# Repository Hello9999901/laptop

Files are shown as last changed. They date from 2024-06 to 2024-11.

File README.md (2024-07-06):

# anyon e

*also stylized as anyon_e*

A highly integrated, high end, open source laptop.

Mission: to disprove the idea that technology is either repairable and open or integrated and closed.

#

#### Planned Features:

- RK3588 SoC Motherboard
  - CM3588-based, up to 32GB of DDR5 2400MHz RAM
  - USB-C USB3.1 Gen 1 with DisplayPort
  - Separate USB-C PD controller and port
  - HDMI Input (maybe)
  - RP2040 embedded controller
- World's thinnest wireless mechanical keyboard
  - nRF52840 SoC
  - Cherry ULP switches
- 4K AMOLED 13.3" display
  - 330 pixels per inch
- Field-Oriented-Control BLDC input
- High accuracy trackpad
  - Azoteq Win 11 certified
- High performance battery
  - High discharge/charge ~60Wh Li-Po battery pack
- Anodized aluminum CNC chassis

#### Unplanned Features:

- 3.5mm headphone port
  - hardware support complexity
- webcam/microphone
  - privacy and system complexity
  - minimize screen bezel size

#

*[ **an**-yon ]*

*exotic particles whose quantum statistics are neither bosonic nor fermionic.*[^1]

Integrated like bosons, distinct like fermions.

#

Thank you to the Phillips Exeter Academy Science Department for supporting this project.
*Non Sibi. Knowledge and Goodness. Youth From Every Quarter.* [^2]

[^1]: H. Bartolomei et al. ,Fractional statistics in anyon collisions.Science368,173-177(2020).DOI:10.1126/science.aaz5601

[^2]: Byran Huang's ('25) 2024-25 Fall Term Senior Project. Thank you to my advisors, Mr. Brad Robinson and Mr. Charles Mamolo.

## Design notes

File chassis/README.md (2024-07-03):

# Chassis

Designed in PTC Onshape using an Educational license.

https://cad.onshape.com/documents/a18bb6df7dbba66df24a7ec8/w/967d921e60c207e3b6f5cf7b/e/1f78a9387b17c2d178742295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

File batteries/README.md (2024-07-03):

# Batteries

https://www.batteryspace.com/polymerli-ionmodule37v4250mah157wh85arate-prewiredwithpcbpl5467100.aspx

15.7Wh, 100mm (3.9")  x 67mm (2.6") x 5.7mm (0.2")

4S system, providing a total capacity of 62.8 Wh with a theoretical peak power draw of 118.4W (3.7V * 4 * 8A)

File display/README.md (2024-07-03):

# Display

Using the ATNA33TP11 13.3" 4K AMOLED display from Samsung.

https://www.panelook.com/ATNA33TP11_Samsung_13.3_OLED_overview_59424.html

The datasheet is very difficult to acquire.

eDP 40 pin connector: IPEX 20455-040E

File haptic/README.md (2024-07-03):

# Haptic

BLDC haptic feedback like smartknob.

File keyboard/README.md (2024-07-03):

# Keyboard

nRF52840-based wireless mechanical keyboard with Cherry ULP switches.

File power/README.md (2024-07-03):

# Power

Separate power system because integration is high risk.

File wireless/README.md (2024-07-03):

# Wireless

Looking at Intel's AX210 or RTL8852BE, assuming M.2 E Key connection is functional.

https://us.rs-online.com/product/okdo/ra007-a8/74063355/

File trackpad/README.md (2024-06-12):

# PXM0057-401-S

[Purchase Link (discontinued)](https://www.mouser.com/ProductDetail/Azoteq/PXM0057-401-S)

EOL'ed series of trackpads/touchpads from Azoteq. All documents are archived from Azoteq.

[Framework 16 trackpads](https://frame.work/products/16-touchpad-module) currently seem to be the only other option.

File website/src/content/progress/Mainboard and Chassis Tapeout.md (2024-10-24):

---
title: "Mainboard and Chassis Tapeout"
hash: "Hello9999901/laptop/commit/2902150bbe53c2a607e23ed8757f1257ed1819de"
dateStart: "10/24/2024"
---

Mainboard V1.0 and chassis has been taped out to JLCPCB and JLCCNC respectively. Will receive parts in ~1.5 weeks.

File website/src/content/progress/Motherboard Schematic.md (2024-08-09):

---
title: "Motherboard Schematic"
hash: "Hello9999901/laptop/commit/7537e6f6f953aed19e3b554f8151d0d517349e46"
dateStart: "7/8/2024"
---

Using a combination of the CM3588 NAS SDK, Radxa 5B, and Cool-Pi laptop schematic and the RK3588 Design Guide (all sources in repo) for reference to create the motherboard schematic.

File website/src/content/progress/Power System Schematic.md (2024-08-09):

---
title: "Power System Schematic"
hash: "Hello9999901/laptop/commit/9d0cacac59adbbebdd309e441b76d96aae04a213"
dateStart: "7/1/2024"
---

Still a work in progress. It will use the most advanced chips I can develop with and hopefully have a RP2040 EC (embedded controller) for system monitoring or as a general purpose embedded MCU.

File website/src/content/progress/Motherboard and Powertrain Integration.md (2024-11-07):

---
title: "Motherboard and Powertrain Integration"
hash: "Hello9999901/laptop/"
dateStart: "11/2/2024"
---

After load testing the batteries at 3A for ~2h, I plugged the powertrain into the motherboard and evaluated all previous functionality.

The hall switch, speakers, and fan have also been evaluated to be functional.

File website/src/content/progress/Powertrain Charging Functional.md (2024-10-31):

---
title: "Powertrain Charging Functional"
hash: "Hello9999901/laptop/commit/7e120f42460bdfba6e477f5982cce70f7909ddb4"
dateStart: "10/31/2024"
---

After fixing some (many) mistakes with the board, the powertrain charged a battery pack to ~4.18V per cell as expected.

The problems include:

- Used N-MOS for BATFET instead of P-MOS
- Battery pack voltage joined with system power
- Charge/Discharge FETs on battery balancing IC non-functional

I will send a fixed board to production, but I'm not sure if it'll arrive in time for the term deadline.

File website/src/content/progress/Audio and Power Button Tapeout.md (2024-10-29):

---
title: "Audio and Power Button Board Tapeout"
hash: "Hello9999901/laptop/commit/680bf61ffe4f14e42e2d671e997a2c2274b41c56"
dateStart: "10/29/2024"
---

After a one-night crunch, I put the audio board (CM108 USB to 2x TPA2028 with the legendary CH32V003 MCU) and a simple power button board into production. Since they're two layer, JLC can do 24h PCB + 2-3 day assembly so they should arrive quite quickly!

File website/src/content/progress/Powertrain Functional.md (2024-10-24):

---
title: "Powertrain Functional"
hash: "Hello9999901/laptop/commit/7c3f3c577cd7447728fc4ebcd25b6b98cf7af491"
dateStart: "10/23/2024"
---

Powertrain V0.2 powered on and functioned as expected first-try! Software evaluation with PlatformIO proved effective with all I2C ICs and the ESP32-S3-MINI-1-N8 itself.

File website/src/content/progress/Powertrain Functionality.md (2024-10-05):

---
title: "Powertrain Hardware and Software Verification"
hash: "Hello9999901/laptop/commit/7dd1f4d1e0136dbfb9b8b690ecb96abea7383cab"
dateStart: "10/5/2024"
---

Fixes need to be made on the second revision of the powertrain. Namely, a higher performance DC-DC converter and redesigning the ESP32-S3 setup.
Using a Teensy 4.1 to accelerate development times, all three chips have been verified to function as expected. Further testing needs to be conducted with charger IC.

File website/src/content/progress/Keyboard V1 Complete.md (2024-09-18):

---
title: "Keyboard V1 Complete"
hash: "Hello9999901/zmk/commit/ae88a136d7643904b9689bf2e2431af29ef1ffbc"
dateStart: "9/17/2024"
---

After ~0.5mm acetal delrin were installed underneath the keycaps and plates glued with cyanoacrylate adhesive (superglue), all the keycaps press and travel as expected. The delrin provides a softer and smoother bottom-out and just a tiny bit less travel. I can type on the keyboard normally, but the sizing and actuations require more typing to break-in.

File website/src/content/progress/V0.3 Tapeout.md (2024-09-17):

---
title: "V0.3 Tapeout"
hash: "Hello9999901/laptop/commit/1f0a15ddb97392ed5f131d0902316a7e9edddad4"
dateStart: "9/16/2024"
---

V0.3 with improved fixes has been taped out. A major issue is that the low-profile Hirose connectors are out of stock, so the board will be 1.5mm thicker if this board is final (unlikely).

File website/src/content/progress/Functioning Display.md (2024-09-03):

---
title: "Functioning Display"
hash: "Hello9999901/zmk/commit/fdd6672159e983177fd62d12f2ffced35667086c"
dateStart: "9/2/2024"
---

In the end, it seems like the culprit of the non-functional display was the hardware. Using the exact same devicetree compile and surrounding hardware setup, I was able to get the display running. In particular, the difficulties were most likely in the high-speed signaling losses across the SoM, the Hirose connectors, the HDMI connector, and the transition to the "anyon_e display evaluation" breakout board. The difference between V1 and V2 Short was the use of a male HDMI connector and the shortest signaling traces possible. This eliminated the need for a male-male HDMI conversion between the boards and shortened the FR4 trace lengths by around 2cm. That is -20% change from the pervious length. However, it looks like brightness control must be done over PWM, as (unfortunately predicted) adjusting the voltage does not result in a change in brightness. In my measurements (assuming default output is the stated 400 nits), the max current draw is around 0.5A at 12V, so a PWM brightness system should be implementable.

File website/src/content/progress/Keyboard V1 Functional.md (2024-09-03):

---
title: "Keyboard V1 Functional"
hash: "Hello9999901/zmk/commit/ae88a136d7643904b9689bf2e2431af29ef1ffbc"
dateStart: "8/8/2024"
---

After battling Linux DeviceTree development for the past weekend, I'm happy to say I am fluent in DTS code (jokes).

Currently forked from Joshua Reik's modified ubuntu-linux kernel. After modifying the CM3588 DTS to support eDP1, link training is failing. Currently debugging.

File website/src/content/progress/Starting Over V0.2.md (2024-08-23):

---
title: "Starting Over V0.2"
hash: "Hello9999901/laptop/commit/8de2bc9e0074f80b906bef1af565acf0b877c5ee"
dateStart: "8/21/2024"
---

After the display evaluation, I think I have a much better handle on high-speed signaling especially in relation to the CM3588. This new motherboard revision will be a near-final layout and close to the tape-out design.

I am paying special attention the integrity, coupling, and EMC of the board, so I've made the bold move for a 6 layer stackup - (Signal, GND, Power, Power, GND, Signal). I might use the first power plane for low speed signaling since the power requirements aren't that high.

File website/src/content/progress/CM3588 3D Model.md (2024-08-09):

---
title: "CM3588 3D Model"
hash: "Hello9999901/laptop/commit/bdd2ba21b4a4451552f4995764e1e13cb89fd671"
dateStart: "7/7/2024"
---

Created two 3D models of the CM3588 (non plus) SoM (system on module):
    1. Nearly fully accurate STL in Blender using the DXFs provided by FriendlyElec
    2. A roughly accurate STEP file in Shapr3D using the DXFs provided by FriendlyElec

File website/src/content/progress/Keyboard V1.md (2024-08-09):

---
title: "Keyboard V1"
hash: "Hello9999901/laptop/commit/2ca9aab1f80719315530f4c532aef9cafec064c8"
dateStart: "7/15/2024"
---

Trying to keep the entire keyboard assembly to be under 6mm at its highest point. This required designing a custom "BPS" (battery protection system) board and slots in the main PCB to save on the height of the BPS itself.

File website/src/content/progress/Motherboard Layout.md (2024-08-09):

---
title: "Motherboard Layout"
hash: "Hello9999901/laptop/commit/065d56bcbf0afe930ac8a8ca5442cbb30772766b"
dateStart: "7/16/2024"
---

Starting the motherboard's PCB layout! It will be a long journey and I will definitely end up revising the schematic many times over.

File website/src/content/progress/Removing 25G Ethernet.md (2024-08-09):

---
title: "Removed 2.5G Ethernet + Subtracting 38mm from the SSD"
hash: "Hello9999901/laptop/commit/3718073a7b3cd8b09f7a54d581c9525380008b53"
dateStart: "7/28/2024"
---

I have put a lot of thought into the sizing and overall integration of the system. As I was designing today, I realized that unless I increase the overall lower chassis thickness to around 17mm, it is impossible to fit an Ethernet connector (height of the connector would be 11.8mm + 1.6mm from PCB = 13.4mm). My aim for the system is still a sleek, integrated, and low-profile design. Unfortunately, I understand why Apple only includes USB-C for connectivity now.

Another tradeoff: With the feature set in mind, a 2280 SSD simply would not fit the vertical requirements. The exact reason is complicated: the keyboard limits the maximum height of the heatsink, meaning the heatpipes have to extend horizontally. The orientation of the CM3588 means that it is most optimal to route with tall components (SSD, wireless card, ribbon cables, etc.) all around it (rather than on one side). It is not that big of a loss, since it will still support 2242 and 2230 SSDs. The PCIe 3.0x4 is limited to 4GB/s, and the newest small-form-factor SSDs are much higher speed and will not be the performance bottleneck.

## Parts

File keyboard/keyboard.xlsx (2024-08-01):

Reference | Qty | Value | DNP | Exclude from BOM | Exclude from Board | Footprint | LCSC
C1,C4,C13,C19 | 4 | 4.7uF |  |  |  | Capacitor_SMD:C_0402_1005Metric | C23733
C2,C14,C15,C20 | 4 | 1uF |  |  |  | Capacitor_SMD:C_0402_1005Metric | C52923
C3 | 1 | 47nF |  |  |  | Capacitor_SMD:C_0402_1005Metric | C272875
C5 | 1 | 1nF |  |  |  | Capacitor_SMD:C_0402_1005Metric | C1523
C6 | 1 | 100pF |  |  |  | Capacitor_SMD:C_0402_1005Metric | C1546
C7,C16,C17,C18 | 4 | 100nF |  |  |  | Capacitor_SMD:C_0402_1005Metric | C307331
C8,C9,C21,C22 | 4 | 15pF |  |  |  | Capacitor_SMD:C_0402_1005Metric | C1548
C10 | 1 | 1.5pF |  |  |  | Capacitor_SMD:C_0402_1005Metric | C1552
C11,C12 | 2 | 1pF |  |  |  | Capacitor_SMD:C_0402_1005Metric | C1550
C23 | 1 | 10nF |  |  |  | Capacitor_SMD:C_0402_1005Metric | C15195
C24 | 1 | 1000pF/NC |  |  |  | Capacitor_SMD:C_0402_1005Metric
D1 | 1 | CHG |  |  |  | LED_SMD:LED_0603_1608Metric | C72038
D2 | 1 | B5819W SL |  |  |  | Diode_SMD:D_SOD-323 | C8598
D3 | 1 | BLUE |  |  |  | LED_SMD:LED_0603_1608Metric | C2290
D4,D5,D6,D7,D8,D9,D10,D11,D12,D13,D14,D15,D16,D18,D19,D20,D21,D22,D23,D24,D25,D26,D27,D28,D29,D30,D31,D32,D33,D34,D35,D36,D37,D38,D39,D40,D41,D42,D43,D44,D45,D46,D47,D48,D49,D50,D51,D52,D53,D54,D55,D56,D57,D58,D59,D60,D61,D62,D63,D64,D65,D66,D67,D68,D69,D70,D71,D72,D73,D74,D75,D76,D77,D78,D79,D80,D81,D82 | 78 | D |  |  |  | Diode_SMD:D_SOD-523 | C7420320
K1 | 1 | Esc |  |  |  | Cherry_ULP:Cherry_ULP_SMD
K2 | 1 | F1 |  |  |  | Cherry_ULP:Cherry_ULP_SMD
K3 | 1 | F2 |  |  |  | Cherry_ULP:Cherry_ULP_SMD
K4 | 1 | F3 |  |  |  | Cherry_ULP:Cherry_ULP_SMD
K5 | 1 | F4 |  |  |  | Cherry_ULP:Cherry_ULP_SMD
K6 | 1 | F5 |  |  |  | Cherry_ULP:Cherry_ULP_SMD
K7 | 1 | F6 |  |  |  | Cherry_ULP:Cherry_ULP_SMD
K8 | 1 | F7 |  |  |  | Cherry_ULP:Cherry_ULP_SMD
K9 | 1 | F8 |  |  |  | Cherry_ULP:Cherry_ULP_SMD
K10 | 1 | F9 |  |  |  | Cherry_ULP:Cherry_ULP_SMD
K11 | 1 | F10 |  |  |  | Cherry_ULP:Cherry_ULP_SMD
K12 | 1 | F11 |  |  |  | Cherry_ULP:Cherry_ULP_SMD
K13 | 1 | F12 |  |  |  | Cherry_ULP:Cherry_ULP_SMD
K15 | 1 | ~~,` |  |  |  | Cherry_ULP:Cherry_ULP_SMD
K16 | 1 | !,1 |  |  |  | Cherry_ULP:Cherry_ULP_SMD
K17 | 1 | @,2 |  |  |  | Cherry_ULP:Cherry_ULP_SMD
K18 | 1 | #,3 |  |  |  | Cherry_ULP:Cherry_ULP_SMD
K19 | 1 | $,4 |  |  |  | Cherry_ULP:Cherry_ULP_SMD
K20 | 1 | %,5 |  |  |  | Cherry_ULP:Cherry_ULP_SMD
K21 | 1 | ^,6 |  |  |  | Cherry_ULP:Cherry_ULP_SMD
K22 | 1 | &,7 |  |  |  | Cherry_ULP:Cherry_ULP_SMD
K23 | 1 | *,8 |  |  |  | Cherry_ULP:Cherry_ULP_SMD
K24 | 1 | (,9 |  |  |  | Cherry_ULP:Cherry_ULP_SMD
K25 | 1 | ),0 |  |  |  | Cherry_ULP:Cherry_ULP_SMD
K26 | 1 | _,- |  |  |  | Cherry_ULP:Cherry_ULP_SMD
K27 | 1 | +,= |  |  |  | Cherry_ULP:Cherry_ULP_SMD
K28 | 1 | Backspace |  |  |  | Cherry_ULP:Cherry_ULP_SMD
K29 | 1 | Tab |  |  |  | Cherry_ULP:Cherry_ULP_SMD
K30 | 1 | Q |  |  |  | Cherry_ULP:Cherry_ULP_SMD
K31 | 1 | W |  |  |  | Cherry_ULP:Cherry_ULP_SMD
K32 | 1 | E |  |  |  | Cherry_ULP:Cherry_ULP_SMD
K33 | 1 | R |  |  |  | Cherry_ULP:Cherry_ULP_SMD
K34 | 1 | T |  |  |  | Cherry_ULP:Cherry_ULP_SMD
K35 | 1 | Y |  |  |  | Cherry_ULP:Cherry_ULP_SMD
K36 | 1 | U |  |  |  | Cherry_ULP:Cherry_ULP_SMD
K37 | 1 | I |  |  |  | Cherry_ULP:Cherry_ULP_SMD
K38 | 1 | O |  |  |  | Cherry_ULP:Cherry_ULP_SMD
K39 | 1 | P |  |  |  | Cherry_ULP:Cherry_ULP_SMD
K40 | 1 | {,[ |  |  |  | Cherry_ULP:Cherry_ULP_SMD
K41 | 1 | },] |  |  |  | Cherry_ULP:Cherry_ULP_SMD
K42 | 1 | |,\ |  |  |  | Cherry_ULP:Cherry_ULP_SMD
K43 | 1 | Caps Lock |  |  |  | Cherry_ULP:Cherry_ULP_SMD
K44 | 1 | A |  |  |  | Cherry_ULP:Cherry_ULP_SMD
K45 | 1 | S |  |  |  | Cherry_ULP:Cherry_ULP_SMD
K46 | 1 | D |  |  |  | Cherry_ULP:Cherry_ULP_SMD
K47 | 1 | F |  |  |  | Cherry_ULP:Cherry_ULP_SMD
K48 | 1 | G |  |  |  | Cherry_ULP:Cherry_ULP_SMD
K49 | 1 | H |  |  |  | Cherry_ULP:Cherry_ULP_SMD
K50 | 1 | J |  |  |  | Cherry_ULP:Cherry_ULP_SMD
K51 | 1 | K |  |  |  | Cherry_ULP:Cherry_ULP_SMD
K52 | 1 | L |  |  |  | Cherry_ULP:Cherry_ULP_SMD
K53 | 1 | :,; |  |  |  | Cherry_ULP:Cherry_ULP_SMD
K54 | 1 | ",' |  |  |  | Cherry_ULP:Cherry_ULP_SMD
K55 | 1 | Enter |  |  |  | Cherry_ULP:Cherry_ULP_SMD
K56,K68 | 2 | Shift |  |  |  | Cherry_ULP:Cherry_ULP_SMD
K57 | 1 | Z |  |  |  | Cherry_ULP:Cherry_ULP_SMD
K58 | 1 | X |  |  |  | Cherry_ULP:Cherry_ULP_SMD
K59 | 1 | C |  |  |  | Cherry_ULP:Cherry_ULP_SMD
K60 | 1 | V |  |  |  | Cherry_ULP:Cherry_ULP_SMD
K61 | 1 | B |  |  |  | Cherry_ULP:Cherry_ULP_SMD
K62 | 1 | N |  |  |  | Cherry_ULP:Cherry_ULP_SMD
K63 | 1 | M |  |  |  | Cherry_ULP:Cherry_ULP_SMD
K64 | 1 | <,, |  |  |  | Cherry_ULP:Cherry_ULP_SMD
K65 | 1 | >,. |  |  |  | Cherry_ULP:Cherry_ULP_SMD
K66 | 1 | ?,/ |  |  |  | Cherry_ULP:Cherry_ULP_SMD
K67 | 1 | ‚Üë |  |  |  | Cherry_ULP:Cherry_ULP_SMD
K69 | 1 | Fn |  |  |  | Cherry_ULP:Cherry_ULP_SMD
K70 | 1 | Ctrl |  |  |  | Cherry_ULP:Cherry_ULP_SMD
K71,K76 | 2 | Alt |  |  |  | Cherry_ULP:Cherry_ULP_SMD
K72,K75 | 2 | Meta |  |  |  | Cherry_ULP:Cherry_ULP_SMD
K73,K74 | 2 | Space |  |  |  | Cherry_ULP:Cherry_ULP_SMD
K77 | 1 | ‚Üê |  |  |  | Cherry_ULP:Cherry_ULP_SMD
K78 | 1 | ‚Üì |  |  |  | Cherry_ULP:Cherry_ULP_SMD
K79 | 1 | ‚Üí |  |  |  | Cherry_ULP:Cherry_ULP_SMD
L1 | 1 | 15nH |  |  |  | Inductor_SMD:L_0402_1005Metric | C27143
L2,L3 | 2 | 10uH |  |  |  | Inductor_SMD:L_0603_1608Metric | C285968
L4 | 1 | 3.9nH |  |  |  | Inductor_SMD:L_0402_1005Metric | C14033
NT1 | 1 | NetTie_2 |  |  |  | Mikoto-Footprints:net-tie-2-tiny
P1 | 1 | USB-C |  |  |  | Connector_USB:USB_C_Receptacle_HRO_TYPE-C-31-M-12 | C165948
R1 | 1 | 0R |  |  |  | Resistor_SMD:R_0402_1005Metric | C17168
R2,R4 | 2 | 10k |  |  |  | Resistor_SMD:R_0402_1005Metric | C25744
R3 | 1 | 2.7k |  |  |  | Resistor_SMD:R_0603_1608Metric | C13167
R5 | 1 | 1.5k |  |  |  | Resistor_SMD:R_0402_1005Metric | C25867
R6,R7 | 2 | 5.1k |  |  |  | Resistor_SMD:R_0402_1005Metric | C25905
R8,R9 | 2 | 2M |  |  |  | Resistor_SMD:R_0603_1608Metric | C22976
R10 | 1 | 10M |  |  |  | Resistor_SMD:R_0402_1005Metric | C26082
R11 | 1 | 1M |  |  |  | Resistor_SMD:R_0402_1005Metric | C26083
SW1 | 1 | Reset |  |  |  | Button_Switch_SMD:SW_Push_1P1T_XKB_TS-1187A | C318884
U1 | 1 | BQ21040DBVR |  |  |  | BQ21040:SOT95P280X145-6N | C202311
U2 | 1 | nRF52840 |  |  |  | Package_DFN_QFN:Nordic_AQFN-73-1EP_7x7mm_P0.5mm | C190794
U3 | 1 | ESDR0502NMUTAG |  |  |  | Mikoto-Footprints:UDFN-6_1.2x1.0mm_P0.4mm | C327480
Y1 | 1 | 32.768 kHz |  |  |  | Crystal:Crystal_SMD_2012-2Pin_2.0x1.2mm | C99009
Y2 | 1 | 32MHz |  |  |  | Crystal:Crystal_SMD_2016-4Pin_2.0x1.6mm | C2965584

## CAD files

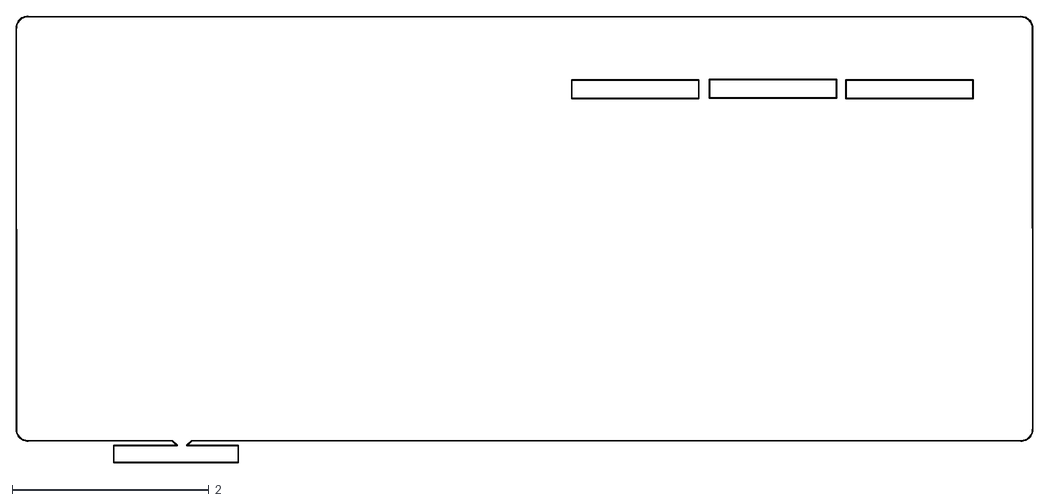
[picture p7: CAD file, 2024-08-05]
keyboard/dxf/keyboard-Edge_Cuts.dxf
10.3 x 4.54

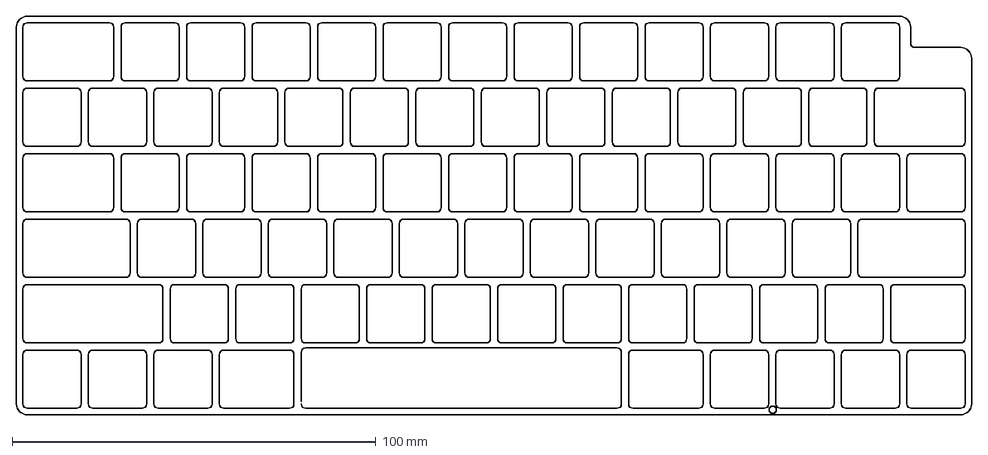
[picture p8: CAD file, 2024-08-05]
keyboard/plate files/anyon_e kb top AI TAPEOUT.dxf
262.5 x 109.5 mm

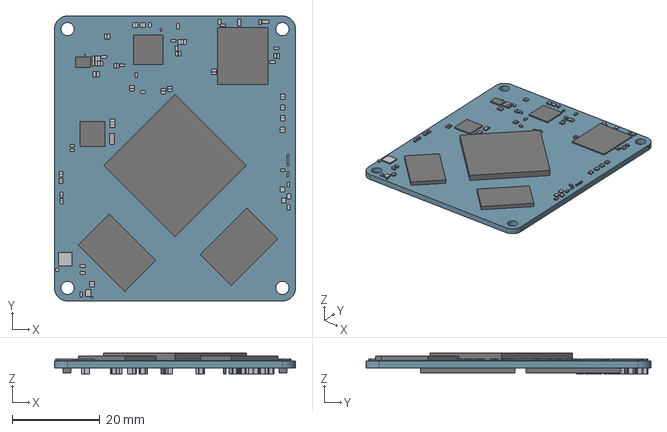
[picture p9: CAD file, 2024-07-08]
motherboard/CM3588 3D/CM3588_3D.step
55.0 x 65.0 x 4.70 mm

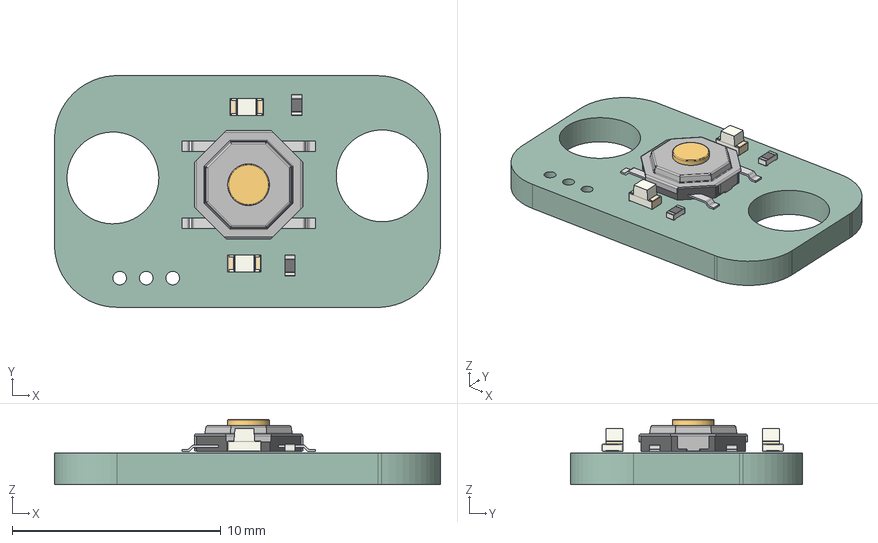
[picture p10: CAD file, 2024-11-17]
switch/switch.step
18.5 x 11.1 x 3.13 mm
SW_SPST_TL3342
R_0402_1005Metric x 2
LED_0603_1608Metric x 2
switch_PCB

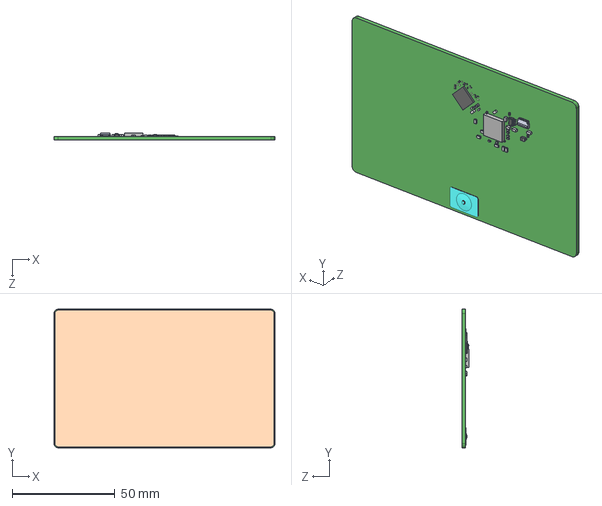
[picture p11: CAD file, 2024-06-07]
trackpad/pxm0057_101_201.STEP
107.3 x 67.3 x 3.47 mm

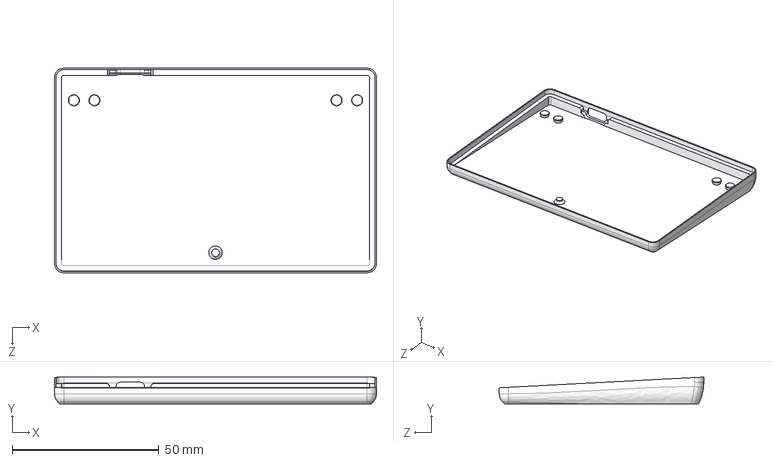
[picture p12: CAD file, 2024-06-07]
trackpad/PXM0057_Sales_Demo_3DPrinting/PXM0057_PTP_Type-C_Housing.STEP
109.7 x 9.16 x 69.7 mm

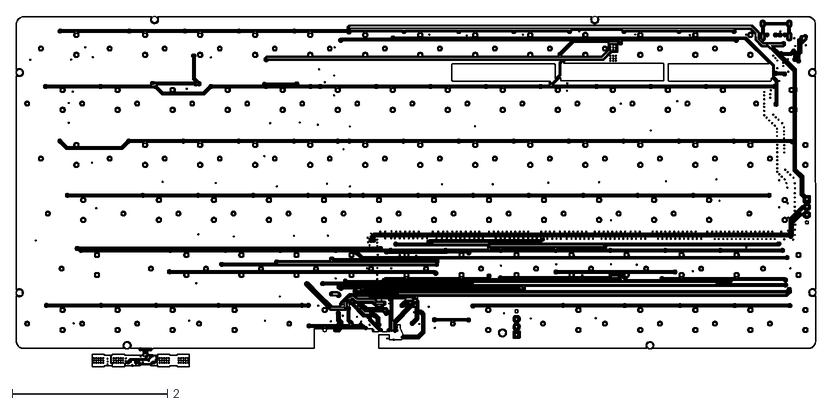
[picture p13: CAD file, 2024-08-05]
keyboard/dxf/keyboard-B_Cu.dxf
10.3 x 4.51

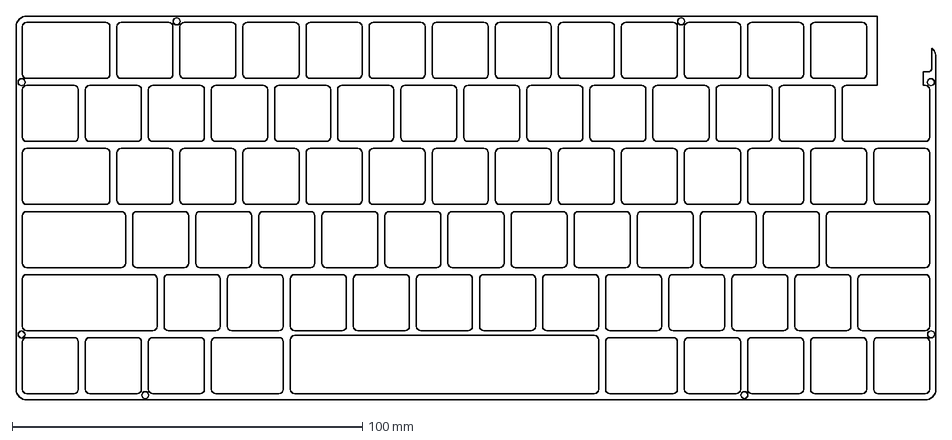
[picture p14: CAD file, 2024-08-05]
keyboard/plate files/anyon_e kb top center AI TAPEOUT.dxf
262.5 x 109.5 mm

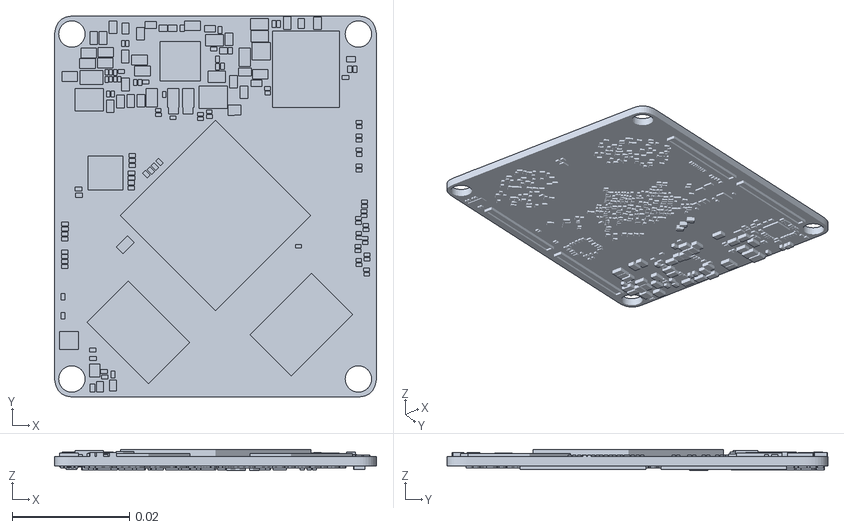
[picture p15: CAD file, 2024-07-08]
motherboard/CM3588 3D/CM3588.stl
0.055 x 0.065 x 0.00366

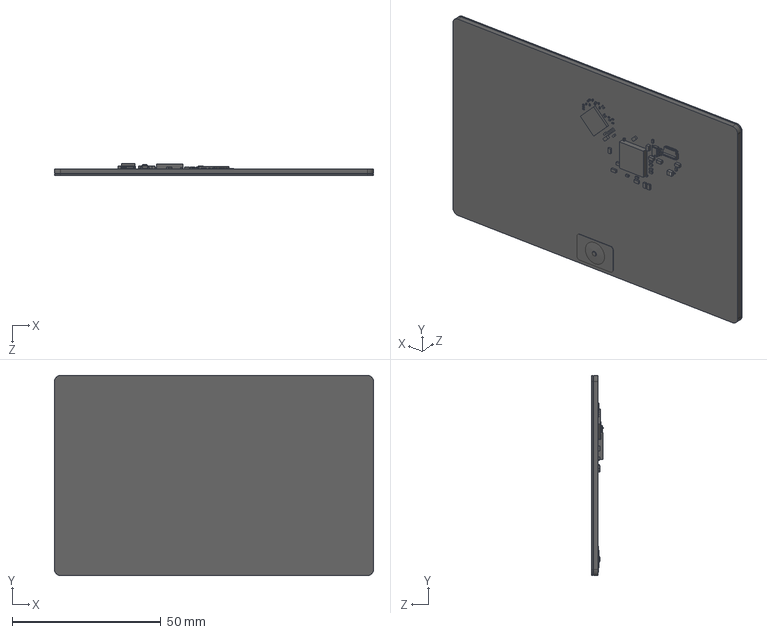
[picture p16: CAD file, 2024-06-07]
trackpad/pxm0057_301.STEP
107.3 x 67.3 x 3.87 mm

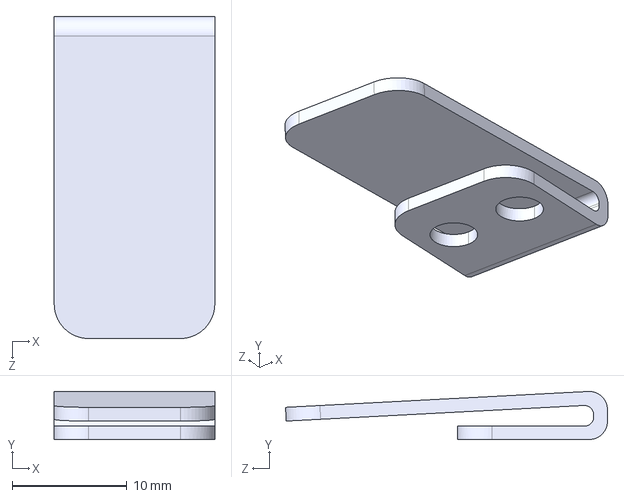
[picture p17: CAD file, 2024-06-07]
trackpad/PXM0057_Sales_Demo_3DPrinting/PXM0057_PTP_Pivot_Clip.STEP
14.0 x 4.19 x 28.1 mm

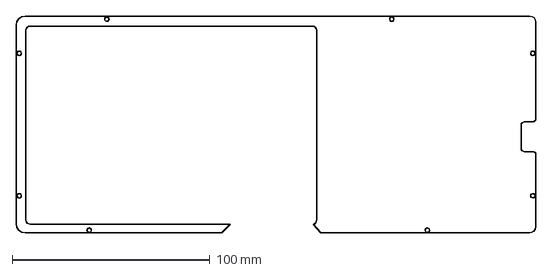
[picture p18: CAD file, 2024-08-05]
keyboard/plate files/anyon_e kb bottom AI TAPEOUT.dxf
262.6 x 109.6 mm

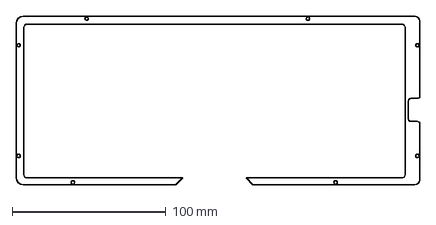
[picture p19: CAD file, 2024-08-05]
keyboard/plate files/anyon_e kb bottom center AI TAPEOUT.dxf
262.6 x 109.6 mm

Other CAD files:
keyboard/dxf/keyboard-B_Mask.dxf
keyboard/dxf/keyboard-B_Paste.dxf
keyboard/dxf/keyboard-B_Silkscreen.dxf
keyboard/dxf/keyboard-F_Mask.dxf
keyboard/dxf/keyboard-F_Paste.dxf
keyboard/dxf/keyboard-F_Silkscreen.dxf
motherboard/CM3588 3D/CM3588.obj
trackpad/PXM0057_Sales_Demo_3DPrinting/PXM0057_PTP_Pivot_Clip.3MF
trackpad/PXM0057_Sales_Demo_3DPrinting/PXM0057_PTP_Pivot_Clip.STL
trackpad/PXM0057_Sales_Demo_3DPrinting/PXM0057_PTP_Type-C_Housing.3MF
trackpad/PXM0057_Sales_Demo_3DPrinting/PXM0057_PTP_Type-C_Housing.STL

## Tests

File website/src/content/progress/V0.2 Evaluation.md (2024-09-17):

---
title: "V0.2 Evaluation"
hash: "Hello9999901/laptop/commit/e668e15a55f0dec9549ea40f140bceb5342f6468"
dateStart: "9/17/2024"
---

After much debugging (FB pin mishap, flipped TVS diode, etc.), the anyon_e supports the 4K OLED display and a USB-C display simultaneously, playing YouTube videos on both displays. Hardware bringup is required for additional peripherals.

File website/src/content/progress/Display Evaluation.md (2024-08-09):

---
title: "Display Evaluation Board"
hash: "Hello9999901/laptop/commit/1e2020f9cffc19e67713a248c328466f7556cfd8"
dateStart: "7/31/2024"
---

This is the first board being set out to production. I was thinking very hard last night and decided it was safer to evaluate eDP and DP before setting forward. This board includes all the high frequency RF knowledge I've learned this summer to provide as comprehensive of an evaluation as possible.

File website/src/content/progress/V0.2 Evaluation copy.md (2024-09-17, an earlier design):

---
title: "Power Board Design"
hash: "Hello9999901/laptop/commit/0589034f6b55c34b07c0b95747eeb858fee3d180"
dateStart: "9/17/2024"
---

The power board is nearing completion. The batteries are arriving soon through Fedex (class 9 hazardous material) and the power board will be taped out later this week.

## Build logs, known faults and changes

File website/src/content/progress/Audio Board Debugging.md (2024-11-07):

---
title: "Audio Board Debugging"
hash: "Hello9999901/laptop/"
dateStart: "11/7/2024"
---

The audio board's TPA2028 amplifier does not seem to be strong enough to drive the board. I don't have enough experience with audio systems to offer a full explanation though. The CM108B is enough to drive the board at a reasonable volume (around 25% of M3 MacBook Pro, although quality is lower).

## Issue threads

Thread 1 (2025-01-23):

Chassis link broken

webprofusion-chrisc, 2025-01-23:
Hi,

Thanks for such an inspiring project!

Browsing the files the Chassis CAD files link return http 403 forbidden and it would be ideal if they could be included directly in the github repo instead (file size permitting): https://github.com/Hello9999901/laptop/blob/main/chassis/README.md

Hello9999901, 2025-01-23:
Thanks! Apologies that the link broke. I just fixed it. Unfortunately the file's far too large to have everything in the repo. Thanks for the understanding!

jakeogh, 2025-03-07:
I am likely missing it, but when I click on the OnShape link in https://github.com/Hello9999901/laptop/blob/main/chassis/README.md I dont see a way do download the file. Is it possible?

TY! Amazing project. I would love to see it continue.

Closed 2025-01-23.

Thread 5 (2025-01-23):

type mismatch in `readRegister`

manitofigh, 2025-01-23:
`readRegister` [located here](https://github.com/Hello9999901/laptop/blob/4d6f3ee30fb1974e04df6e1ac50be64d17ce116a/ec/src/main.cpp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) promises a return of 16 bits, but based on [Arduino's docs](https://docs.arduino.cc/language-reference/en/functions/communication/wire/read/), something like `Wire.read()` returns 8 bits.

I don't have the hardware to test the code changes required, but if you think the type mismatch could be problematic, it's worth looking into.

Mani

Hello9999901, 2025-01-23:
A miscomment on my end. the code works fine. thanks.

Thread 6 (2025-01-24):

Touchscreen

fire17, 2025-01-24:
Sup! Saw you on YouTube... Awesome build 🔥

Would love for a 17inch touchscreen
Is that a thing ??

Have a good one & All the best!

Hello9999901, 2025-01-24:
Sure, you can build it yourself! The 40 pin eDP is OLED for now, but you can do a standard LCD. A touchscreen would definitely bring about a lot more complexity in terms of devicetree hw bringup though. I wouldn't see why not! Thanks.

Closed 2025-01-24.

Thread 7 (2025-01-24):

Question about ESP32

Danct12, 2025-01-24:
I saw your video on the laptop and liked it (currently daily driving an Orange Pi 5).

I noticed that the battery controller (powertrain) is on an ESP32 module which is overkill. Is there another plan for it?

Hello9999901, 2025-01-24:
Hey thanks for the question! I use an ESP32-S3 module because it's 1. easily assembled by JLCPCB and super super cheap (like 2 dollars each) 2. super powerful and flexible pin arrangements (if i messed up the pin assignments, i get leeway) 3. wireless (if there was more time, i would've done wireless monitoring and power on/off) 4. easily available and well-known. To be fair, any other option for MCU would've been possible (RP2040, nRF52x/53x/54x, ATMegas, etc.).

I'm leaving this project as-is for the foreseeable future. Maybe when I get off school I'll improve it :).

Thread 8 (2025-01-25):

Questions about HID over I2C, Audio, etc.

DefenestratingWizard, 2025-01-25:
Nice video, few questions:
- Are you aware of HID over I2C? It seems like it might be useful as its one of the main protocols modern touchscreens/touchpads on laptops use (could potentially make finding replacement touchpad easier and make keyboard docking smoother).
- Have you done anything special with the audio DSP? Asahi linux has some examples that might be good to hack on for smartamp (speakersafetyd), dsp, perceptual bass enhancement (bankstown)
- Glad to see someone adding a gas gauge chip (coulomb counter) on their diy battery pack, are you aware of the smbus battery standard? Implementation might allow off the shelf batteries to work with your laptop (this may understandably provide space constraint issues)
- I can't seem to find your device tree source files/firmware files, are they in another repo?
- How much did this all cost to build?

About trackpads:
If you are ever interested in custom multitouch surfaces I'd highly reccomend looking into projected capacitive touch sensing, its a bit trippy but its basically row column matrix scanning with capacitive sensing techniques.

Sorry for the ramble, I really like your project and love seeing people make these kind of polished devices, and want to see this maybe become more popular.

Hello9999901, 2025-02-06:
Hey, thanks for the question:
- I am aware of HID over I2C. However it's a complicated protocol that I did not have the bandwidth to work with. Also in keeping with the open source spirit, I didn't want to use an obscure end of I2C when USB sufficed.
- No. The speakers sound horrible anyways, and I'm not an audio engineer (I hope to get better). I keep up with Asahi Linux news, but again it's not within the scope of this project. Maybe in the future.
- I am aware of the smbus protocol. Again, this comes down to personal taste. I wanted to stick with protocol that a non laptop-focused engineering would know. Off the shelf batteries face bigger issues: undocumented SMBUS, and even worse, finding a connector that works. I also wanted the challenge of managing the packs. Same with every other part of the system — you learn the most from doing stuff yourself.
- DTS is in my linux fork. Powertrain FW is in this repo under "ec". ZMK FW is in my fork of ZMK. The keyboard bootloader is imported as a module in this repo (Adafruit nRF52). Sorry it's all over the place. I separate based on what was easiest for me to work on as separate pieces. Adding a whole linux kernel to this monorepo would've made it much heavier to work with. Same with ZMK.
- Around 5000 USD of research and development. Price to build would be around 1500 or less.

I'm aware of the trackpad market. Thanks for the tip! I do work with human interface devices + ZMK.

I appreciate your comments. I wish you the best! Thanks again.

Closed 2025-02-06.

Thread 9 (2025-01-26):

Questions about Booting and Power Management

0x0000ff, 2025-01-26:
Hello there,

This is a great project. I very much look forward to future developments of this.

Regarding this project, what is the plan for booting other OS's and power management? Will you be writing a new embedded controller firmware or use an existing one like the Chromium EC, and will it be used to control things like brightness and power management like it's done on typical laptops? Do you still want to use u-boot with device tree, or will you want acpi and uefi?

Thanks,

Hello9999901, 2025-02-06:
Hey! Thanks for the interest. This is considered a finalized project in my books. I don't plan on working on anyon_e any further beyond polishing the documentation. I am considering future laptops where Chromium EC and UEFI might be implemented.

Closed 2025-02-06.

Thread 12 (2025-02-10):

how to build by others?

nauen, 2025-02-10:
Hey Byran,

I really like this project from you.
I'm asking myself what is necessary to build this device for random people.
Also I'm not sure if you finished the design. The speaker(?) looks like loose at the side?

For a random person, it would be necessary to order all these PCBs from JCL and shopping the other parts like Display.

Do you have a packing list for the parts? BOM List etc. for ordering the PCBs?

We could also chat about it.

Thanks Paul

Hello9999901, 2025-02-20:
Hello Paul,

It's a finished design! However, I do not have a build guide and do not plan on doing so. It's quite difficult to build and documenting it would be nearly impossible with all the subtle steps needed since I didn't design it to be reproducible. In future revisions (if they end up happening), I certainly plan on doing so.

https://docs.google.com/spreadsheets/d/17arbJvPqW6koqEJwAzne7z5z2sndyQx2O3cI5NKfjhY/edit?usp=sharing

I have an R&D list though, if that helps!

All the PCBs should be readily order-able. Some still have flaws I haven't fixed yet, but nothing horrifically wrong!

Thank you for the interest!

Sincerely,
Byran

Closed 2025-02-20.

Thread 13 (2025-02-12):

How to download the CAD of the chassis

Magniflex99, 2025-02-12:
How can I download the 3D model of the Chassis from OnShape?

Hello9999901, 2025-02-20:
It should be ready to go now! Just changed the permissions and sorry for the late response.

Closed 2025-02-20.

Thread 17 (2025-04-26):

Hi

arfeenmushtaq, 2025-04-26:
Hi,
  Saw your project, looks good. I was wondering, why design a whole new arm based board, while we can use a mobile device board or a raspberry pi as a main board & start from there, making the laptop more plug and play then dependent upon customized parts

Regards,

Khan

Hello9999901, 2025-04-27:
Haha just lots of luck and figuring things out. You got it man!

Closed 2025-04-27.

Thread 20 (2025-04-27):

BUG: possible typo?

4kh00, 2025-04-27:
On https://www.byran.ee/posts/creation, it is stated that for the mainboard, you were aiming for a width ">90mm". I think it would be "<90mm" (i.e. _less than_ 90 mm).

byrantech, 2025-05-03:
Thanks! Lemme fix that!

Closed 2025-05-03.

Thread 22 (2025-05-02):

Serious issues regarding performance, stabililty and safety

souldbminersmwc, 2025-05-02:
Hello! I am an experienced enthusiast who does microsoldering and I have some stuff to tell you
1. The laptop will fail as there is not adequate cooling, which will make the solder balls under the RK3588 brittle and make them crack (Connecting the CPU directly with the mainboard with BGA would help here)
2. The batteries have no room to expand in case of manufacturing defect
3. The battery in the keyboard is not well protected against physical damage
4. The keyboard being placed so close to the heat generating components will cause stress on keyboard battery and might cause the PLA keycaps to warp
5. The batteries are not protected against the thermal environment of the laptop
6. The CPU is not shielded well from RF interference from the PSU
There might be more which I missed but these are really critical flaws with the design

byrantech, 2025-05-03:
Hey! I'll explain:
1. There is adequate cooling. The max power output of the entire system is around 16.8V @ 1A, so nothing more than 20W. With the solid aluminum heatsink, heatpipe and active cooling all conducted with PTM7950 phase change compound, the system remains under 50˚C at all times (if anything, I over-engineered the cooling system). Furthermore, the thermal throttling of the system would limit any damage. If anything, placing the SoC on the SoM reduces deflection in the PCB compared to a full sized mainboard.
2. If you cross-section the CAD, you'll see there's lots of room. I left a few mm in each direction.
3. That's an intentional decision on my part. This is not a product, so I decided to simplify the internal design and demonstrate the beauty (or lackthereof) of the internals.
4. The glass transition of PLA is 60˚C. If you look at the cross-section of the CAD, no heat generating component makes direct contact with the keyboard. Air's a good thermal insulator! The keyboard remains cool to the touch at all times even from playing bedwars for a few hours haha
5. Please refer to 1.
6. I'm not claiming any expertise in RF engineering, but I've done my fair share of it from GHz BLE transmission to THz chip research. There's no notable RF output from the power board other than switching conversions on the charging chip which are very near-field and the 2.4GHz from the ESP32-S3 which is <21 dBm EIRP at most. The ESP32's radio isn't enabled anyways in firmware. This would be a consideration if mains voltage were being processed by the laptop, but the only power inputs are either DC from USB-C PD or DC from the batteries.

In designing anyon_e, I've considered the issues you've outlined. I'm not claiming to have solved them (far from it), but they were important concerns that heavily influenced my system design.

souldbminersmwc, 2025-05-03:
50C is still high for LiPo batteries. They should stay at max 40c.
Another thing - The SoC isn't corner bonded to the SoM. It can fail quite easily with a sudden jolt or some pressure (This is the same thing which happens to the Nintendo Switch, causing a blue screen, Trust me, it's a pain to repair)

byrantech, 2025-05-03:
Hello,
50˚C is SoC temp. Air is a good thermal insulator so the batteries stay slightly above ambient.
The latter is not a major consideration. If the BGA is cracking, then there's a much larger issue at play with the overall structural design of the laptop.

I agree with all the considerations you suggest, but please remember this is an open source project, rather than a product that needs to meet certifications and be mass-produced. Going forwards, I hope your issues (and any other issues) are with re-producible errors or flaws in their own anyon_e/modified design rather than speculations. Thank you.

souldbminersmwc, 2025-05-22:
Even if it is an open source project, I would still place kapton tape over the heatsink and also the battery in the keyboard is highly unsafe. Even a tiny dent in a shell that thin could cause a fire

Closed 2025-05-03.

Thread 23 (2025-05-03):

Consider including the chassis CAD files on the project.

Kreijstal, 2025-05-03:
I do realize, I can myself download the step files from the link in the readme, this is true, but it is still "just" a link, and it can go anytime, this is for future-proofing, archival purposes.
We never know when onshape will go down, and make this data unrecoverable.

Thank you.

vasyahacker, 2025-05-06:
Current link to the chassis CAD files is broken.

Kreijstal, 2025-05-06:
> Current link to the chassis CAD files is broken.

It was only a matter of time hehe

Kreijstal, 2025-05-06:
@vasyahacker try this, since it seems there was no response from mantainers
[chassis.step.zip](https://github.com/user-attachments/files/20053217/chassis.step.zip)

byrantech, 2025-05-22:
Hey, yes I'll add one when I get time. Thanks!

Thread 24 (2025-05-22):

POWER Module Programing

jayatej, 2025-05-22:
Using Github link I was able to get a circuit printed and assembled with PSBWAY.

I am unable to get the board connected using the USB Data line of the usb (J2) to be able to program the ESP32. looking for help how to connect it to my  #PC/Mac to program.

I am connecting the FFC to a USB C to program.

Below are the Files used for printing

[pos.zip](https://github.com/user-attachments/files/20396932/pos.zip)
[power.csv](https://github.com/user-attachments/files/20396933/power.csv)
[Power.zip](https://github.com/user-attachments/files/20396934/Power.zip)
[reneedcentroidfilesforordert1n6w892767a.zip](https://github.com/user-attachments/files/20396931/reneedcentroidfilesforordert1n6w892767a.zip)

Reference Photos of the finished circuit

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

Unsure if this is a Driver issue or a Bad circuit.

jayatej, 2025-05-22:
thank you i will check, I Connected the Board to the a Power brick (20V) and verifies the  the voltage going to the ESP32 is 3.3V, but the ESP doesn't get detected.

I had the board made in March, should have the updated schematics

wondering if the batteries will need to be connected as well?

byrantech, 2025-05-22:
In what way does it not get detected? For example does `lsusb` on a UNIX system show anything? I can't verify the wiring for the FPC through the pictures. Is that correct? I used USB-A instead of USB-C since every computer seems to implement it differently and I wanted to eliminate failure points but it shouldn't theoretically matter.

jayatej, 2025-05-22:
The FPC is connect to a Usb Break out as so. i verified the continuity.

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

But when i connect the Usb C to the UNIX system i don't see an connection in the system (I also verified this on a windows machine machine don't see it detected in the device manage)

I will also try with a USB A break out and try it. and keep you posted.

I immensely thank your for your support.

byrantech, 2025-05-23:
Good to hear! The EC code handles the PD negotiations, https://github.com/byrantech/laptop/blob/daf2680bc3b2df92b7dabc01dc26063354dca1b1/ec/src/main.cpp#L178
It's 20V by default, so there might be some hardware differences in the system if your physical measurements don't line up. If I recall correct the VOLT is the battery voltage, so ~4.2*4=16.8V which is correct.

Closed 2025-05-23.

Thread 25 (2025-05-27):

Out put Power

jayatej, 2025-05-27:
I have two issues. any help is greatly appreciated

1. while connected to a 20V PD, the Rev 2 Power Board. the output is16.3V How do i change the out of the Power Board to 20V.

 2. Once the charge is disconnect the power drops to 3.7V. How to i make the Power Board stay on?

P.S. i am using the power Board as a standalone Mini PC charger/UPS supply.

byrantech, 2025-05-27:
1. You can't have 20V output. The maximum is the charge voltage of the batteries, 16.8V. You see 16.3, and I think that's probably due to the balance monitor IC's mosfets doing weird stuff.
2. I think that's likely the balance monitor's low side mosfets doing stuff. I took them out, and it worked; I couldn't figure out what the problem was under the time limitations.

I have to warn you that working with charging high power li-ion cells is very dangerous, and I do not provide any binding warranty or support to anything of this project. Thank you for understanding, and good luck!

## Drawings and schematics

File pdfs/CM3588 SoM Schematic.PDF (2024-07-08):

5

4

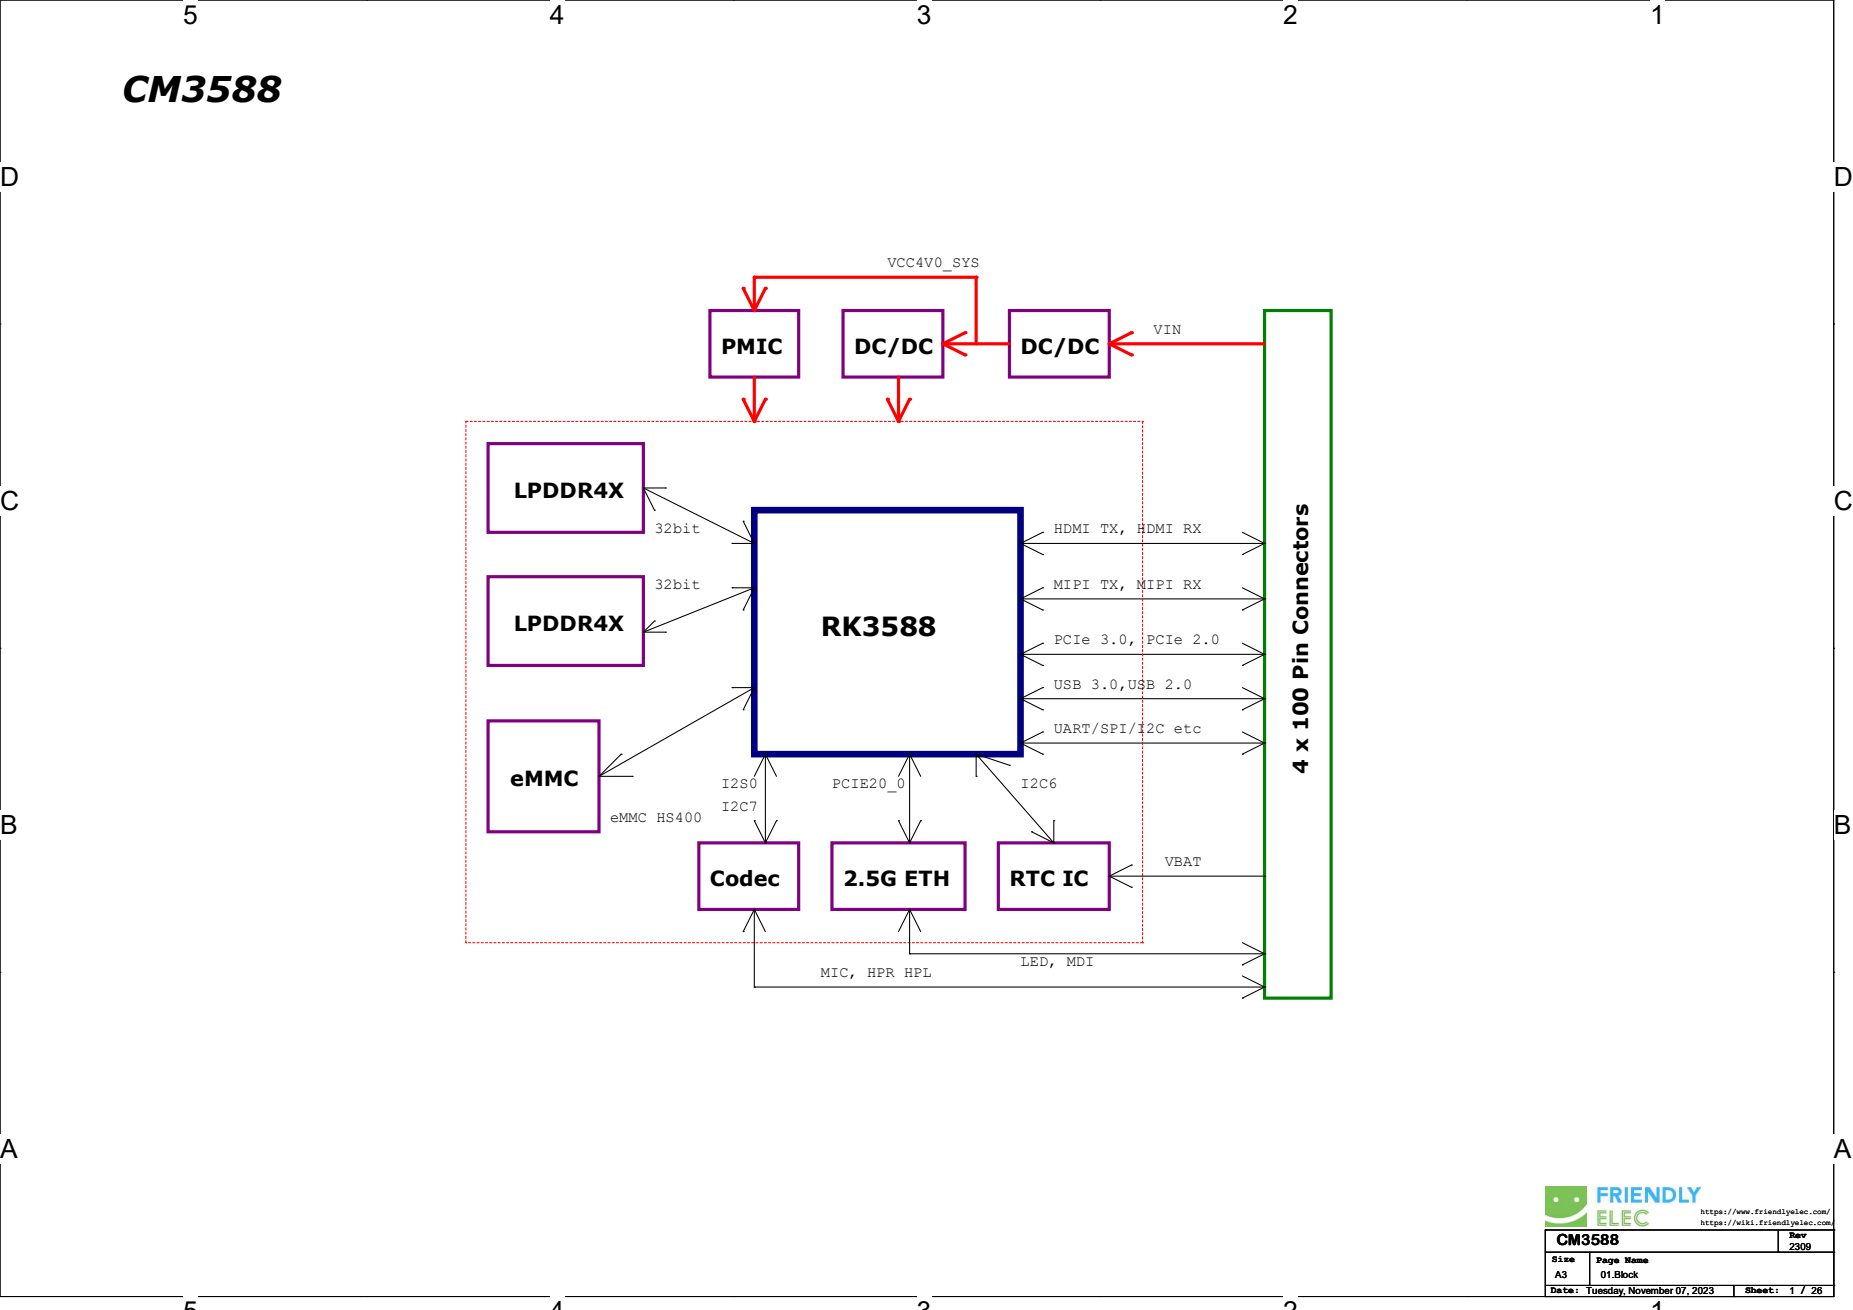
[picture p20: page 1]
LPDDR4X; eMMC; RTC IC; PMIC; 4 x 100 Pin Connectors; Codec; 2.5G ETH; VIN; 32bit; eMMC HS400; VCC4V0_SYS; PCIE20_0; VBAT; LED, MDI; USB 3.0,USB 2.0; PCIe 3.0,; PCIe 2.0; https://www.friendlyelec.com/ 1; Tuesday, November 07, 2023; 01.Block CM3588; Rev

HDMI TX, HDMI RX

MIPI TX, MIPI RX

UART/SPI/I2C etc

MIC, HPR HPL

https://wiki.friendlyelec.com/

Rev 2309

Size | Page Name

Date: | Sheet: /

# Power Tree

## 5~20V_DCIN

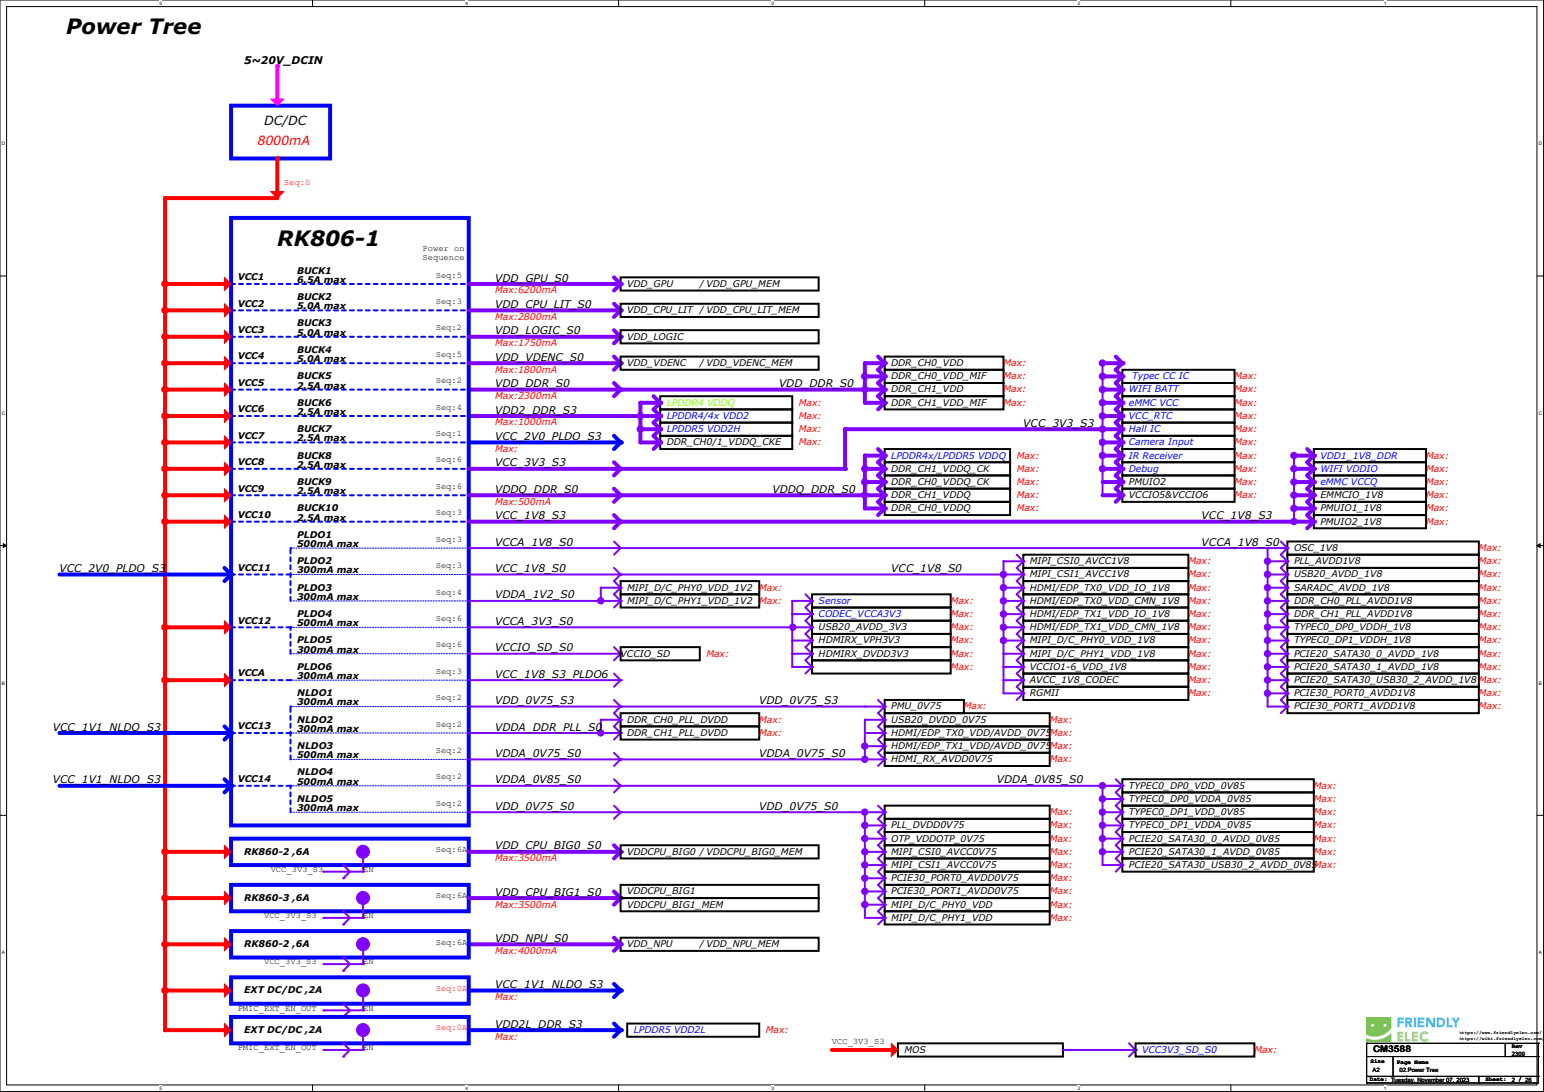
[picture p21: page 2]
DDR_CH0_VDD_MIF; DDR_CH0_VDD; DDR_CH1_VDD_MIF; DDR_CH1_VDD; VCC_3V3_S3; Max: Max: Max: Max:; DDR_CH0/1_VDDQ_CKE; Power on Sequence; Seq:3; Seq:5; LPDDR4/4x VDD2; LPDDR4 VDDQ Seq:2; VCC1; BUCK3 5.0A max; BUCK4 5.0A max; BUCK1 6.5A max; VCC2; BUCK2; 5.0A max; VCC3; VCC4; Seq:4; Seq:2; Seq:1; VCC5; BUCK7 2.5A max; BUCK8; Max:; 2.5A max; BUCK5 2.5A max; VCC6; BUCK6; VCC7; VCC8; Seq:6; BUCK9 2.5A max; VCC9; Seq:3 BUCK10 VCC10; PLDO1 500mA max; VCC11; PLDO2; 300mA max; PLDO3; VCC12; PLDO4; 500mA max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

DC/DC Seq:0

Typec CC IC
WIFI BATT
eMMC VCC
VCC_RTC
Hall IC
Camera Input
IR Receiver
Debug
PMUIO2

# Power Sequence

Power Supply | PMIC Channel | Supply Limit | Power Name | Time Slot | Default Voltage | Default ON/OFF | Sleep ON/OFF | Peak Current | Sleep Current

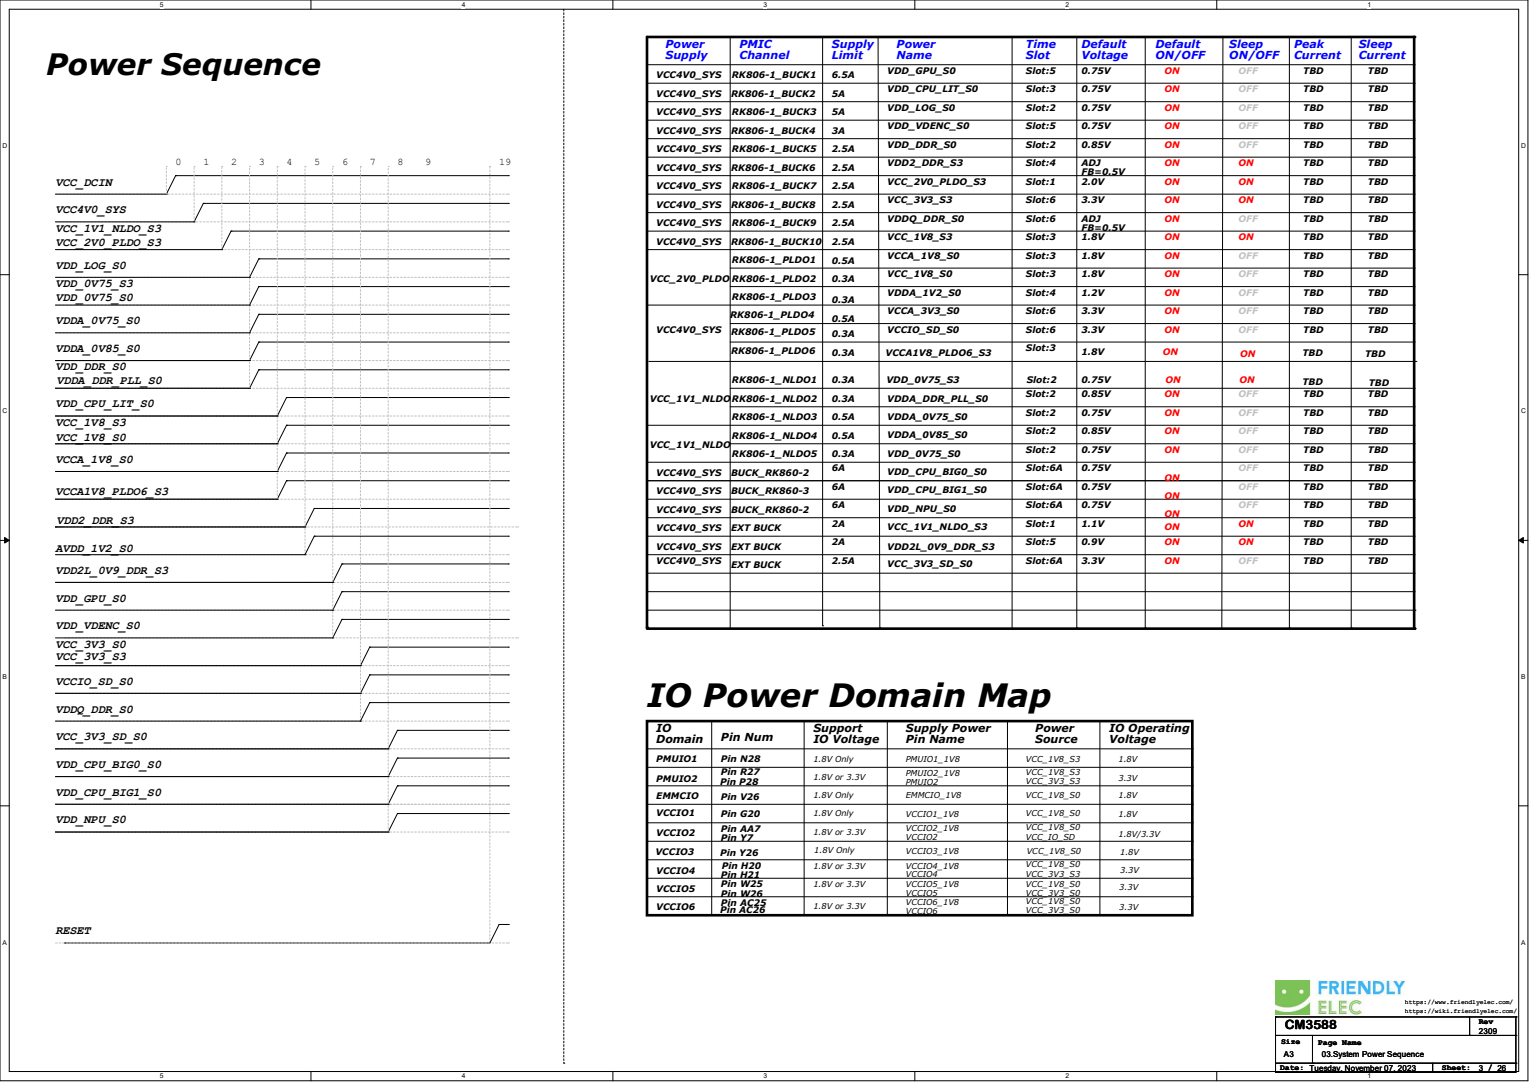
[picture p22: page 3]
VDDA_0V75_S0; VDD_DDR_S0; TBD TBD; TBD; RK806-1_BUCK5; RK806-1_NLDO3; VCC4V0_SYS; OFF; IO Domain; Supply Power; Pin Num; Pin Name; PMUIO1; IO Operating Voltage; Power Source; Support IO Voltage; Pin N28; PMUIO1_1V8; VCC_1V8_S3; PMUIO2; EMMCIO; VCCIO1; VCCIO2; VCCIO4; VCCIO5; VCCIO6; PMUIO2_1V8 PMUIO2 EMMCIO_1V8; VCCIO1_1V8 VCCIO2_1V8 VCCIO2; VCCIO4_1V8 VCCIO4 VCCIO5_1V8 VCCIO5; VCCIO6_1V8; VCC_1V8_S3 VCC_3V3_S3 VCC_1V8_S0; VCC_1V8_S0 VCC_1V8_S0; Pin P28; Pin R27; Pin V26; Pin Y7; Pin AA7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

VCC4V0_SYS | RK806-1_BUCK1 | 6.5A | VDD_GPU_S0 | Slot:5 | 0.75V | ON | OFF | TBD | TBD
VCC4V0_SYS | RK806-1_BUCK2 | 5A | VDD_CPU_LIT_S0 | Slot:3 | 0.75V | ON | OFF | TBD | TBD
VCC4V0_SYS | RK806-1_BUCK3 | 5A | VDD_LOG_S0 | Slot:2 | 0.75V | ON | OFF | TBD | TBD
VCC4V0_SYS | RK806-1_BUCK4 | 3A | VDD_VDENC_S0 | Slot:5 | 0.75V | ON | OFF | | TBD

VCC4V0_SYS | RK806-1_BUCK6 | 2.5A | VDD2_DDR_S3 | Slot:4 | ADJ FB=0.5V | ON | ON | TBD | TBD
VCC4V0_SYS | RK806-1_BUCK7 | 2.5A | VCC_2V0_PLDO_S3 | Slot:1 | 2.0V | ON | ON | TBD | TBD
VCC4V0_SYS | RK806-1_BUCK8 | 2.5A | VCC_3V3_S3 | Slot:6 | 3.3V | ON | ON | | TBD
VCC4V0_SYS | RK806-1_BUCK9 | 2.5A | VDDQ_DDR_S0 | Slot:6 | ADJ FB=0.5V | ON | OFF | | TBD
VCC4V0_SYS | RK806-1_BUCK10 | 2.5A | VCC_1V8_S3 | Slot:3 | 1.8V | ON | ON | TBD | TBD
VCC_2V0_PLDO | RK806-1_PLDO1 | 0.5A | VCCA_1V8_S0 | Slot:3 | 1.8V | ON | OFF | | TBD

RK806-1_PLDO2 | 0.3A | VCC_1V8_S0 | Slot:3 | 1.8V | ON | OFF | | TBD
RK806-1_PLDO3 | 0.3A | VDDA_1V2_S0 | Slot:4 | 1.2V | ON | OFF | TBD | TBD

VCC4V0_SYS | RK806-1_PLDO4 | 0.5A | VCCA_3V3_S0 | Slot:6 | 3.3V | ON | OFF | TBD | TBD

RK806-1_PLDO5 | 0.3A | VCCIO_SD_S0 | Slot:6 | 3.3V | ON | OFF | TBD | TBD
RK806-1_PLDO6 | 0.3A | VCCA1V8_PLDO6_S3 | Slot:3 | 1.8V | ON | ON | TBD | TBD

VCC_1V1_NLDO | RK806-1_NLDO1 | 0.3A | VDD_0V75_S3 | Slot:2 | 0.75V | ON | ON | TBD | TBD

RK806-1_NLDO2 | 0.3A | VDDA_DDR_PLL_S0 | Slot:2 | 0.85V | ON | OFF | TBD | TBD

VCC_1V1_NLDO | RK806-1_NLDO4 | 0.5A | VDDA_0V85_S0 | Slot:2 | 0.85V | ON | OFF | TBD | TBD

RK806-1_NLDO5 | 0.3A | VDD_0V75_S0 | Slot:2 | 0.75V | ON | OFF | TBD | TBD

VCC4V0_SYS | BUCK_RK860-2 | 6A | VDD_CPU_BIG0_S0 | Slot:6A | 0.75V | ON | OFF | TBD | TBD
VCC4V0_SYS | BUCK_RK860-3 | 6A | VDD_CPU_BIG1_S0 | Slot:6A | 0.75V | ON | OFF | TBD | TBD
VCC4V0_SYS | BUCK_RK860-2 | 6A | VDD_NPU_S0 | Slot:6A | 0.75V | ON | OFF | TBD | TBD
VCC4V0_SYS | EXT BUCK | 2A | VCC_1V1_NLDO_S3 | Slot:1 | 1.1V | ON | ON | TBD | TBD
EXT BUCK | 2A VCC4V0_SYS | VDD2L_0V9_DDR_S3 | Slot:5 | 0.9V | ON | ON | TBD | TBD
2.5A | VCC_3V3_SD_S0 | Slot:6A | 3.3V EXT BUCK VCC4V0_SYS | ON | OFF | TBD | TBD

IO Power Domain Map

03.System Power Sequence CM3588

USB Controller Configure Table | Controller

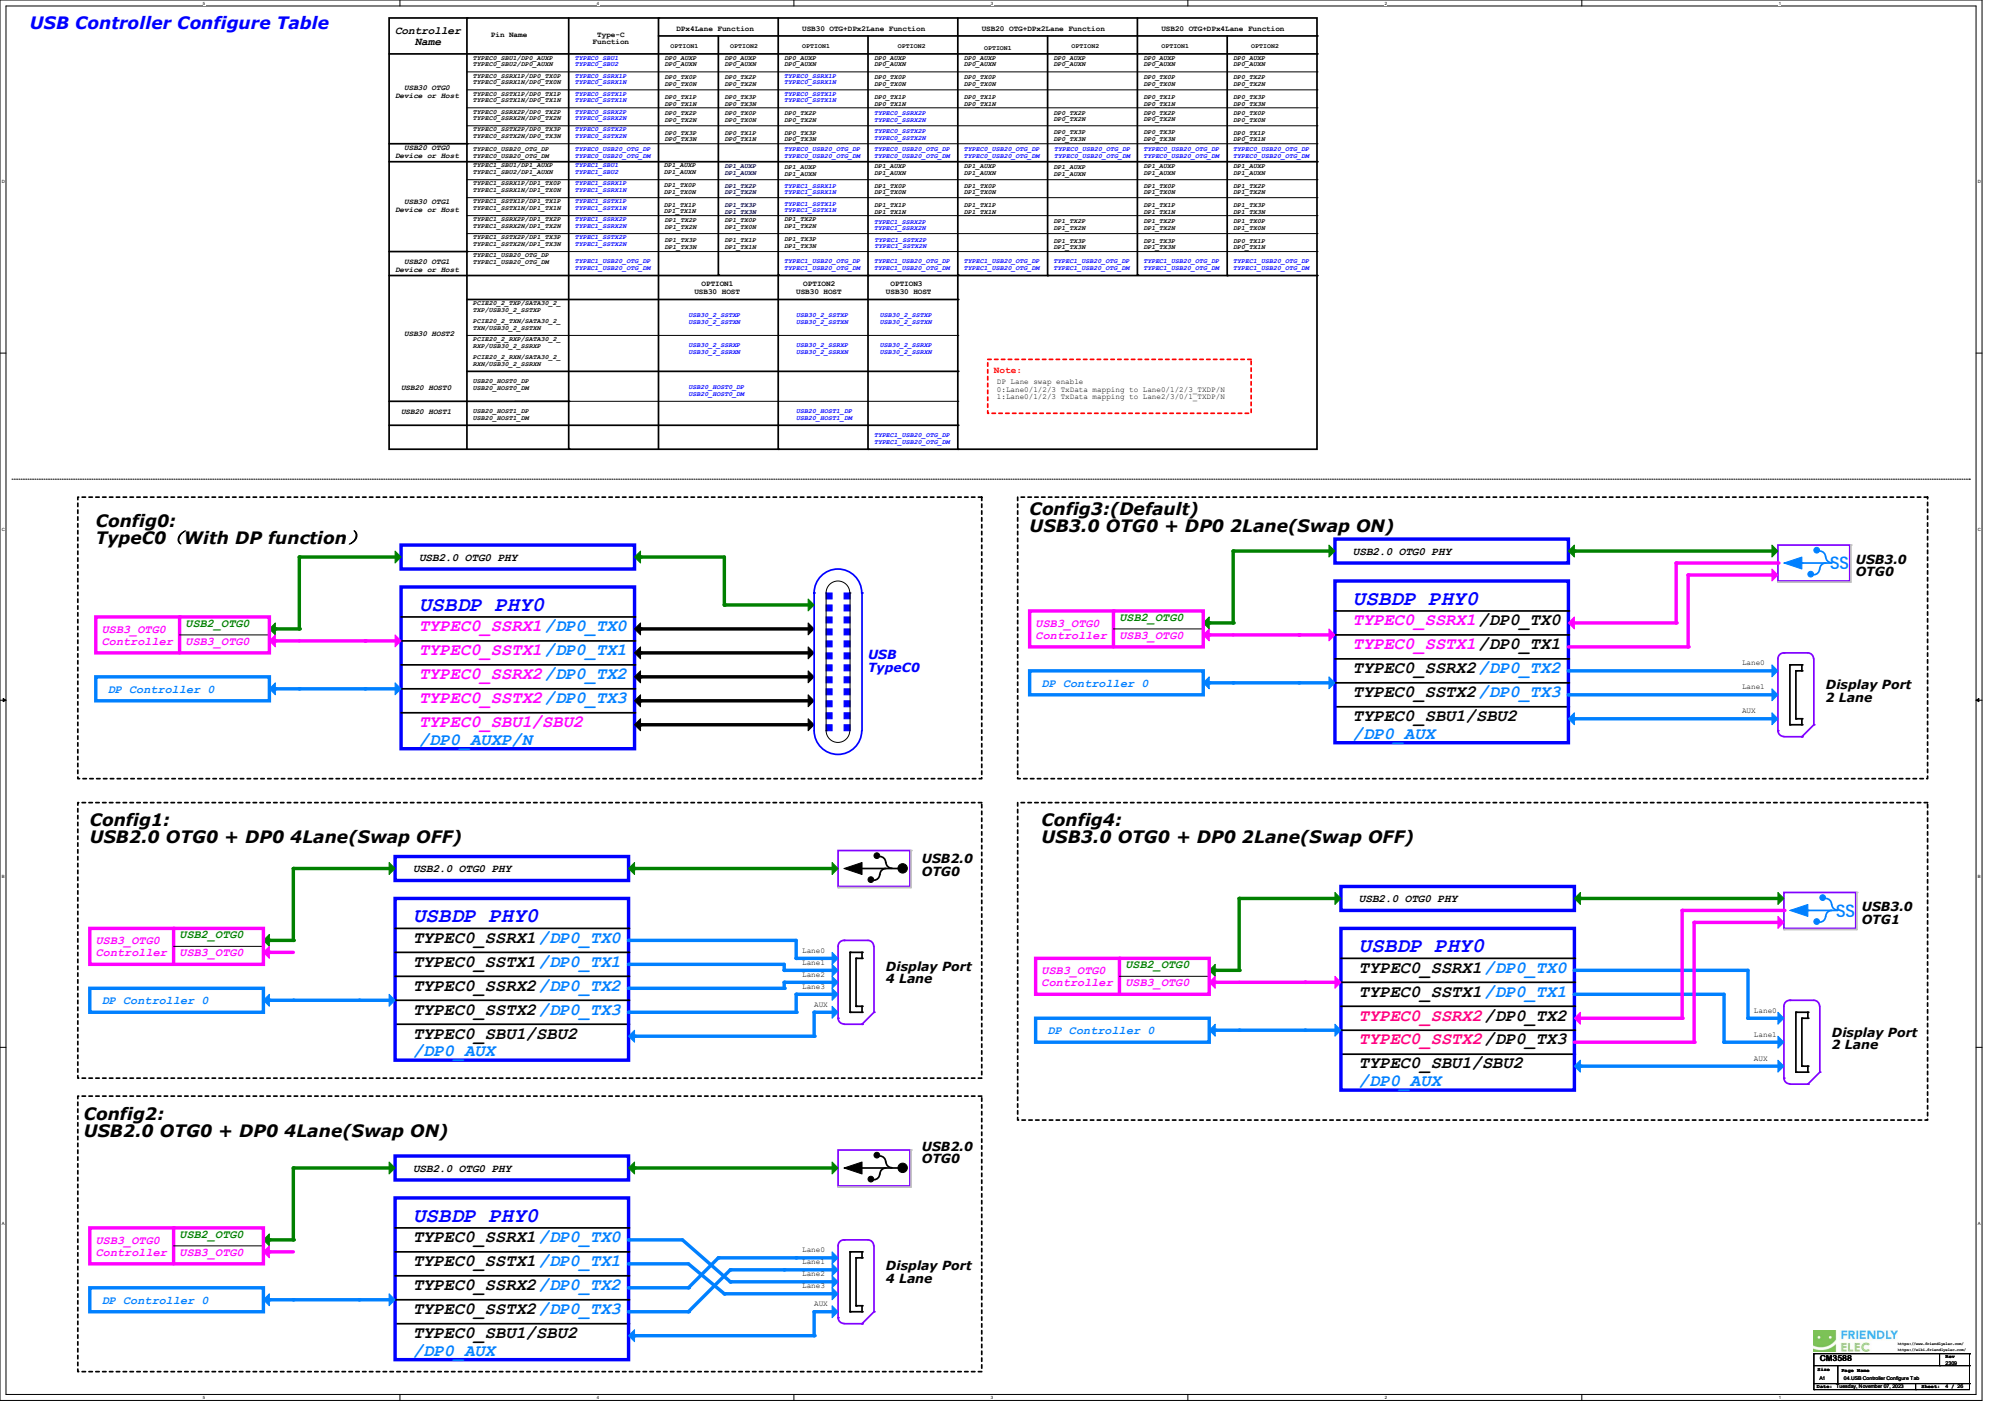
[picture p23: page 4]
Name; Type-C Function; USB30 OTG+DPx2Lane Function; DPx4Lane Function; Pin Name; USB30 HOST2; USB20 HOST0; USB20 HOST1; USB20_HOST0_DP USB20_HOST0_DM; USB20_HOST1_DP USB20_HOST1_DM; DP0_AUXP DP0_AUXN; OPTION1; OPTION2; USB20 OTG+DPx2Lane Function; TYPEC0_USB20_OTG_DP TYPEC0_USB20_OTG_DM; TYPEC0_SBU1/DP0_AUXP TYPEC0_SBU2/DP0_AUXN; TYPEC0_SSRX1P/DP0_TX0P TYPEC0_SSRX1N/DP0_TX0N; TYPEC0_SSTX1P/DP0_TX1P TYPEC0_SSTX1N/DP0_TX1N; TYPEC0_SSRX2P/DP0_TX2P TYPEC0_SSRX2N/DP0_TX2N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

USB30 OTG0
Device or Host

USB20 OTG0
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

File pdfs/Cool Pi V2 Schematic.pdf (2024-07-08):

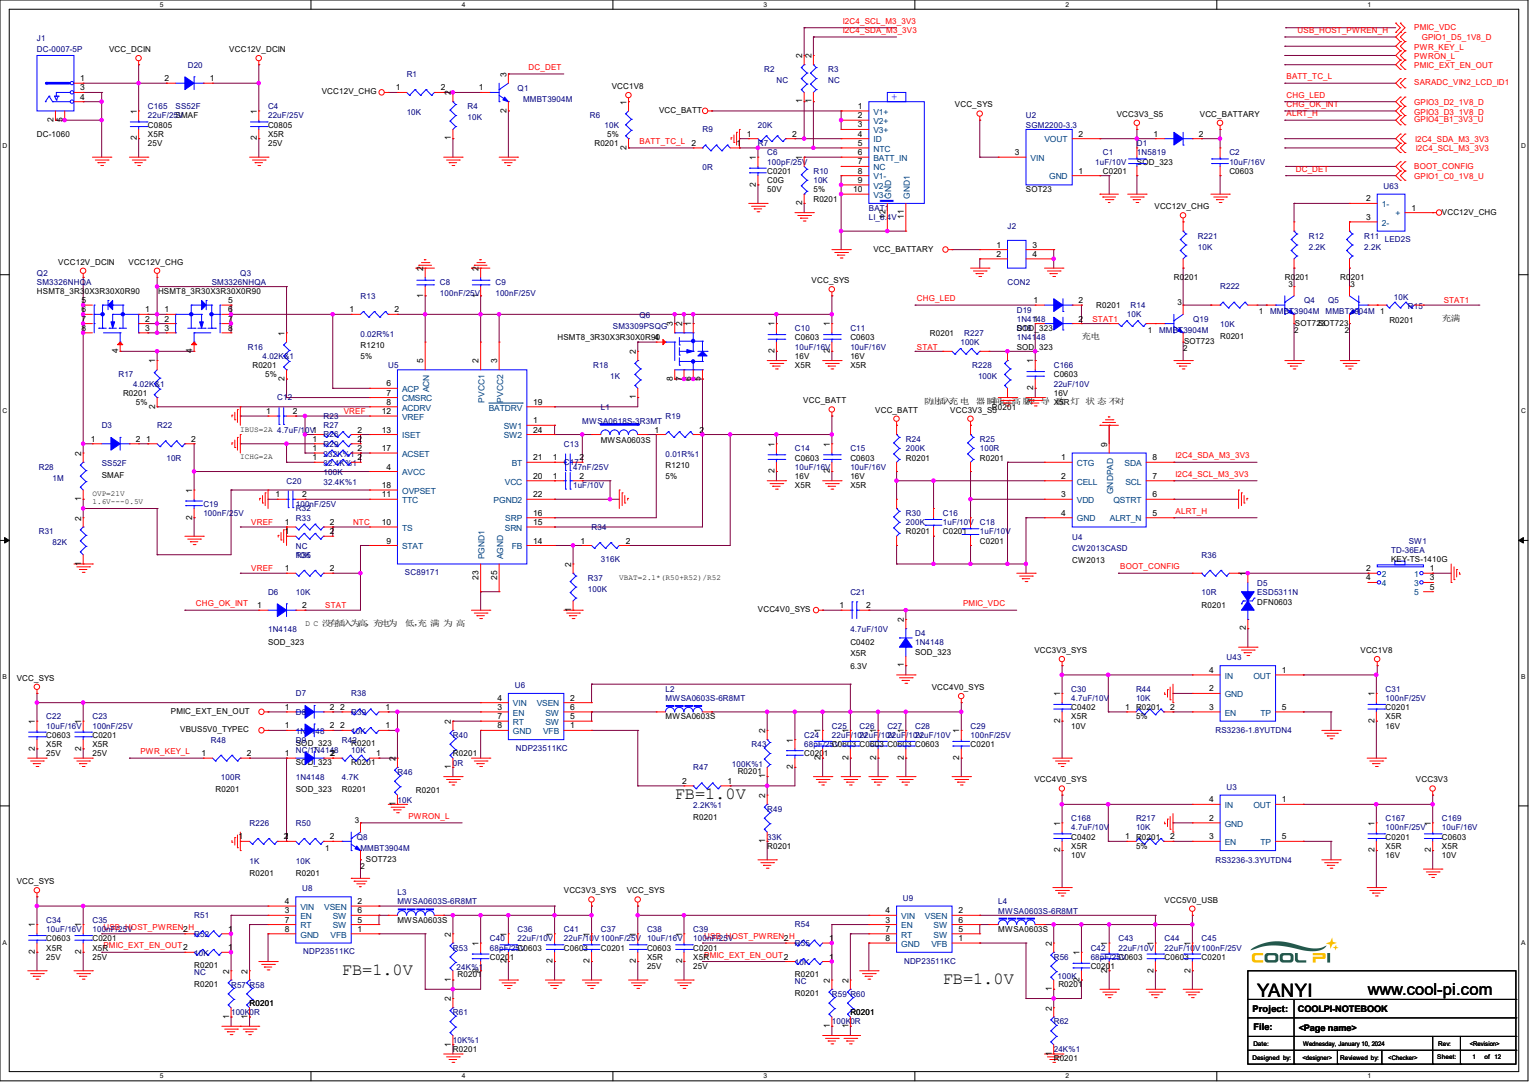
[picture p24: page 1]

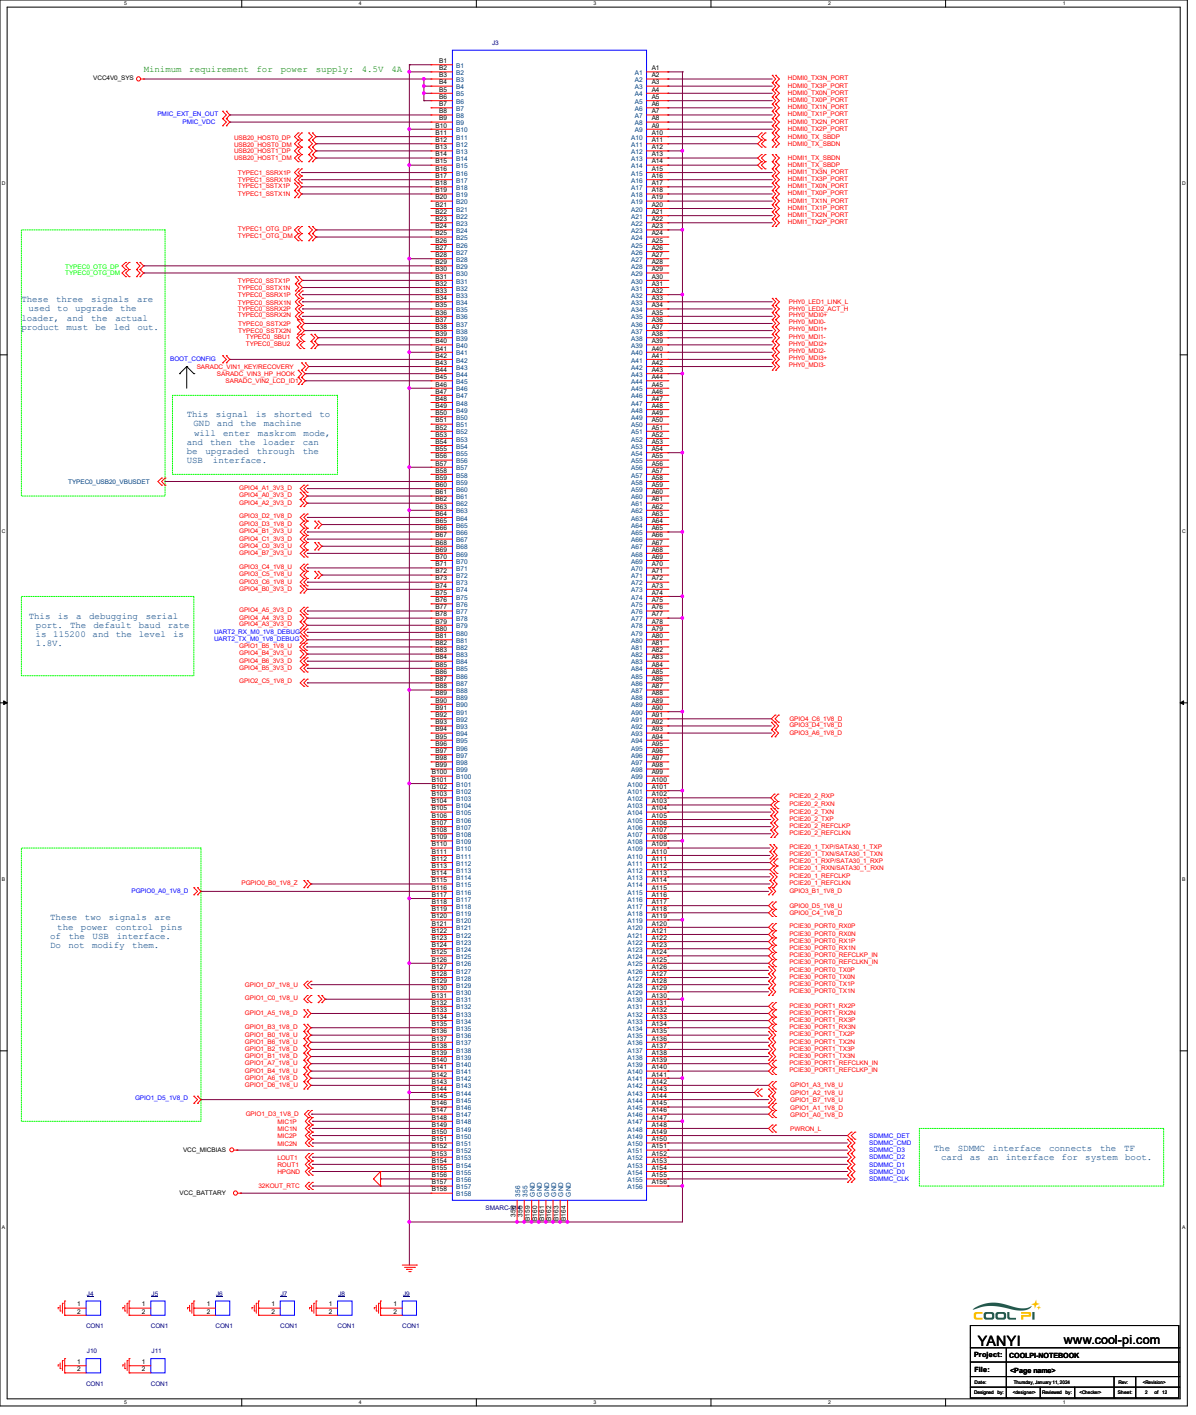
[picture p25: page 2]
MIC; BIA; PIO; FIG; _VIN; CIE; LIN; sig; vie; visio; GND

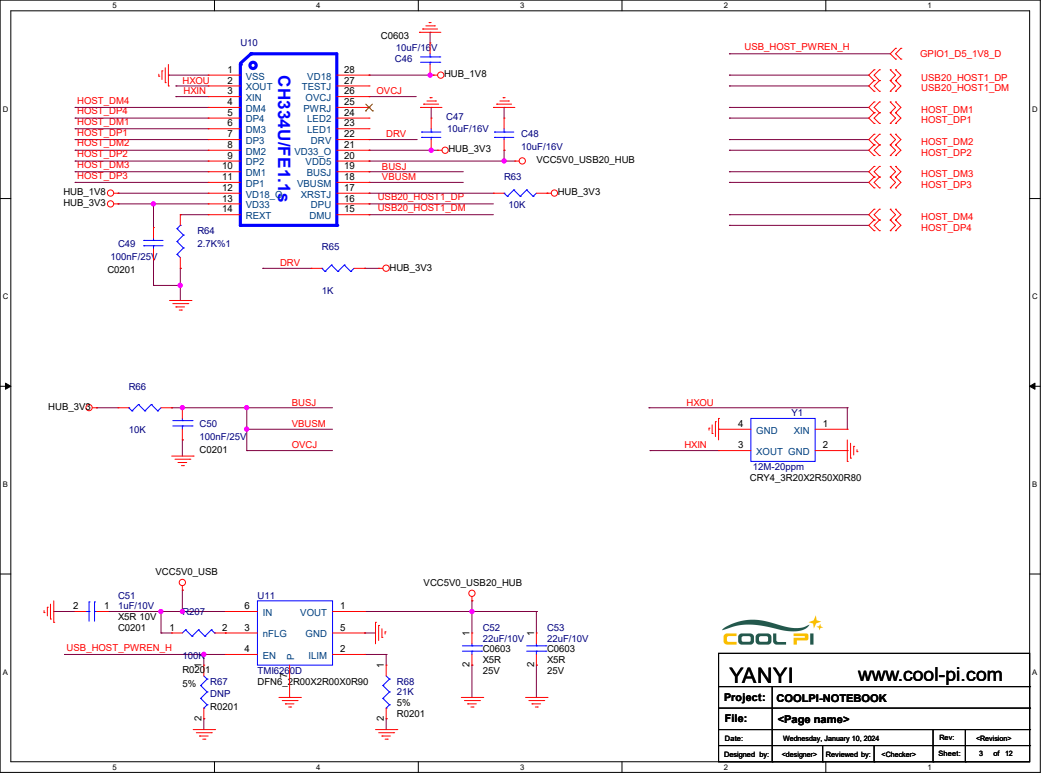
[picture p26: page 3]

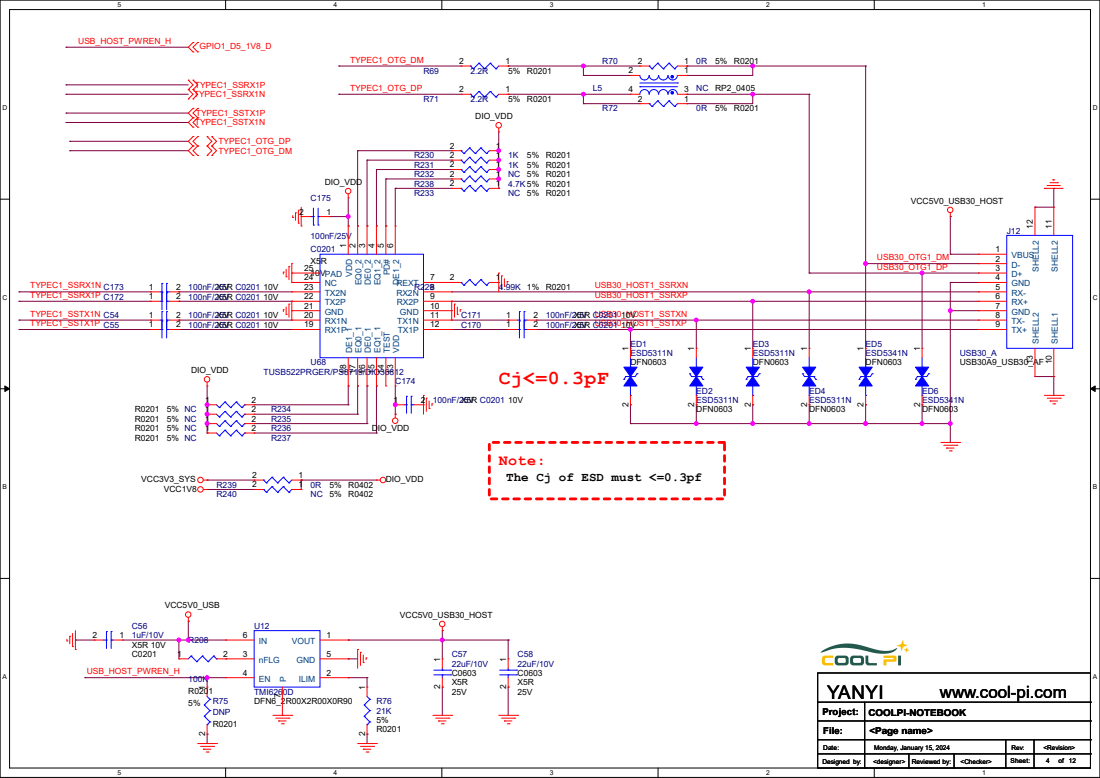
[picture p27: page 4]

Note:
The Cj of ESD must <=0.3pf

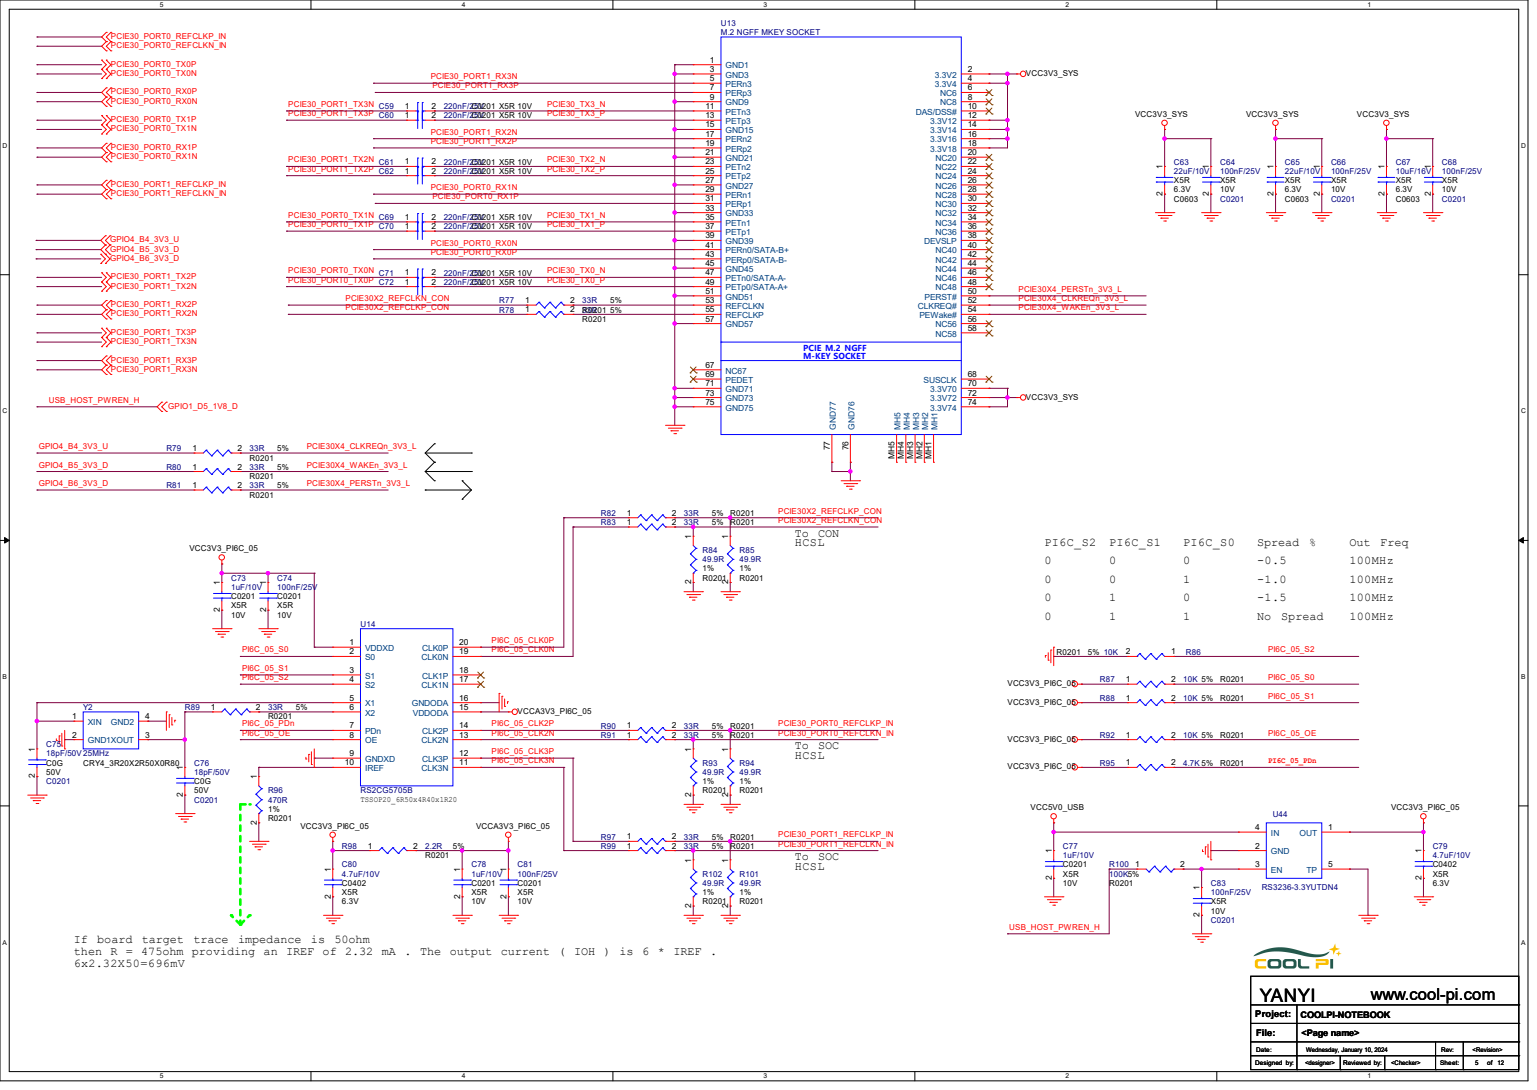
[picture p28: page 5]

then R = 475ohm providing an IREF of 2.32 mA . The output current ( IOH ) is 6 * IREF .

## eDP0

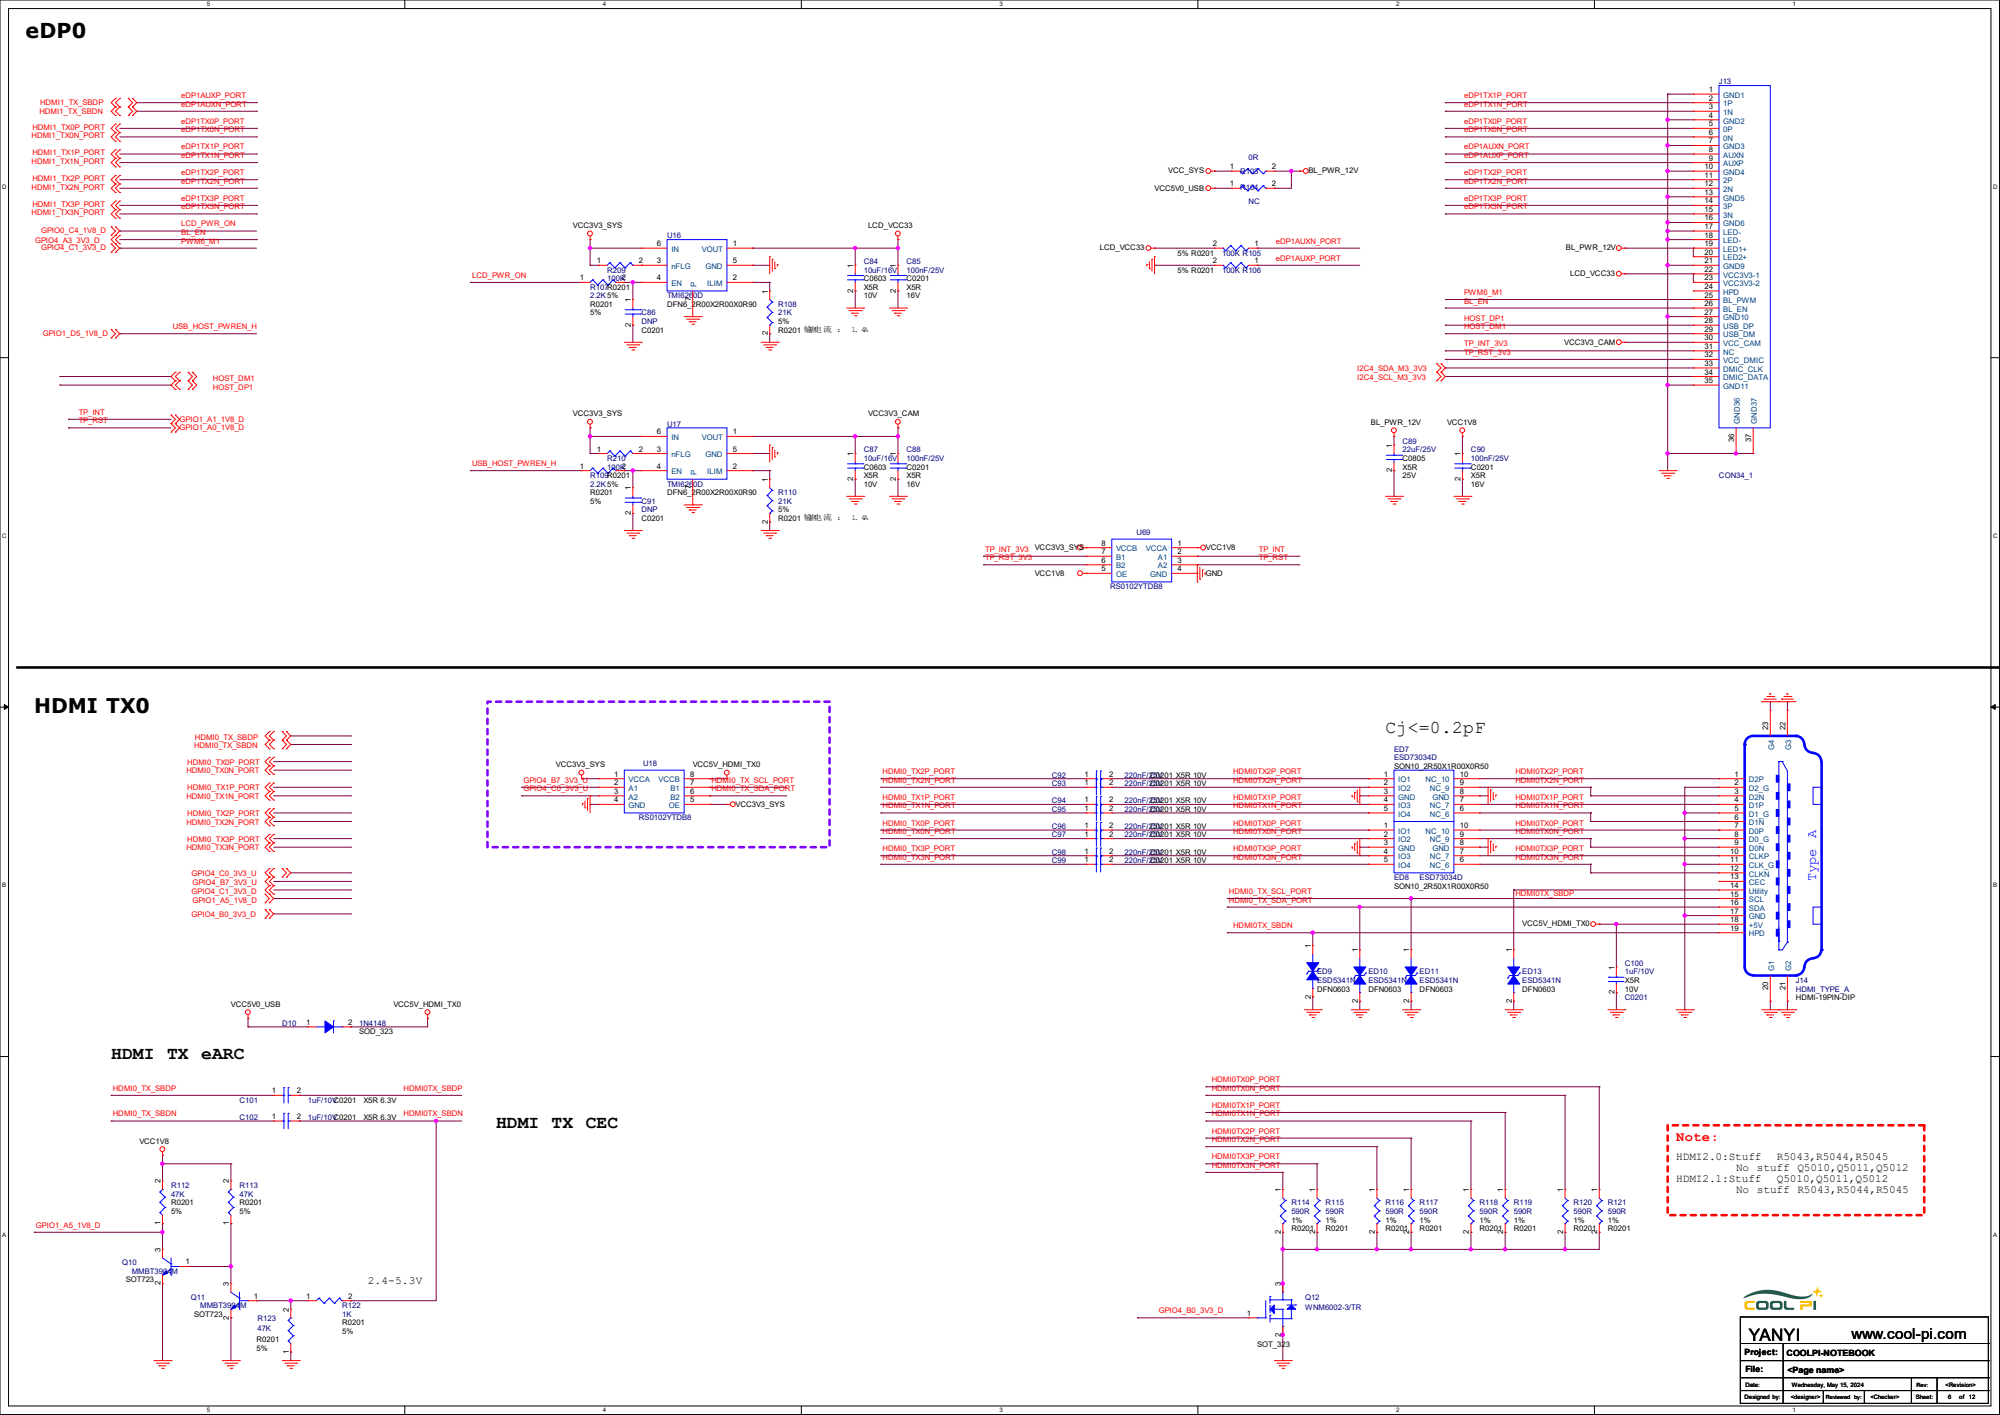
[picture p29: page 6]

Wednesday, May 15, 2024 Wednesday, May 15, 2024 Wednesday, May 15, 2024
<designer> <designer> <designer> | 6 6 6 12 12 12

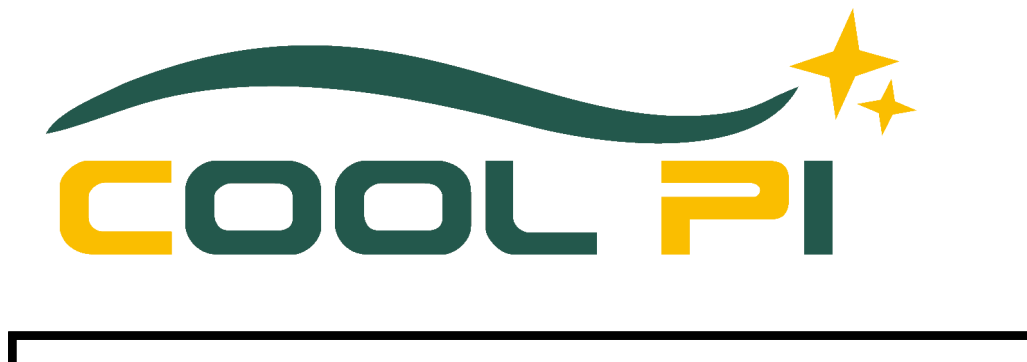
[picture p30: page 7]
Project: File:; Reviewed by:; Sheet:; YANYI; www.cool-pi.com; <Page name>; COOLPI-NOTEBOOK; <designer>

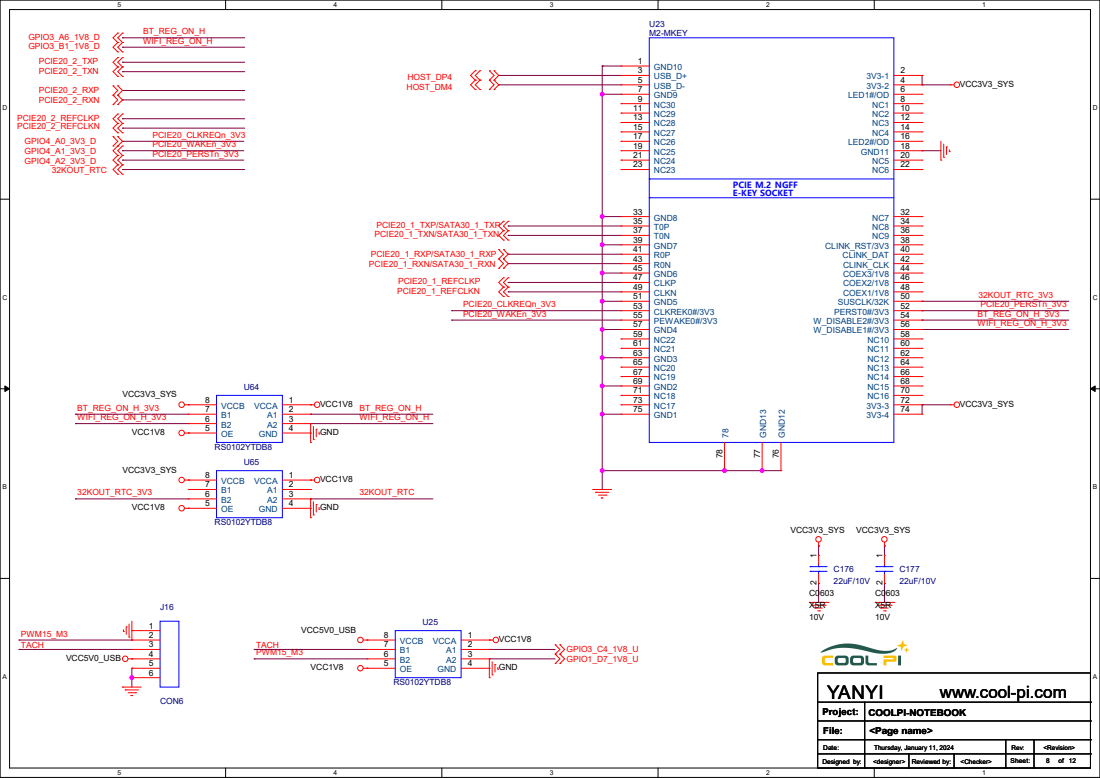
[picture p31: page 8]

Thursday, January 11, 2024 Thursday, January 11, 2024 Thursday, January 11, 2024
<designer> <designer> <designer> | 8 8 8 12 12 12


# CTIA(L,R.G,M)



# Type-C PORT


Rockchip Electronics Co., Ltd

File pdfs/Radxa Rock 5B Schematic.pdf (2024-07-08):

# Table of Content

# 01.Cover

Size; REV; Date:; Sheet; Title:; Page Name:; Table of Content; ROCK 5B; Wednesday, March 01, 2023

02.Content
03.Block Digram
04.DRAM-LPDDR4X_200P_1X32bit
05.CONNECT
06.PCIE-PCIE2.0_Slot-Ekey
07.PCIE-PCIE3.0_Slot-Mkey
08.VI-HDMI2.0 RX
09.USB2HUB
10.RK3588_Power/GND
11.RK3588_OSC/PLL/PMUIO
12.RK3588 DDR Controler
13.RK3588_Flash/SD Controller
14.RK3588_USB30/USB20_Ctrl
15.RK3588_SARADC/1.8V Only GPIO
16.RK3588_MIPI Interface
17.RK3588_HDMI/eDP Interface
18.RK3588_PCIE30/PCIE20/SATA30
19.RK3588_1.8V/ 3.3V GPIO
20.Power_DC IN
21.Audio Codec-ES8316
22.Power-PMIC_RK806-1
23.Power_Ext Discrete
24.PCIE TO RJ45_RTL8125B
25.Flash-eMMC Flash
26.Flash-TF Card
27.USB20x2 Double Port
28.USB30x2 Double Port
29.Type-C Port
30.VI-Camera_MIPI-CSI
31.VO-HDMI2.1 TX
32.VO-LCM_MIPI

# MIPI DSI

# DCDC

MKEY; EKEY; 20x2 GPIO; HDMI IN; ES8316 HEADPHONE; TF CARD; connector; USB HDMI; 20X2 connector; EKEY/MKEY; 24MHz; PMUIO1; LPDDR4 32bit LPDDR4X 32bit; HDMI0; HDMI1; MIPI DPHY1 TX; PCIE20; SATA3.0_Port1; USB30_2_SS; TYPEC0/DP0; USB30X2; RTL8125B; RK806-1 +Discrete Power; Power for RK3588; eMMC; SARADC_IN0; Maskroom; PCIE30 x2 Port1; PCIe3.0 x2Lanes; TYPEC0_USB20_OTG; With DP; PCIe3.0 x4Lanes; eMMC X8bit; on/off; TYPEC1_USB20_HOST; USB2_HOST0; USB2_HOST1; power on; PCIE20 /SATA30_1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

Download/adb Port
TYPEC0

MIPI CSI Connector

DPHY0 RX
Quad A76 + Quad A55USB2 OTG¹/0

# LPDDR4X

# CH A CH B U3800A


# CONNECT

VCC_3V3_S3 | VCC_1V8_S0


# PCIE-PCIE2.0_Slot-Ekey

## FB=0.6V

# PCIe3.0 x 4 Slot


OUTPUT BANK-A OUTPUT BANK-B

# HDMI2.0 RX

## HDMI_RX_HPD_PORT


D | D

# USB2HUB


REXT 13 DMU 14 DPU 15 XRSTJ 16 VBUSM 17 BUSJ 18

# CPU_BIG1

# LOGIC

# RK3588_E(OSC/PLL/PMUIO1/2)

+/-20%


## DDR_CH1_DM0_C DDR_CH1_DM1_C


D | D

# RK3588_C(EMMCIO Domain)


RK3588_M(TYPEC/DP) | RK3588_L(USB2.0 HOST/OTG)

## OTG0_REXT

RK3588_G(VCCIO1 Domain) | RK3588_U(SARADC/OTP)

## SARADC_VIN1_KEY/RECOVERY


FSPI_M2-FSPI_M1-FSPI_M0
-EMMC-SD Card-USB

# RK3588_Q/R(MIPI_D/C_PHY0/1)

## D-PHY:V2.0 4.5Gbps/Lane


# RK3588_S(HDMI2.1 TX) RK3588_T(HDMI20 RX)


HDMI TX/eDP MUX Port0

HDMI TX/eDP MUX Port1

RK3588_N(PCIE20) | RK3588_O(PCIE30)

# PCIE20X1_2-CTL

# RK3588_J(VCCIO5 Domain)

# RK3588_K(VCCIO6 Domain)


# TYPEC-IN

DCDC | VCC5V0


# CODEC ES8316

## MICBIAS1


CPBOT 16 CPGND 17 CPGNDREF 18 ROUT 19 LOUT 20 DACVREF 21 AVDD 22 AGND 23 ADCVREF 24 VMID 25 MICBIAS 26 RIN2 27 LIN2 28 RIN1 29 LIN1 30 CE 31 CDATA 32 E-PAD 33

# PMIC RK806-1 BUCK

# Low frequency:0.85V-->0.75V ¹⁰⁰R


IF TVS UNMOUNTED,
ESD OR SURGE SHOULD BE
DAMAGE THE PMIC!!!

This device must be mounted.Replacing TVS mode is not
recommended, if must, please choose the same specifications
Operating Supply Vltage ：5.5V(5.25-6V)
PeakPulse Current：>10A（tp=8/20uS)
Surge Clamping Voltage：<6.5V
DO NOT DELETE IT!

# Feedback from RK3588

# VDD_CPU_BIG1

### LAN_EXT_CORE


D | D

# eMMC FLASH


D | D

# TF CARD


# USB2.0

# USB3.0 HOST PORT

## VCC5V0_SYS


D | D

# Type-C PORT


12bit ADC | ADC-IN6 TYPEC IN
5V | 35e | 0.37V
9V | 610 | 0.68V

15V | a1a | 1.136V
20V | d79 | 1.51V

55

44


# Cj<=0.2pF

# HDMI TX eARC

# MIPI DPHY1 TX

1.8V


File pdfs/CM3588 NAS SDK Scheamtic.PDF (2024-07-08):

5

4

CM3588 NAS SDK; CM3588 PCIe 3.0 x1 PCIe 3.0 x1 PCIe 3.0 x1 PCIe 3.0 x1; M.2 key-M; PCIe 3.0 Clock; Buzzer; PWM; SDMMC; microSD; Headphone; 2.5G MDI, LED; TYPEC1 USB 3.0 TYPEC1 USB 2.0; USB 3.0 Host USB2.0 HOST1; 2 x USB 3.0 A Ports; USB 2.0 A Port; HDMI TX0; HDMI TX1; HDMI RX; 40 Pins GPIO; GPIO/UART/SPI/I2C/PWM/I2S...; Nor Flash FSPI; 30 Pins FPC; 30 Pins FPC MIPI_DPHY0_TX; MIPI_CSI1_RX; to USB,Type-C,HDMI,FAN,GPIO,MIPI; to Nor Flash, etc 3.3V DC/DC; 1.8V LDO; https://www.friendlyelec.com/ 1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

to M.2 Key-M,IR,GPIO,etc

MIC HPR/HPL/MIC

Buttons: Reset,Power,Mask,Recovery,User

2.5G RJ45 with Integrated Magnetics

USB2.0 HOST0
USB 3.0/DP Type-C Port TYPEC0

RTC³V RTC Battery
FANGPIO/PWM

01.Block CM3588 NAS SDK

https://wiki.friendlyelec.com/

Rev 2309

Size | Page Name

Date: | Sheet: /

D

D

GND_AUDUO; VCC3V3_SD_S0; VDD_12V; PCIE30_PORT0_TX0P [13] PCIE30_PORT0_TX0N [13] PCIE30_PORT0_TX1N [13]; [12] I2C7_SDA_M0; PCIE30_PORT0_TX1P [13]; [12] I2C7_SCL_M0; PCIE30_PORT1_RX2N [14] PCIE30_PORT1_RX2P [14] PCIE30_PORT1_RX3N [14] PCIE30_PORT1_RX3P [14] PCIE30_PORT1_TX2N [14] PCIE30_PORT1_TX2P [14] PCIE30_PORT1_TX3P [14] PCIE30_PORT1_TX3N [14]; [12] GPIO1_B7/MIPI_CAM2_CLKOUT; PCIE30_PORT1_REFCLKN_IN; [15] PCIE30_PORT1_REFCLKP_IN; [5] TYPEC0_SSTX1P [5] TYPEC0_SSTX1N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

D D

# 12V Input


03.Sys Power CM3588 NAS SDK

D D

3.3V for Key-M M.2 Socket | VDD_M2_A_3.3V


D D

USB3.0 Type-C | GND


05.USB Type-C CM3588 NAS SDK

D D

# HDMI TX0


D D

# HDMI TX1


D D

# HDMI RX


08.HDMI RX CM3588 NAS SDK

D D

# PWR


IRM-V538/TR1 Vout 1 VCC 2 GND 3 SHELL 4

09.Audio/IR/Buttons CM3588 NAS SDK

D D

# 2.5G Ethernet


D D

Buzzer | SPI Nor Flash


Power-On Mode Select Jumper

Opent: power up immediately after 12V IN is powered
Short: power up afer PowerKey is pressed

11.Buzzer/Nor Flash/Fan CM3588 NAS SDK

55

44


D D

# M.2 Key-M Socket 1&2


Swapped P/N to optimize routing

D D

# 1 H6 3.2MM ETCH HOLE G4SMTSO-M3-5ET G¹


D D

## Internal pull-up


U18 PI6C557-05B/NB3N51034 VDDXD 1 S0 2 S1 3 S2 4 X1 5 X2 6 PD 7 OE 8 GNDXD 9

15pF/50V C0402 U19 PI6C557-05B/NB3N51034 VDDXD 1 S0 2 S1 3 S2 4 X1 5 X2 6 PD 7 OE 8 GNDXD 9

15.PCIe 3.0 REFCLK CM3588 NAS SDK

D D


1 2 R171 33R 2 1 R0402 MICROSD1 MicroSD-A102-206017-001 DAT2 1 CD/DAT3 2 CMD 3 VDD 4 CLK 5 VSS 6 DAT0 7 DAT1 8 CD 9 S1 12 S2 10 S3 13 S4 11 M1 M1 M2 M2 R157 33R 2 1 R0402 R146 33R 2 1 R0402 R144 33R 2 1 R0402 R163 33R 2 1 R0402 CON6 Header_2.54MM

16.GPIO/microSD CM3588 NAS SDK

D D

# 2 x USB 3.0 A


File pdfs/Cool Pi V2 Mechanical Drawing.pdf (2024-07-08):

+ | + | + | +
MIC | Touch Screen


U42 U⁴²xA¹ U⁴²xA² U⁴²xA³ U⁴²xB¹ U⁴²xB² U⁴²xB³ U⁴²xC¹ U⁴²xC² U⁴²xC³ R206R²⁰⁶x1
R205R²⁰⁵x1 R²⁰⁵x2

SSD NVME Extend IO

U33 U33


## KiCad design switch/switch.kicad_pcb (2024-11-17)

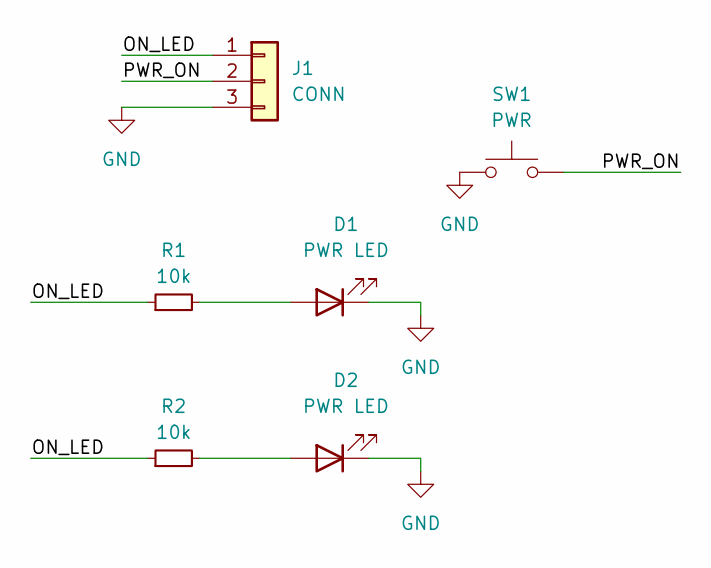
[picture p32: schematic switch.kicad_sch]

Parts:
D1, D2: PWR LED; LED_0603_1608Metric
J1: CONN; PinHeader_1x03_P1.27mm_Vertical
R1, R2: 10k; R_0402_1005Metric
SW1: PWR; SW_Push_1P1T_XKB_TS-1187A

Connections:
/ON_LED: J1.1, R1.1, R2.1
/PWR_ON: J1.2, SW1.2
GND: D1.1 (K), D2.1 (K), J1.3, SW1.1
unnamed: D1.2 (A), R1.2
unnamed: D2.2 (A), R2.2

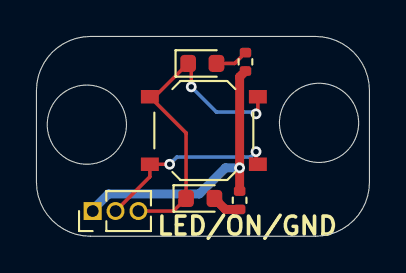
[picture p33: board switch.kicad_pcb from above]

Board: 2 copper layers, 18.5 x 11.1 mm, 6 parts (0 on the bottom side), 5 nets.

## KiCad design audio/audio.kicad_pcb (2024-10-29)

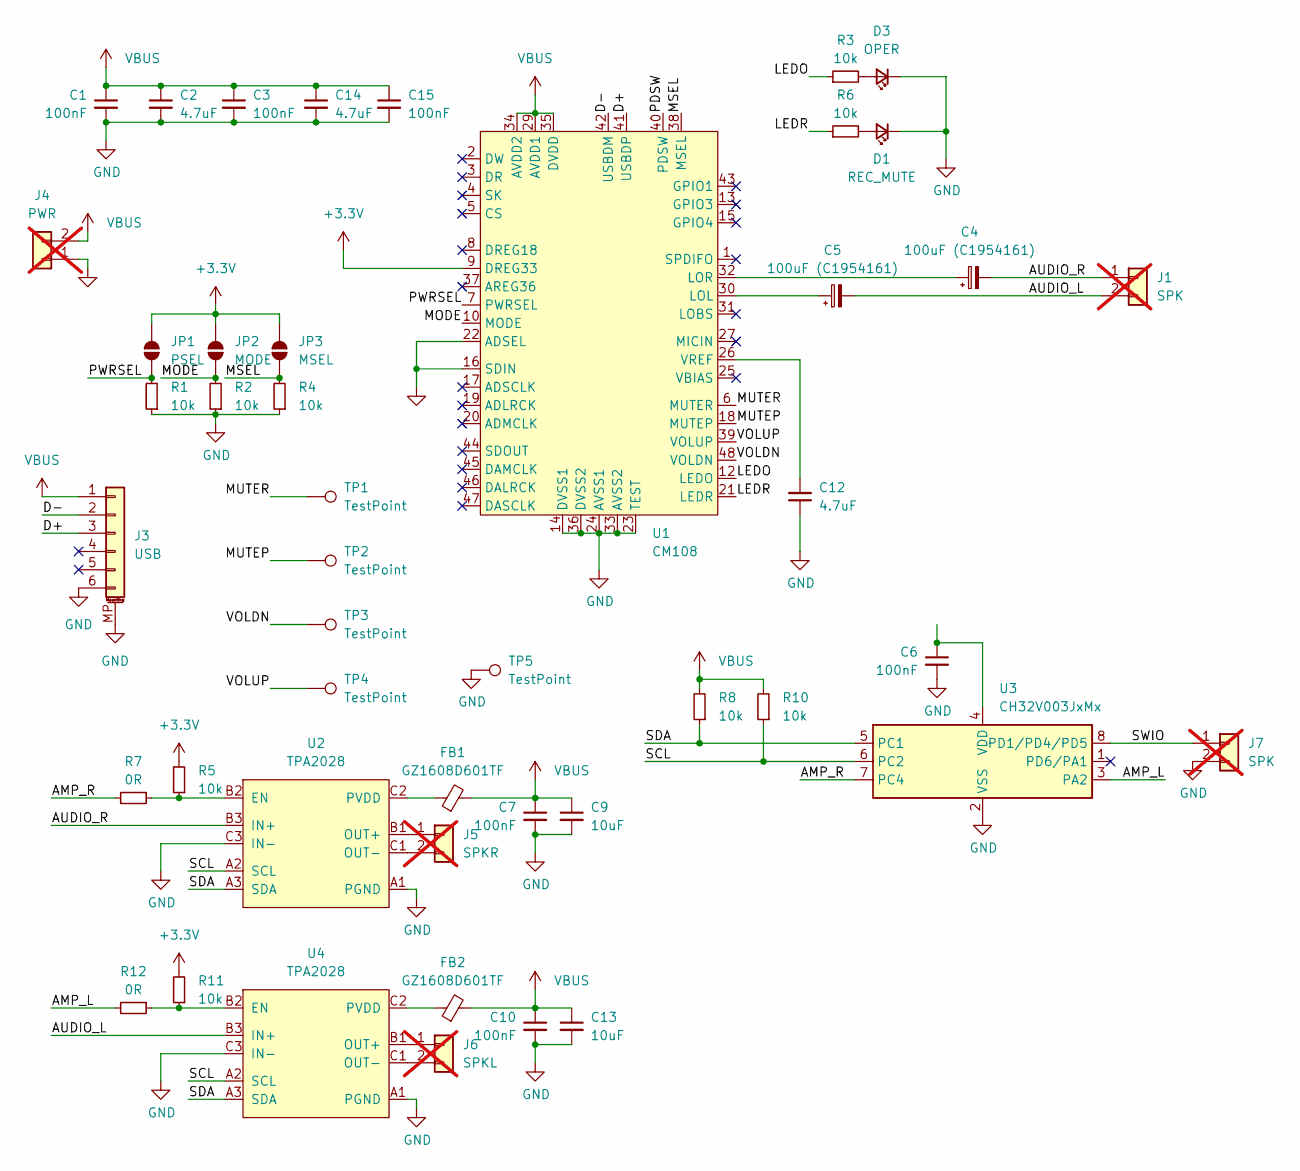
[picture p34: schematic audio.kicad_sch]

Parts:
C1, C3, C6, C7, C10, C15: 100nF; C_0603_1608Metric
C2, C12, C14: 4.7uF; C_0603_1608Metric
C4, C5: 100uF (C1954161); C_1206_3216Metric
C9, C13: 10uF; C_0603_1608Metric
D1: REC_MUTE; LED_0603_1608Metric
D3: OPER; LED_0603_1608Metric
FB1, FB2: GZ1608D601TF; L_0603_1608Metric
J1, J7: SPK; PinHeader_1x02_P2.54mm_Vertical; not fitted
J3: USB; FPC-SMD_6P-P0.50_XUNPU_FPC-05F-6PH20; LCSC C2856796
J4: PWR; PinHeader_1x02_P2.54mm_Vertical; not fitted
J5: SPKR; PinHeader_1x02_P2.54mm_Vertical; not fitted
J6: SPKL; PinHeader_1x02_P2.54mm_Vertical; not fitted
JP1: PSEL; SolderJumper-2_P1.3mm_Open_TrianglePad1.0x1.5mm
JP2: MODE; SolderJumper-2_P1.3mm_Open_TrianglePad1.0x1.5mm
JP3: MSEL; SolderJumper-2_P1.3mm_Open_TrianglePad1.0x1.5mm
R1, R2, R3, R4, R5, R6, R8, R10, R11: 10k; R_0603_1608Metric
R7, R12: 0R; R_0603_1608Metric
TP1, TP2, TP3, TP4, TP5: TestPoint; TestPoint_THTPad_1.0x1.0mm_Drill0.5mm
U1: CM108; LQFP-48_7x7mm_P0.5mm
U2, U4: TPA2028
U3: CH32V003JxMx; SOP-8_3.9x4.9mm_P1.27mm

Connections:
+3.3V: JP1.2 (B), JP2.2 (B), JP3.2 (B), R5.2, R11.2, U1.9 (DREG33)
/AMP_L: R12.2, U3.3 (PA2)
/AMP_R: R7.2, U3.7 (PC4)
/AUDIO_L: C5.2, J1.2, U4.B3 (IN+)
/AUDIO_R: C4.2, J1.1, U2.B3 (IN+)
/D+: J3.3, U1.41 (USBDP)
/D-: J3.2, U1.42 (USBDM)
/LEDO: R3.1, U1.12 (LEDO)
/LEDR: R6.1, U1.21 (LEDR)
/MODE: JP2.1 (A), R2.2, U1.10 (MODE)
/MSEL: JP3.1 (A), R4.2, U1.38 (MSEL)
/MUTEP: TP2.1, U1.18 (MUTEP)
/MUTER: TP1.1, U1.6 (MUTER)
/PDSW: U1.40 (PDSW)
/PWRSEL: JP1.1 (A), R1.2, U1.7 (PWRSEL)
/SCL: R10.1, U2.A2 (SCL), U3.6 (PC2), U4.A2 (SCL)
/SDA: R8.1, U2.A3 (SDA), U3.5 (PC1), U4.A3 (SDA)
/SWIO: J7.1, U3.8 (PD1/PD4/PD5)
/VOLDN: TP3.1, U1.48 (VOLDN)
/VOLUP: TP4.1, U1.39 (VOLUP)
GND: C1.2, C2.2, C3.2, C6.2, C7.2, C9.2, C10.2, C12.1, C13.2, C14.2, C15.2, D1.1 (K), D3.1 (K), J3.6, J3.MP (MountPin), J4.1, J7.2, R1.1, R2.1, R4.1, TP5.1, U1.14 (DVSS1), U1.16 (SDIN), U1.22 (ADSEL), U1.23 (TEST), U1.24 (AVSS1), U1.33 (AVSS2), U1.36 (DVSS2), U2.A1 (PGND), U2.C3 (IN-), U3.2 (VSS), U4.A1 (PGND), U4.C3 (IN-)
unnamed: D1.2 (A), R6.2
unnamed: D3.2 (A), R3.2
unnamed: J5.1, U2.B1 (OUT+)
unnamed: J5.2, U2.C1 (OUT-)
unnamed: J6.1, U4.B1 (OUT+)
unnamed: J6.2, U4.C1 (OUT-)
unnamed: C5.1, U1.30 (LOL)
unnamed: C4.1, U1.32 (LOR)
unnamed: C12.2, U1.26 (VREF)
unnamed: R5.1, R7.1, U2.B2 (EN)
unnamed: FB1.1, U2.C2 (PVDD)
unnamed: C6.1, U3.4 (VDD)
unnamed: R11.1, R12.1, U4.B2 (EN)
unnamed: FB2.1, U4.C2 (PVDD)
VBUS: C1.1, C2.1, C3.1, C7.1, C9.1, C10.1, C13.1, C14.1, C15.1, FB1.2, FB2.2, J3.1, J4.2, R8.2, R10.2, U1.29 (AVDD1), U1.34 (AVDD2), U1.35 (DVDD)

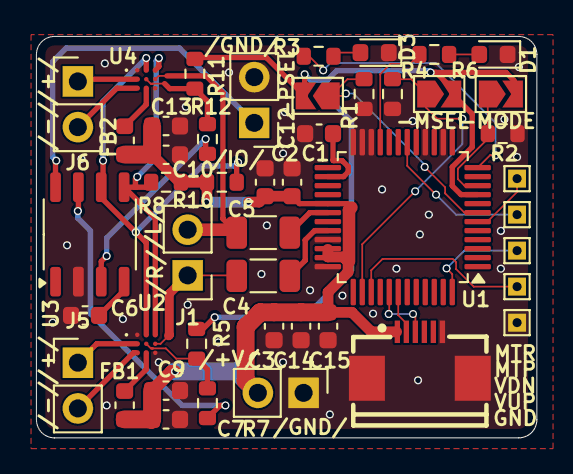
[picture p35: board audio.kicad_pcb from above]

Board: 2 copper layers, 27.8 x 22.3 mm, 46 parts (0 on the bottom side), 35 nets.

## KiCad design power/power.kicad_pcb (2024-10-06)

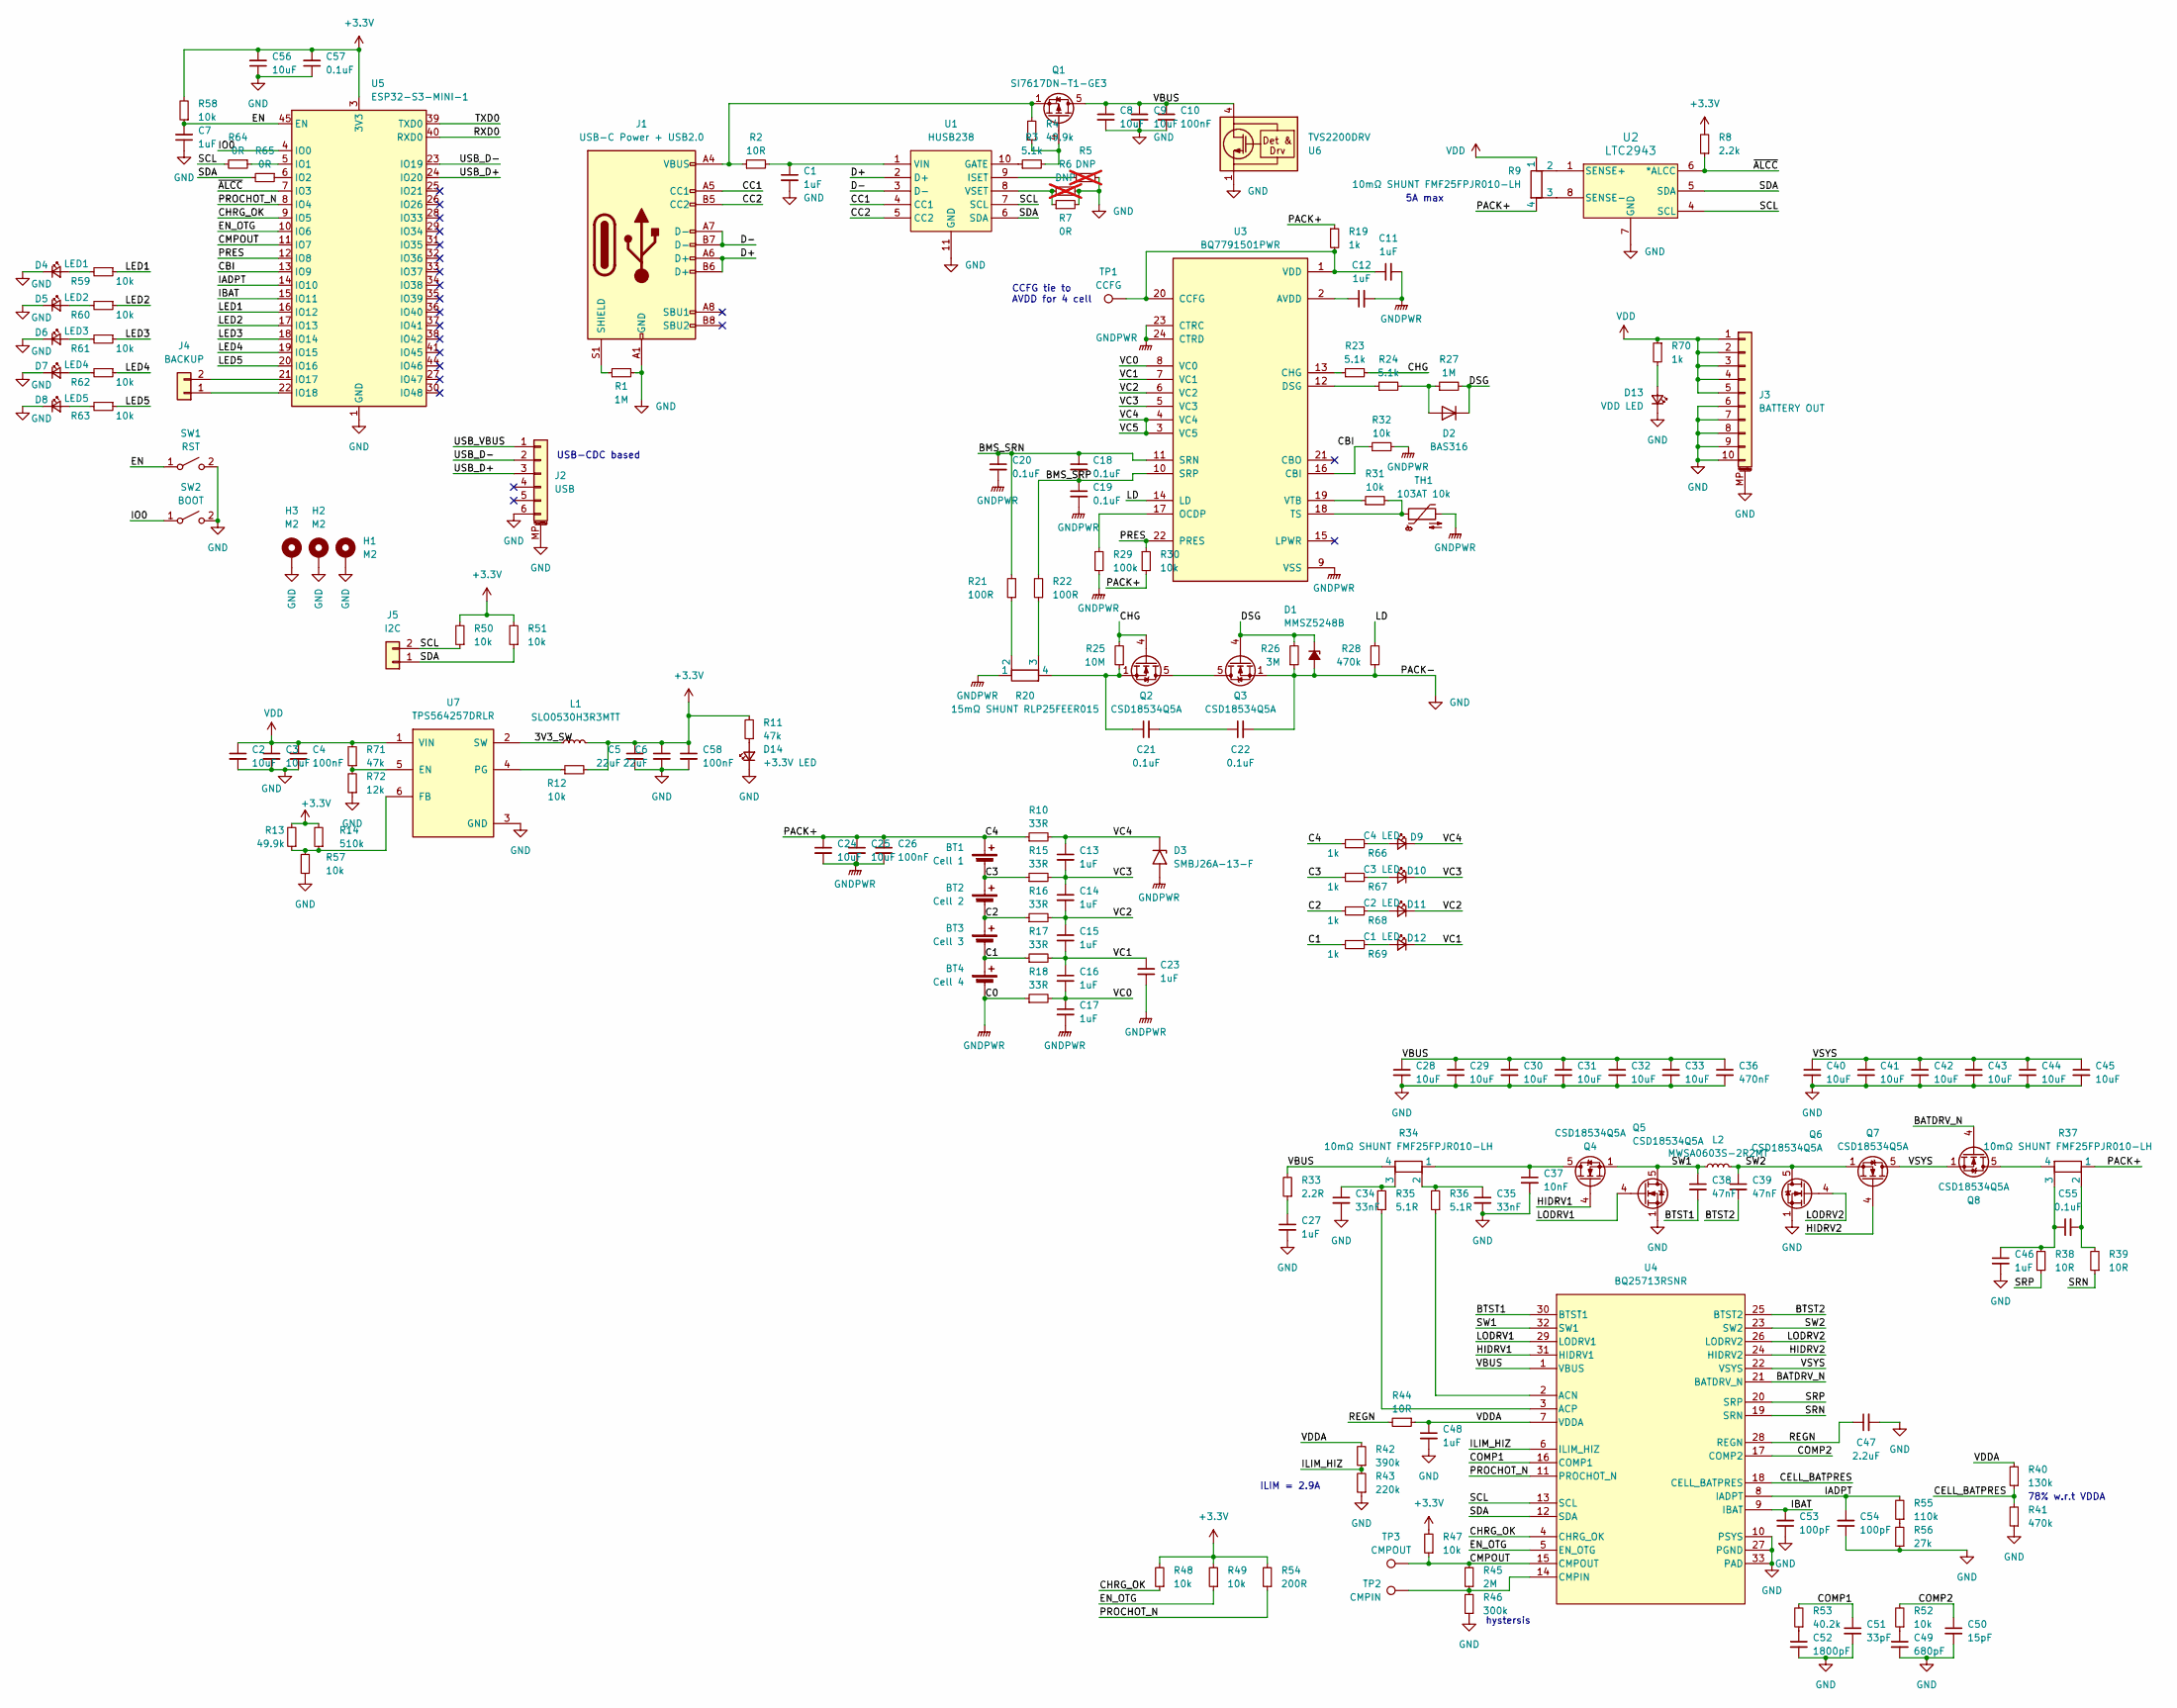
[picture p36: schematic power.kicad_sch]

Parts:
BT1: Cell 1; PinHeader_1x02_P2.54mm_Vertical
BT2: Cell 2; PinHeader_1x02_P2.54mm_Vertical
BT3: Cell 3; PinHeader_1x02_P2.54mm_Vertical
BT4: Cell 4; PinHeader_1x02_P2.54mm_Vertical
C1, C7: 1uF; C_0603_1608Metric; LCSC C15849
C2, C3, C8, C9, C24, C25, C28, C29, C30, C31, C32, C33, C40, C41, C42, C43, C44, C45, C56: 10uF; C_0603_1608Metric; LCSC C913517
C4, C58: 100nF; C_0402_1005Metric; LCSC C307331
C5, C6: 22uF; C_0603_1608Metric; LCSC C162690
C10, C26: 100nF; C_0603_1608Metric; LCSC C307331
C11, C12, C13, C14, C15, C16, C17, C23, C27, C46, C48: 1uF; C_0603_1608Metric; LCSC C913517
C18, C19, C20, C21, C22, C55: 0.1uF; C_0603_1608Metric; LCSC C913517
C34, C35: 33nF; C_0603_1608Metric; LCSC C913517
C36: 470nF; C_0603_1608Metric; LCSC C913517
C37: 10nF; C_0603_1608Metric; LCSC C913517
C38, C39: 47nF; C_0603_1608Metric; LCSC C913517
C47: 2.2uF; C_0603_1608Metric; LCSC C913517
C49: 680pF; C_0603_1608Metric; LCSC C913517
C50: 15pF; C_0603_1608Metric; LCSC C913517
C51: 33pF; C_0603_1608Metric; LCSC C913517
C52: 1800pF; C_0603_1608Metric; LCSC C913517
C53, C54: 100pF; C_0603_1608Metric; LCSC C913517
C57: 0.1uF; C_0603_1608Metric; LCSC C14663
D1: MMSZ5248B; D_SOD-123; LCSC C82088
D2: BAS316; D_SOD-323; LCSC C109218
D3: SMBJ26A-13-F; D_SMB; LCSC C135062
D4: LED1; LED_0603_1608Metric; LCSC C2290
D5: LED2; LED_0603_1608Metric; LCSC C2290
D6: LED3; LED_0603_1608Metric; LCSC C2290
D7: LED4; LED_0603_1608Metric; LCSC C2290
D8: LED5; LED_0603_1608Metric; LCSC C2290
D9: C4 LED; LED_0603_1608Metric; LCSC C2286
D10: C3 LED; LED_0603_1608Metric; LCSC C2286
D11: C2 LED; LED_0603_1608Metric; LCSC C2286
D12: C1 LED; LED_0603_1608Metric; LCSC C2286
D13: VDD LED; LED_0603_1608Metric; LCSC C72038
D14: +3.3V LED; LED_0603_1608Metric
H1, H2, H3: M2; MountingHole_2.2mm_M2_Pad_Via
J1: USB-C Power + USB2.0; USB_C_Receptacle_HRO_TYPE-C-31-M-12; LCSC C165948
J2: USB; FPC-SMD_6P-P0.50_XUNPU_FPC-05F-6PH20; LCSC C2856796
J3: BATTERY OUT; Molex_PicoBlade_53048-1010_1x10_P1.25mm_Horizontal; LCSC C564042
J4: BACKUP; PinHeader_1x02_P2.54mm_Vertical
J5: I2C; PinHeader_1x02_P2.54mm_Vertical
L1: SLO0530H3R3MTT; L_Chilisin_BMRA00050530; LCSC C408446
L2: MWSA0603S-2R2MT; L_Sunlord_MWSA0603S; LCSC C408445
Q1: SI7617DN-T1-GE3; Vishay_PowerPAK_1212-8_Single; LCSC C727607
Q2, Q3, Q4, Q5, Q6, Q7, Q8: CSD18534Q5A; TDSON-8-1; LCSC C115943
R1, R27: 1M; R_0603_1608Metric; LCSC C22935
R2: 10R; R_0603_1608Metric; LCSC C22859
R3, R23, R24: 5.1k; R_0603_1608Metric; LCSC C23186
R4: 49.9k; R_0603_1608Metric; LCSC C23184
R5, R6: DNP; R_0603_1608Metric; not fitted
R7: 0R; R_0603_1608Metric; LCSC C21189
R8: 2.2k; R_0603_1608Metric; LCSC C4190
R9, R34, R37: 10mΩ SHUNT FMF25FPJR010-LH; R_Shunt_Vishay_WSK2512_6332Metric_T1.19mm; LCSC C105366
R10, R15, R16, R17, R18: 33R; R_0603_1608Metric; LCSC C23140
R11: 47k; R_0402_1005Metric; LCSC C25744
R12, R57: 10k; R_0402_1005Metric; LCSC C25744
R13: 49.9k; R_0402_1005Metric; LCSC C25897
R14: 510k; R_0402_1005Metric; LCSC C11616
R19: 1k; R_0603_1608Metric; LCSC C21190
R20: 15mΩ SHUNT RLP25FEER015; R_Shunt_Vishay_WSK2512_6332Metric_T1.19mm; LCSC C393085
R21, R22: 100R; R_0603_1608Metric; LCSC C22775
R25: 10M; R_0603_1608Metric; LCSC C7250
R26: 3M; R_0603_1608Metric; LCSC C23156
R28: 470k; R_0603_1608Metric; LCSC C23178
R29: 100k; R_0603_1608Metric; LCSC C25803
R30, R31, R32: 10k; R_0603_1608Metric; LCSC C25804
R33: 2.2R; R_0603_1608Metric; LCSC C25744
R35, R36: 5.1R; R_0603_1608Metric; LCSC C25744
R38, R39, R44: 10R; R_0603_1608Metric; LCSC C25744
R40: 130k; R_0603_1608Metric; LCSC C25744
R41: 470k; R_0603_1608Metric; LCSC C25744
R42: 390k; R_0603_1608Metric; LCSC C25744
R43: 220k; R_0603_1608Metric; LCSC C25744
R45: 2M; R_0603_1608Metric; LCSC C25744
R46: 300k; R_0603_1608Metric; LCSC C25744
R47, R48, R49, R50, R51, R52, R58, R59, R60, R61, R62, R63: 10k; R_0603_1608Metric; LCSC C25744
R53: 40.2k; R_0603_1608Metric; LCSC C25744
R54: 200R; R_0603_1608Metric; LCSC C25744
R55: 110k; R_0603_1608Metric; LCSC C25744
R56: 27k; R_0603_1608Metric; LCSC C25744
R64, R65: 0R; R_0603_1608Metric; LCSC C25744
R66, R67, R68, R69, R70: 1k; R_0603_1608Metric; LCSC C25744
R71: 47k; R_0402_1005Metric; LCSC C25897
R72: 12k; R_0402_1005Metric; LCSC C25897
SW1: RST; SW_Push_1P1T_XKB_TS-1187A; LCSC C318884
SW2: BOOT; SW_Push_1P1T_XKB_TS-1187A; LCSC C318884
TH1: 103AT 10k; PinHeader_1x02_P2.54mm_Vertical
TP1: CCFG; TestPoint_Pad_2.0x2.0mm
TP2: CMPIN; TestPoint_Pad_2.0x2.0mm
TP3: CMPOUT; TestPoint_Pad_2.0x2.0mm
U1: HUSB238; DFN-10_L3.0-W3.0-P0.50-BL-EP2.5; LCSC Part C7471904
U2: LTC2943; DFN-8_DD_LIT; LCSC C107797
U3: BQ7791501PWR; SOP65P640X120-24N; PARTREV H; LCSC C2876946
U4: BQ25713RSNR; RSN0032B; LCSC C2878935
U5: ESP32-S3-MINI-1; ESP32-S2-MINI-1; LCSC C3013941
U6: TVS2200DRV; WSON-6-1EP_2x2mm_P0.65mm_EP1x1.6mm; LCSC C523793
U7: TPS564257DRLR; SOT50P160X60-6N; PARTREV A; LCSC C19272233

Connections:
+3.3V: C5.1, C6.1, C56.2, C57.2, C58.1, L1.2, R8.2, R11.2, R12.2, R13.2, R14.2, R47.2, R48.2, R49.2, R50.2, R51.2, R54.2, R58.2, U5.3 (3V3)
/3V3_SW: L1.1, U7.2 (SW)
/BATDRV_N: Q8.4 (G), U4.21 (BATDRV_N)
/BMS_SRN: C18.1, C20.1, R21.2, U3.11 (SRN)
/BMS_SRP: C18.2, C19.1, R22.2, U3.10 (SRP)
/BTST1: C38.2, U4.30 (BTST1)
/BTST2: C39.2, U4.25 (BTST2)
/C1: BT3.2 (-), BT4.1 (+), R17.1, R69.1
/C2: BT2.2 (-), BT3.1 (+), R16.1, R68.1
/C3: BT1.2 (-), BT2.1 (+), R15.1, R67.1
/C4: BT1.1 (+), C24.1, C25.1, C26.1, R9.4, R10.1, R19.1, R30.2, R37.1, R66.1
/CBI: R32.1, U3.16 (CBI), U5.13 (IO9)
/CC1: J1.A5 (CC1), U1.4 (CC1)
/CC2: J1.B5 (CC2), U1.5 (CC2)
/CELL_BATPRES: R40.1, R41.2, U4.18 (CELL_BATPRES)
/CHG: Q2.4 (G), R23.2, R25.2
/CHRG_OK: R48.1, U4.4 (CHRG_OK), U5.9 (IO5)
/CMPOUT: R45.2, R47.1, TP3.1, U4.15 (CMPOUT), U5.11 (IO7)
/COMP1: C51.1, R53.2, U4.16 (COMP1)
/COMP2: C50.1, R52.2, U4.17 (COMP2)
/D+: J1.A6 (D+), J1.B6 (D+), U1.2 (D+)
/D-: J1.A7 (D-), J1.B7 (D-), U1.3 (D-)
/DSG: D1.1 (K), D2.1 (K), Q3.4 (G), R26.2, R27.2
/EN: C7.2, R58.1, SW1.1 (A), U5.45 (EN)
/EN_OTG: R49.1, U4.5 (EN_OTG), U5.10 (IO6)
/HIDRV1: Q4.4 (G), U4.31 (HIDRV1)
/HIDRV2: Q7.4 (G), U4.24 (HIDRV2)
/IADPT: C54.2, R55.2, U4.8 (IADPT), U5.14 (IO10)
/IBAT: C53.2, U4.9 (IBAT), U5.15 (IO11)
/ILIM_HIZ: R42.1, R43.2, U4.6 (ILIM_HIZ)
/IO0: SW2.1 (A), U5.4 (IO0)
/LD: R28.2, U3.14 (LD)
/LED1: R59.1, U5.16 (IO12)
/LED2: R60.1, U5.17 (IO13)
/LED3: R61.1, U5.18 (IO14)
/LED4: R62.1, U5.19 (IO15)
/LED5: R63.1, U5.20 (IO16)
/LODRV1: Q5.4 (G), U4.29 (LODRV1)
/LODRV2: Q6.4 (G), U4.26 (LODRV2)
/PRES: R30.1, U3.22 (PRES), U5.12 (IO8)
/PROCHOT_N: R54.1, U4.11 (PROCHOT_N), U5.8 (IO4)
/REGN: C47.1, R44.2, U4.28 (REGN)
/RXD0: U5.40 (RXD0)
/SCL: J5.2, R50.1, R64.2, U1.7 (SCL), U2.4 (SCL), U4.13 (SCL)
/SDA: J5.1, R51.1, R65.2, U1.6 (SDA), U2.5 (SDA), U4.12 (SDA)
/SRN: R39.1, U4.19 (SRN)
/SRP: R38.1, U4.20 (SRP)
/SW1: C38.1, L2.1, Q4.1 (S), Q4.2 (S), Q4.3 (S), Q5.5 (D), U4.32 (SW1)
/SW2: C39.1, L2.2, Q6.5 (D), Q7.1 (S), Q7.2 (S), Q7.3 (S), U4.23 (SW2)
/TXD0: U5.39 (TXD0)
/USB_D+: J2.3, U5.24 (IO20)
/USB_D-: J2.2, U5.23 (IO19)
/USB_VBUS: J2.1
/VBUS: C8.1, C9.1, C10.1, C28.1, C29.1, C30.1, C31.1, C32.1, C33.1, C36.1, Q1.5 (D), R33.2, R34.4, U4.1 (VBUS), U6.4 (IN), U6.5 (IN), U6.6 (IN)
/VC0: C16.2, C17.1, R18.2, U3.8 (VC0)
/VC1: C15.2, C16.1, C23.1, D12.1 (K), R17.2, U3.7 (VC1)
/VC2: C14.2, C15.1, D11.1 (K), R16.2, U3.6 (VC2)
/VC3: C13.2, C14.1, D10.1 (K), R15.2, U3.5 (VC3)
/VC4: C13.1, D3.1 (A1), D9.1 (K), R10.2, U3.3 (VC5), U3.4 (VC4)
/VDDA: C48.1, R40.2, R42.2, R44.1, U4.7 (VDDA)
/VSYS: C40.1, C41.1, C42.1, C43.1, C44.1, C45.1, Q7.5 (D), Q8.1 (S), Q8.2 (S), Q8.3 (S), U4.22 (VSYS)
/~ALCC: R8.1, U2.6 (*ALCC), U5.7 (IO3)
GND: C1.2, C2.2, C3.2, C4.2, C5.2, C6.2, C7.1, C8.2, C9.2, C10.2, C22.2, C27.2, C28.2, C29.2, C30.2, C31.2, C32.2, C33.2, C34.2, C35.2, C36.2, C37.2, C40.2, C41.2, C42.2, C43.2, C44.2, C45.2, C46.2, C47.2, C48.2, C49.2, C50.2, C51.2, C52.2, C53.1, C54.1, C56.1, C57.1, C58.2, D1.2 (A), D4.1 (K), D5.1 (K), D6.1 (K), D7.1 (K), D8.1 (K), D13.1 (K), D14.1 (K), H1.1, H2.1, H3.1, J1.A1 (GND), J1.A12 (GND), J1.B1 (GND), J1.B12 (GND), J2.6, J2.MP (MountPin), J3.6, J3.7, J3.8, J3.9, J3.10, J3.MP (MountPin), Q3.1 (S), Q3.2 (S), Q3.3 (S), Q5.1 (S), Q5.2 (S), Q5.3 (S), Q6.1 (S), Q6.2 (S), Q6.3 (S), R1.2, R5.2, R6.2, R7.2, R26.1, R28.1, R41.1, R43.1, R46.1, R56.1, R57.1, R72.1, SW1.2 (B), SW2.2 (B), U1.11 (GND), U2.2 (GND), U2.3 (GND), U2.7 (GND), U2.9 (EPAD), U4.10 (PSYS), U4.27 (PGND), U4.33 (PAD), U5.1 (GND), U5.2 (GND), U5.42 (GND), U5.43 (GND), U5.46 (GND), U5.47 (GND), U5.48 (GND), U5.49 (GND), U5.50 (GND), U5.51 (GND), U5.52 (GND), U5.53 (GND), U5.54 (GND), U5.55 (GND), U5.56 (GND), U5.57 (GND), U5.58 (GND), U5.59 (GND), U5.60 (GND), U5.61 (GND), U5.62 (GND), U5.63 (GND), U5.64 (GND), U5.65 (GND), U6.1 (GND), U6.2 (GND), U6.3 (GND), U6.7 (GND), U7.3 (GND)
GNDPWR: BT4.2 (-), C11.2, C12.2, C17.2, C19.2, C20.2, C23.2, C24.2, C25.2, C26.2, D3.2 (A2), R18.1, R20.1, R29.2, R32.2, TH1.2, U3.9 (VSS), U3.23 (CTRC), U3.24 (CTRD)
unnamed: C21.1, Q2.1 (S), Q2.2 (S), Q2.3 (S), R20.4, R25.1
unnamed: C21.2, C22.1
unnamed: C27.1, R33.1
unnamed: C34.1, R34.3, R35.2
unnamed: C35.1, R34.2, R36.2
unnamed: C46.1, C55.1, R37.3, R38.2
unnamed: C49.1, R52.1
unnamed: C52.1, R53.1
unnamed: C55.2, R37.2, R39.2
unnamed: D2.2 (A), R24.2, R27.1
unnamed: D4.2 (A), R59.2
unnamed: D5.2 (A), R60.2
unnamed: D6.2 (A), R61.2
unnamed: D7.2 (A), R62.2
unnamed: D8.2 (A), R63.2
unnamed: D9.2 (A), R66.2
unnamed: D10.2 (A), R67.2
unnamed: D11.2 (A), R68.2
unnamed: D12.2 (A), R69.2
unnamed: D13.2 (A), R70.2
unnamed: D14.2 (A), R11.1
unnamed: J1.S1 (SHIELD), R1.1
unnamed: J1.A4 (VBUS), J1.A9 (VBUS), J1.B4 (VBUS), J1.B9 (VBUS), Q1.1 (S), Q1.2 (S), Q1.3 (S), R2.1, R4.2
unnamed: J4.1, U5.22 (IO18)
unnamed: J4.2, U5.21 (IO17)
unnamed: Q1.4 (G), R3.2, R4.1
unnamed: Q2.5 (D), Q3.5 (D)
unnamed: C37.1, Q4.5 (D), R34.1
unnamed: Q8.5 (D), R37.4
unnamed: R20.2, R21.1
unnamed: R20.3, R22.1
unnamed: R55.1, R56.2
unnamed: R3.1, U1.10 (GATE)
unnamed: R5.1, U1.9 (ISET)
unnamed: C1.1, R2.2, U1.1 (VIN)
unnamed: R6.1, R7.1, U1.8 (VSET)
unnamed: R9.2, U2.1 (SENSE+)
unnamed: R9.3, U2.8 (SENSE-)
unnamed: C12.1, U3.2 (AVDD)
unnamed: C11.1, R19.2, TP1.1, U3.1 (VDD), U3.20 (CCFG)
unnamed: R23.1, U3.13 (CHG)
unnamed: R24.1, U3.12 (DSG)
unnamed: R29.1, U3.17 (OCDP)
unnamed: R31.2, TH1.1, U3.18 (TS)
unnamed: R31.1, U3.19 (VTB)
unnamed: R36.1, U4.2 (ACN)
unnamed: R35.1, U4.3 (ACP)
unnamed: R45.1, R46.2, TP2.1, U4.14 (CMPIN)
unnamed: R64.1, U5.5 (IO1)
unnamed: R65.1, U5.6 (IO2)
unnamed: R71.1, R72.2, U7.5 (EN)
unnamed: R13.1, R14.1, R57.2, U7.6 (FB)
unnamed: R12.1, U7.4 (PG)
VDD: C2.1, C3.1, C4.1, J3.1, J3.2, J3.3, J3.4, J3.5, R9.1, R70.1, R71.2, U7.1 (VIN)

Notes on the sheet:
hystersis
5A max
ILIM = 2.9A
USB-CDC based
CCFG tie to AVDD for 4 cell
78% w.r.t VDDA

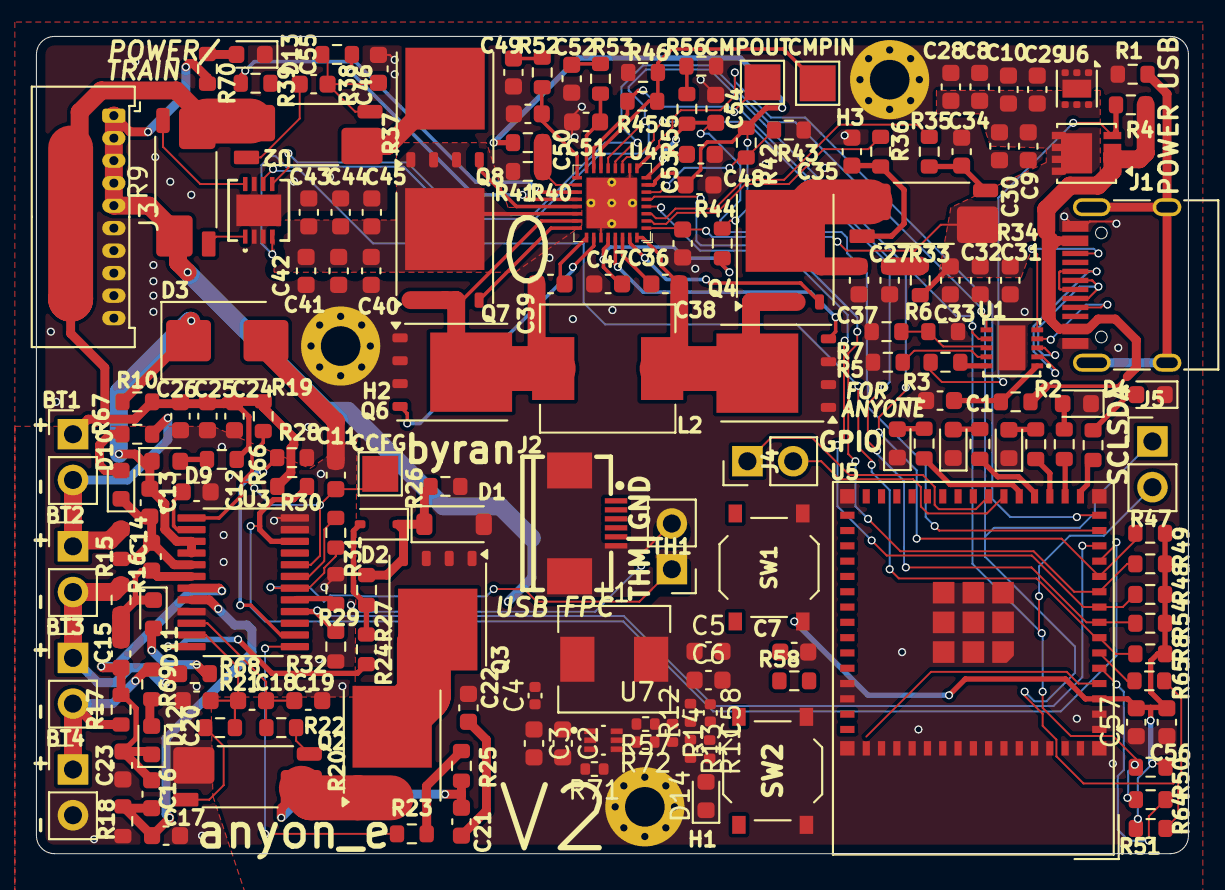
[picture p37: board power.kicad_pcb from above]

Board: 4 copper layers, 64.0 x 45.4 mm, 179 parts (0 on the bottom side), 115 nets.

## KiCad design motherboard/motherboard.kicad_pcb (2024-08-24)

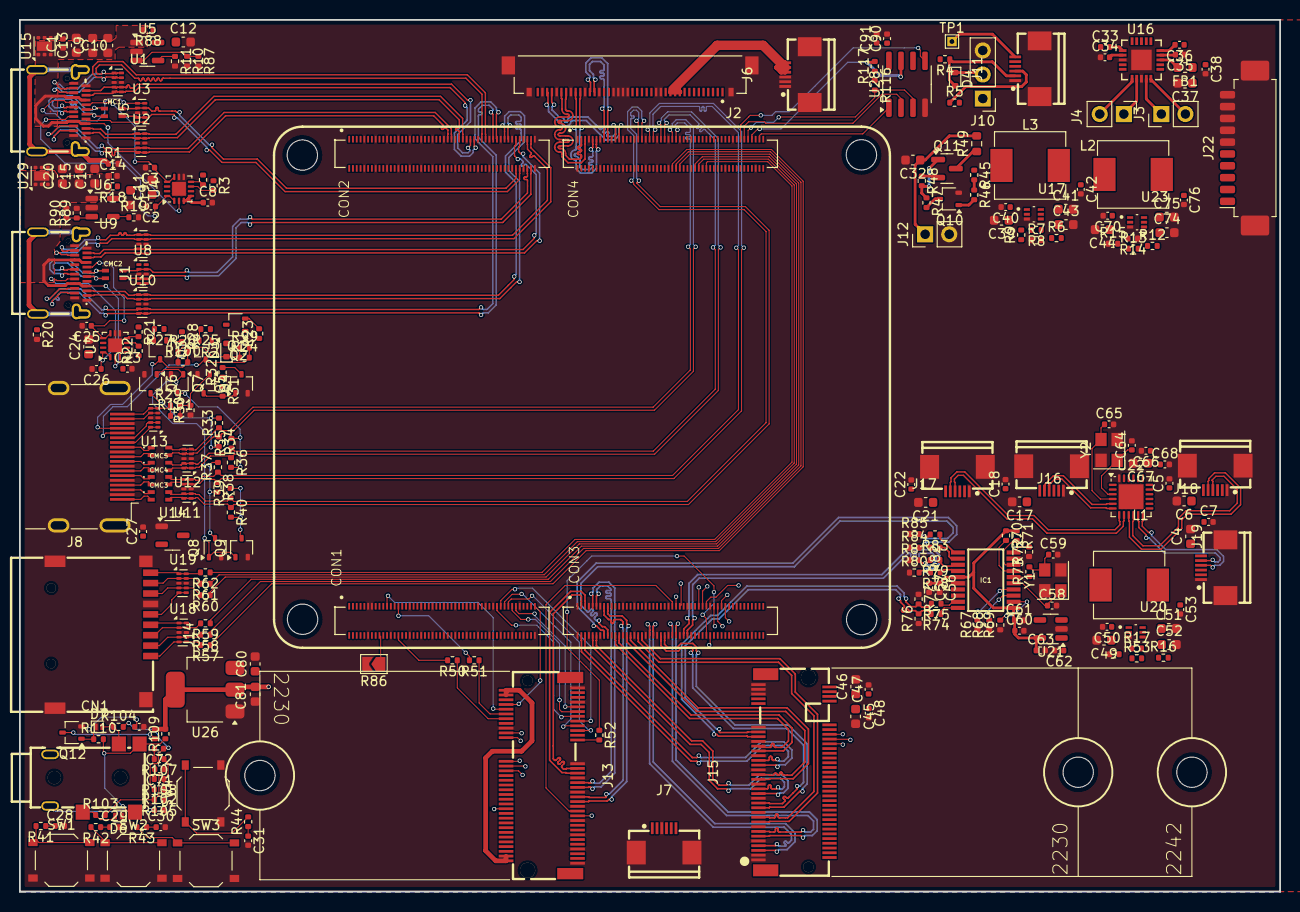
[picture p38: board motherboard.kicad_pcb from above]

Board: 6 copper layers, 133.0 x 92.0 mm, 257 parts (0 on the bottom side), 253 nets.

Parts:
C1, C14: 100nF (+25V); C_0402_1005Metric
C2, C3, C25, C26: 220pF; C_0402_1005Metric
C4, C6, C11, C12, C13, C17, C19, C20, C21, C24, C32, C37, C67, C80, C81: 10uF; C_0603_1608Metric
C5, C7, C18, C22, C38, C48, C66, C71, C72, C90: 0.1uF; C_0402_1005Metric
C8, C23, C40, C42, C50, C53, C56, C61, C70, C76: 100nF; C_0402_1005Metric
C9, C10, C15, C16: 10uF (C913517); C_0603_1608Metric
C27, C33, C34, C35, C36, C47, C57, C60, C62, C63, C68, C73, C91: 1uF; C_0402_1005Metric
C28, C29, C30, C31: 1nF; C_0402_1005Metric
C39, C41, C43, C44, C45, C46, C49, C51, C52, C74, C75: 22uF; C_0603_1608Metric
C58, C59, C64, C65: 15pF; C_0402_1005Metric
CMC1, CMC2, CMC3, CMC4, CMC5, CMC6: ACM2012; FIL_ACM2012-900-2P-T001
CN1: PJ-332A-6A (3.5mm Jack); AUDIO-SMD_PJ-332A-6A
D3, D4: LRB521S-30T1G; D_SOD-523
D6, D7: LESD8D5.0CB1T5G; D_SOD-882
FB1: GZ1608D601TF; L_0603_1608Metric
IC1: PI6C557-05BLE; SOP65P640X120-20N
J1: USB_C_Receptacle; USB-C-SMD_TYPE-C-24P-QT
J2: 20455-040E-76 OLED IPEX; IPEX_20455-040E-76
J3: RIGHT SPEAKERS; PinHeader_1x02_P2.54mm_Vertical
J4: LEFT SPEAKERS; PinHeader_1x02_P2.54mm_Vertical
J5: Outer USB-C; USB-C-SMD_TYPE-C-24P-QT
J6: OLED EL POWER; FPC-SMD_6P-P0.50_XUNPU_FPC-05F-6PH20
J7: HALL SWITCH; FPC-SMD_6P-P0.50_XUNPU_FPC-05F-6PH20
J8: HDMI_A; HDMI_A_Molex_208658-1001_Horizontal
J10: DEBUG UART; PinHeader_1x03_P2.54mm_Vertical
J11: SYSTEM; FPC-SMD_6P-P0.50_XUNPU_FPC-05F-6PH20
J12: 5V FAN; PinHeader_1x02_P2.54mm_Vertical
J13: Bus_M.2_Socket_E; CONN-SMD_APCI0147-P001A
J14: Micro_SD_Card_Det1; TF-SMD_TF-CARD-H1.8
J15: Bus_M.2_Socket_M; CONN-SMD_AS0BC21-S30BM-7H
J16, J17, J18, J19: USB; FPC-SMD_6P-P0.50_XUNPU_FPC-05F-6PH20
J20: CM3588 Hirose Connector; CM3588
J22: BATTERY IN; Molex_PicoBlade_53261-1071_1x10-1MP_P1.25mm_Horizontal
L1, L3: MWSA0603S-3R3MT; L_Sunlord_MWSA0603S
L2: FXL0630-4R7-M; L_Sunlord_MWSA0603S
Q1, Q2, Q4, Q5, Q10, Q12: 2SK3018W; SOT-323_SC-70
Q3: L2N7002WT1G; SOT-323_SC-70
Q6, Q7, Q8, Q9: WNM6002-3/TR; SOT-323_SC-70
Q11: AO3415A; SOT-23
R1, R20: 1M; R_0402_1005Metric
R2, R3, R21, R22, R52, R111: 2.2k; R_0402_1005Metric
R4, R6, R7, R12, R16, R25, R27, R31, R32, R45, R54, R70, R71, R105, R106, R110, R116, R117: 10k; R_0402_1005Metric
R5, R57, R58, R59, R60, R61, R62, R74, R75, R78, R79, R82, R83, R107, R108: 33R; R_0402_1005Metric
R8, R17: 49.9k; R_0402_1005Metric
R9, R53: 510k; R_0402_1005Metric
R10, R87, R89, R90: 6.8k; R_0402_1005Metric
R11, R19, R109: 100k; R_0402_1005Metric
R13: 220k; R_0402_1005Metric
R14: 33k; R_0402_1005Metric
R15: 330k; R_0402_1005Metric
R18, R50, R51, R68, R69, R88, R102, R103, R104: 0R; R_0402_1005Metric
R23: 27k; R_0402_1005Metric
R24, R100, R101: 18k; R_0402_1005Metric
R26, R29, R99: 2k; R_0402_1005Metric
R28, R47: 1k; R_0402_1005Metric
R30: 47k; R_0402_1005Metric
R33, R34, R35, R36, R37, R38, R39, R40: 499R; R_0402_1005Metric
R41, R42, R43, R44, R46, R73: 100R; R_0402_1005Metric
R48, R72: 470R; R_0402_1005Metric
R49: 2.2R; R_0603_1608Metric
R67: 4.7k; R_0402_1005Metric
R76, R77, R80, R81, R84, R85: 49.9R; R_0402_1005Metric
R86: 0R; SolderJumper-2_P1.3mm_Open_TrianglePad1.0x1.5mm
SW1: PWR; SW_Push_1P1T_XKB_TS-1187A
SW2: RESET; SW_Push_1P1T_XKB_TS-1187A
SW3: MASK; SW_Push_1P1T_XKB_TS-1187A
SW4: RECOVERY; SW_Push_1P1T_XKB_TS-1187A
TP1: PWRON; TestPoint_THTPad_1.0x1.0mm_Drill0.5mm
U1, U2, U3, U8, U9, U10, U11, U12, U13, U18, U19: TPD4E02B04; USON-10_2.5x1.0mm_P0.5mm
U4, U7: FUSB302BMPX; WQFN-14-1EP_2.5x2.5mm_P0.5mm_EP1.45x1.45mm
U5, U6: SY6280AAC; SOT-23-5
U14: AP2331; SOT-23-3
U15, U29: TVS2200DRV; WSON-6-1EP_2x2mm_P0.65mm_EP1x1.6mm
U16: TPA2016D2RTJR; QFN50P400X400X80-21N
U17, U20, U23: TPS564257DRLR; SOT50P160X60-6N
U21: AP2127K-3.3; SOT-23-5
U22: CH334F; QFN-24-1EP_4x4mm_P0.5mm_EP2.6x2.6mm
U26: AMS1117-1.8; SOT-223-3_TabPin2
U28: SPI Flash; SOIC-8_3.9x4.9mm_P1.27mm
Y1: 25MHz; Crystal_SMD_3225-4Pin_3.2x2.5mm
Y2: 12MHz; Crystal_SMD_3225-4Pin_3.2x2.5mm

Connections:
+1V8: C81.1, R45.1, R109.2, R111.2, U26.2 (VO)
+3.3V: C8.1, C23.1, C41.1, C42.1, C43.1, C66.1, C67.1, C80.1, C90.1, C91.1, J2.17, J2.18, J2.19, J7.1, L3.2, Q2.1 (G), R2.1, R3.1, R4.2, R6.2, R21.1, R22.1, R23.1, R25.1, R27.1, R28.1, R31.1, R32.1, R116.1, R117.1, U4.3 (VDD), U4.4 (VDD), U7.3 (VDD), U7.4 (VDD), U21.3 (EN), U22.20 (VDD33), U26.3 (VI), U28.8 (VCC)
+3.3V_PCIE: C45.1, C46.1, C47.1, C48.1, C51.1, C52.1, C53.1, J13.2 (3.3V), J13.4 (3.3V), J13.72 (3.3V), J13.74 (3.3V), J15.2 (3.3V), J15.4 (3.3V), J15.12 (3.3V), J15.14 (3.3V), J15.16 (3.3V), J15.18 (3.3V), J15.70 (3.3V), J15.72 (3.3V), J15.74 (3.3V), L1.2, R16.2
+5V: C4.1, C5.1, C6.1, C7.1, C11.1, C12.1, C17.1, C18.1, C19.1, C21.1, C22.1, C24.1, C37.1, C38.1, C62.1, C68.1, C74.1, C75.1, C76.1, D3.2 (A), FB1.1, J16.6, J17.6, J18.6, J19.6, L2.2, Q1.1 (G), Q11.2 (S), R12.2, R18.1, R48.1, R88.1, U4.12 (VCONN), U4.13 (VCONN), U5.5 (IN), U6.5 (IN), U7.12 (VCONN), U7.13 (VCONN), U14.3 (IN), U16.4 (PVDDL_2), U16.5 (PVDDL), U16.11 (PVDDR_2), U16.12 (PVDDR), U21.1 (VIN), U22.19 (V5)
/Audio/L_AUDIO: C33.1, C72.1, J20.104, R104.2, R106.2
/Audio/L_DET: CN1.5, CN1.6, R109.1, R110.2
/Audio/L_HP: CN1.4, D7.2 (A2), R104.1
/Audio/MIC: CN1.1, R102.1
/Audio/R_AUDIO: C36.1, C71.1, J20.103, R103.2, R105.2
/Audio/R_HP: CN1.3, D6.2 (A2), R103.1
/BOOT_SARADC_IN0: C30.1, J20.15, R43.1
/GPIO0_A4/SDMMC_DET_L: J20.370, R62.1
/GPIO0_B2: J13.21 (~SDIO_WAKE), J20.247
/GPIO0_C4/UART0_RX_M0: J20.270, R52.1
/GPIO0_C5/UART0_TX_M0/PWM4_M0: J13.20 (~UART_WAKE), J20.272
/GPIO0_D3/CC_INT_L: J20.264, U4.5 (INT_N)
/GPIO0_D5: J20.268, U7.5 (INT_N)
/GPIO1_A0/UART6_RX_M1: J13.22 (UART_RXD), J20.273
/GPIO1_A1/UART6_TX_M1: J13.32 (UART_TXD), J20.275
/GPIO1_A2/I2C4_SDA_M3_TP: J13.36 (UART_RTS), J20.277
/GPIO1_A3/I2C4_SCL_M3_TP: J13.34 (UART_CTS), J20.279
/GPIO1_A4: J20.281, U28.6 (SCK)
/GPIO1_A7: J20.283, U16.18 (SDZ)
/GPIO1_C4/HP_DET_L: J20.108, Q12.3 (D), R111.1
/GPIO1_D2/TYPEC5V_PWREN_H: J20.239, R11.1, R19.1, U5.4 (ON), U6.4 (ON)
/GPIO1_D3/PWM1_M1: J20.241, R45.2, R46.1
/GPIO2_A6: J13.13 (SDIO_DATA0), J20.79
/GPIO2_A7: J13.15 (SDIO_DATA1), J20.81
/GPIO2_B0: J13.17 (SDIO_DATA2), J20.83
/GPIO2_B1: J13.19 (SDIO_DATA3), J20.85
/GPIO2_B2: J13.11 (SDIO_CMD), J20.87
/GPIO2_B3: J13.9 (SDIO_CLK), J20.89
/GPIO2_B7: J13.8 (PCM_CLK/I2S_SCK), J20.99
/GPIO2_C0: J13.10 (PCM_SYNC/I2S_WS), J20.21
/GPIO2_C3: J20.27, R51.2
/GPIO3_A0/SPI4_MISO_M1/PWM10_M0: J20.387, U28.5 (SI/IO0)
/GPIO3_A1/SPI4_MOSI_M1: J20.389, U28.2 (SO/IO1)
/GPIO3_A2/SPI4_CLK_M1/UART8_TX_M1: J20.391, R116.2, U28.3 (~WP/IO2)
/GPIO3_A3/SPI4_CS0_M1/UART8_RX_M1: J20.393, R117.2, U28.7 (~HOLD/IO3)
/GPIO3_A5: J20.397, U28.1 (~CS)
/GPIO3_A6/LCD_RST: J13.42 (VENDOR_DEFINED), J20.399
/GPIO4_A0/TP_2_INT_L: J13.53 (~CLKREQ0), J20.251
/GPIO4_A1/TP_2_RST_L: J13.55 (~PEWAKE0), J20.253
/GPIO4_A2: J13.52 (~PERST0), J20.255
/GPIO4_B4/PCIE30X4_CLKREQn_M1_L: J15.52 (~CLKREQ), J20.265
/GPIO4_B5/PCIE30X4_WAKEn_M1_L: J15.54 (~PEWAKE), J20.267
/GPIO4_B6/PCIE30X4_PERSTn_M1_L: J15.50 (~PERST), J20.269
/GPIO4_C2: J7.2, J20.26
/GPIO4_C3: J20.28, R50.2
/HDMI0_TX_ON_H: J20.369, Q6.1 (G), Q7.1 (G), Q8.1 (G), Q9.1 (G)
/HDMI1_TX0N: J2.29, J20.317
/HDMI1_TX0P: J2.28, J20.315
/HDMI1_TX1N: J2.32, J20.311
/HDMI1_TX1P: J2.31, J20.309
/HDMI1_TX2N: J2.35, J20.305
/HDMI1_TX2P: J2.34, J20.303
/HDMI1_TX3N: J2.38, J20.323
/HDMI1_TX3P: J2.37, J20.321
/HDMI1_TX_SBDN: J2.25, J20.329
/HDMI1_TX_SBDP: J2.26, J20.327
/HDMITX0_CEC_M0: J20.367, Q1.2 (S), R23.2
/HDMITX0_HPDIN_M0: J20.295, Q5.3 (D), R32.2
/HDMITX0_SCL_M0: J20.363, Q2.2 (S), R25.2
/HDMITX0_SDA_M0: J20.365, Q3.2 (S), R27.2
/HDMI_TX/CEC: J8.13 (CEC), Q1.3 (D), U13.1 (D1+), U13.10 (NC)
/HDMI_TX/HDMI0_5V: C27.1, J8.18 (+5V), U13.4 (D2+), U13.7 (NC), U14.2 (OUT)
/HDMI_TX/HDMI0_TX0N: CMC5.4, J20.347, R35.1, U12.2 (D1-), U12.9 (NC)
/HDMI_TX/HDMI0_TX0P: CMC5.3, J20.345, R36.1, U12.1 (D1+), U12.10 (NC)
/HDMI_TX/HDMI0_TX1N: CMC4.4, J20.341, R37.1, U11.5 (D2-), U11.6 (NC)
/HDMI_TX/HDMI0_TX1P: CMC4.3, J20.339, R38.1, U11.4 (D2+), U11.7 (NC)
/HDMI_TX/HDMI0_TX2N: CMC3.4, J20.335, R39.1, U11.2 (D1-), U11.9 (NC)
/HDMI_TX/HDMI0_TX2P: CMC3.3, J20.333, R40.1, U11.1 (D1+), U11.10 (NC)
/HDMI_TX/HDMI0_TX3N: CMC6.4, J20.353, R33.1, U12.5 (D2-), U12.6 (NC)
/HDMI_TX/HDMI0_TX3P: CMC6.3, J20.351, R34.1, U12.4 (D2+), U12.7 (NC)
/HDMI_TX/IN_TX0N: CMC5.1, J8.9 (D0-)
/HDMI_TX/IN_TX0P: CMC5.2, J8.7 (D0+)
/HDMI_TX/IN_TX1N: CMC4.1, J8.6 (D1-)
/HDMI_TX/IN_TX1P: CMC4.2, J8.4 (D1+)
/HDMI_TX/IN_TX2N: CMC3.1, J8.3 (D2-)
/HDMI_TX/IN_TX2P: CMC3.2, J8.1 (D2+)
/HDMI_TX/IN_TX3N: CMC6.1, J8.12 (CK-)
/HDMI_TX/IN_TX3P: CMC6.2, J8.10 (CK+)
/HDMI_TX/SBDN: J8.19 (HPD), J20.359, R29.1, R101.1, U13.5 (D2-), U13.6 (NC)
/HDMI_TX/SBDP: J8.14 (UTILITY), J20.357, U13.2 (D1-), U13.9 (NC)
/HDMI_TX/SCL: J8.15 (SCL), Q2.3 (D), R24.2, R99.2
/HDMI_TX/SDA: J8.16 (SDA), Q3.3 (D), R26.2, R100.2
/I2C6_SCL_M0: J20.296, R3.2, U4.6 (SCL), U16.19 (SDA)
/I2C6_SDA_M0: J20.298, R2.2, U4.7 (SDA), U16.17 (SCL)
/I2C7_SCL_M0: J20.107, R22.2, U7.6 (SCL)
/I2C7_SDA_M0: J20.105, R21.2, U7.7 (SDA)
/MIC_IN: J20.106, R102.2
/PCIE3.0-MKEY/+3.3V_PI6C: C56.1, C57.1, C60.1, C61.1, C63.1, IC1.1 (VDDXD), IC1.15 (VDDODA), R70.1, R71.1, U21.5 (VOUT)
/PCIE3.0-MKEY/CLK2N: IC1.13 (~CLK2), R79.1
/PCIE3.0-MKEY/CLK2P: IC1.14 (CLK2), R78.1
/PCIE3.0-MKEY/CLK3N: IC1.11 (~CLK3), R83.1
/PCIE3.0-MKEY/CLK3P: IC1.12 (CLK3), R82.1
/PCIE3.0-MKEY/PCIE30_REFCLK_A_N: J15.53 (REFCLKn), R75.2, R77.2
/PCIE3.0-MKEY/PCIE30_REFCLK_A_P: J15.55 (REFCLKp), R74.2, R76.2
/PCIE3.0-MKEY/X1: C58.1, IC1.5 (X1), Y1.1
/PCIE3.0-MKEY/X2: IC1.6 (X2), R73.1
/PCIE20_1_REFCLKN: J13.49 (REFCLKn0), J20.217
/PCIE20_1_REFCLKP: J13.47 (REFCLKp0), J20.215
/PCIE20_1_RXN: J13.41 (PERp0), J20.211
/PCIE20_1_RXP: J13.43 (PERn0), J20.209
/PCIE20_1_TXN: J13.37 (PETn0), J20.205
/PCIE20_1_TXP: J13.35 (PETp0), J20.203
/PCIE30_PORT0_REFCLKN: J20.218, R83.2, R85.2
/PCIE30_PORT0_REFCLKP: J20.216, R82.2, R84.2
/PCIE30_PORT0_RX0N: J15.41 (PERn0/SATA-B+), J20.206
/PCIE30_PORT0_RX0P: J15.43 (PERp0/SATA-B-), J20.204
/PCIE30_PORT0_RX1N: J15.29 (PERn1), J20.212
/PCIE30_PORT0_RX1P: J15.31 (PERp1), J20.210
/PCIE30_PORT0_TX0N: J15.47 (PETn0/SATA-A-), J20.224
/PCIE30_PORT0_TX0P: J15.49 (PETp0/SATA-A+), J20.222
/PCIE30_PORT0_TX1N: J15.35 (PETn1), J20.230
/PCIE30_PORT0_TX1P: J15.37 (PETp1), J20.228
/PCIE30_PORT1_REFCLKN: J20.260, R79.2, R81.2
/PCIE30_PORT1_REFCLKP: J20.258, R78.2, R80.2
/PCIE30_PORT1_RX2N: J15.17 (PERn2), J20.236
/PCIE30_PORT1_RX2P: J15.19 (PERp2), J20.234
/PCIE30_PORT1_RX3N: J15.5 (PERn3), J20.242
/PCIE30_PORT1_RX3P: J15.7 (PERp3), J20.240
/PCIE30_PORT1_TX2N: J15.23 (PETn2), J20.248
/PCIE30_PORT1_TX2P: J15.25 (PETp2), J20.246
/PCIE30_PORT1_TX3N: J15.11 (PETn3), J20.254
/PCIE30_PORT1_TX3P: J15.13 (PETp3), J20.252
/PMIC_EXT_EN_OUT: J20.19, U17.5 (EN), U20.5 (EN), U23.5 (EN)
/PWRON_L: C28.1, J20.17, R41.1
/RECOVERY: C31.1, J20.101, R44.1
/RESET_L: C29.1, J20.16, R42.1
/SD Card/CLK: J14.5 (CLK), J20.360, U19.5 (D2-), U19.6 (NC)
/SD Card/CMD: J14.3 (CMD), R59.2, U18.2 (D1-), U18.9 (NC)
/SD Card/D0: J14.7 (DAT0), R60.2, U19.4 (D2+), U19.7 (NC)
/SD Card/D1: J14.8 (DAT1), R61.2, U19.2 (D1-), U19.9 (NC)
/SD Card/D2: J14.1 (DAT2), R57.2, U18.5 (D2-), U18.6 (NC)
/SD Card/D3: J14.2 (DAT3/CD), R58.2, U18.4 (D2+), U18.7 (NC)
/SD Card/DET: J14.9 (DET), R62.2, U19.1 (D1+), U19.10 (NC)
/SD Card/VDD: J14.4 (VDD), J20.358, U18.1 (D1+), U18.10 (NC)
/SDMMC0_CMD: J20.356, R59.1
/SDMMC0_D0: J20.364, R60.1
/SDMMC0_D1: J20.366, R61.1
/SDMMC0_D2: J20.352, R57.1
/SDMMC0_D3: J20.354, R58.1
/System/BOOT_SARADC: J11.4, R43.2, SW3.1 (A)
/System/PWRON_L_IN: J11.6, R41.2, SW1.1 (A), TP1.1
/System/RECOVERY_IN: R44.2, SW4.1 (A)
/System/RESET_L_IN: J11.5, R42.2, SW2.1 (A)
/System/UART_RX: D4.2 (A), J11.2, J20.22, R4.1
/System/UART_TX: J11.3, J20.20, R5.1
/USB2.0/D1_N: J19.5, U22.11 (DM1)
/USB2.0/D1_P: J19.4, U22.12 (DP1)
/USB2.0/D2_N: J18.5, U22.9 (DM2)
/USB2.0/D2_P: J18.4, U22.10 (DP2)
/USB2.0/D3_N: J17.5, U22.7 (DM3)
/USB2.0/D3_P: J17.4, U22.8 (DP3)
/USB2.0/D4_N: J16.5, U22.5 (DM4)
/USB2.0/D4_P: J16.4, U22.6 (DP4)
/USB2.0/X1: C64.1, U22.3 (XO), Y2.1
/USB2.0/X2: C65.1, U22.4 (XI), Y2.3
/USB20_HOST0_DN: J20.324, U22.14 (DMU)
/USB20_HOST0_DP: J20.322, U22.15 (DPU)
/USB20_HOST1_DN: J13.5 (USB_D-), J20.318
/USB20_HOST1_DP: J13.3 (USB_D+), J20.316
/USBC0/CC1: C3.1, J5.A5 (CC1), U4.10 (CC1), U4.11 (CC1)
/USBC0/CC2: C2.1, J5.B5 (CC2), U4.1 (CC2), U4.14 (CC2)
/USBC0/D+: CMC1.4, J20.190, U3.2 (D1-), U3.9 (NC)
/USBC0/D-: CMC1.3, J20.192, U3.4 (D2+), U3.7 (NC)
/USBC0/IN_D+: CMC1.1, J5.A6 (D+), J5.B6 (D+)
/USBC0/IN_D-: CMC1.2, J5.A7 (D-), J5.B7 (D-)
/USBC0/RX1+: J5.B11 (RX1+), J20.171, U1.1 (D1+), U1.10 (NC)
/USBC0/RX1-: J5.B10 (RX1-), J20.173, U1.2 (D1-), U1.9 (NC)
/USBC0/RX2+: J5.A11 (RX2+), J20.159, U2.2 (D1-), U2.9 (NC)
/USBC0/RX2-: J5.A10 (RX2-), J20.161, U2.1 (D1+), U2.10 (NC)
/USBC0/SBUS1: J5.A8 (SBU1), J20.304, U3.5 (D2-), U3.6 (NC)
/USBC0/SBUS2: J5.B8 (SBU2), J20.306, U3.1 (D1+), U3.10 (NC)
/USBC0/TX1+: J5.A2 (TX1+), J20.165, U1.4 (D2+), U1.7 (NC)
/USBC0/TX1-: J5.A3 (TX1-), J20.167, U1.5 (D2-), U1.6 (NC)
/USBC0/TX2+: J5.B2 (TX2+), J20.153, U2.5 (D2-), U2.6 (NC)
/USBC0/TX2-: J5.B3 (TX2-), J20.155, U2.4 (D2+), U2.7 (NC)
/USBC0/VBUS: C1.1, C9.1, C10.1, C13.1, J5.A4 (VBUS), J5.A9 (VBUS), J5.B4 (VBUS), J5.B9 (VBUS), R88.2, U4.2 (VBUS), U5.1 (OUT), U15.1 (GND), U15.2 (GND), U15.3 (GND), U15.7 (GND)
/USBC1/CC1: C25.1, J1.A5 (CC1), U7.10 (CC1), U7.11 (CC1)
/USBC1/CC2: C26.1, J1.B5 (CC2), U7.1 (CC2), U7.14 (CC2)
/USBC1/D+: CMC2.4, J20.196, U8.2 (D1-), U8.9 (NC)
/USBC1/D-: CMC2.3, J20.198, U8.4 (D2+), U8.7 (NC)
/USBC1/IN_D+: CMC2.1, J1.A6 (D+), J1.B6 (D+)
/USBC1/IN_D-: CMC2.2, J1.A7 (D-), J1.B7 (D-)
/USBC1/RX1+: J1.B11 (RX1+), J20.195, U9.1 (D1+), U9.10 (NC)
/USBC1/RX1-: J1.B10 (RX1-), J20.197, U9.2 (D1-), U9.9 (NC)
/USBC1/RX2+: J1.A11 (RX2+), J20.183, U10.2 (D1-), U10.9 (NC)
/USBC1/RX2-: J1.A10 (RX2-), J20.185, U10.1 (D1+), U10.10 (NC)
/USBC1/SBUS1: J1.A8 (SBU1), J20.310, U8.5 (D2-), U8.6 (NC)
/USBC1/SBUS2: J1.B8 (SBU2), J20.312, U8.1 (D1+), U8.10 (NC)
/USBC1/TX1+: J1.A2 (TX1+), J20.189, U9.4 (D2+), U9.7 (NC)
/USBC1/TX1-: J1.A3 (TX1-), J20.191, U9.5 (D2-), U9.6 (NC)
/USBC1/TX2+: J1.B2 (TX2+), J20.177, U10.5 (D2-), U10.6 (NC)
/USBC1/TX2-: J1.B3 (TX2-), J20.179, U10.4 (D2+), U10.7 (NC)
/USBC1/VBUS: C14.1, C15.1, C16.1, C20.1, J1.A4 (VBUS), J1.A9 (VBUS), J1.B4 (VBUS), J1.B9 (VBUS), R18.2, U6.1 (OUT), U7.2 (VBUS), U29.1 (GND), U29.2 (GND), U29.3 (GND), U29.7 (GND)
/VDC_MODE: J20.18, R86.1
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

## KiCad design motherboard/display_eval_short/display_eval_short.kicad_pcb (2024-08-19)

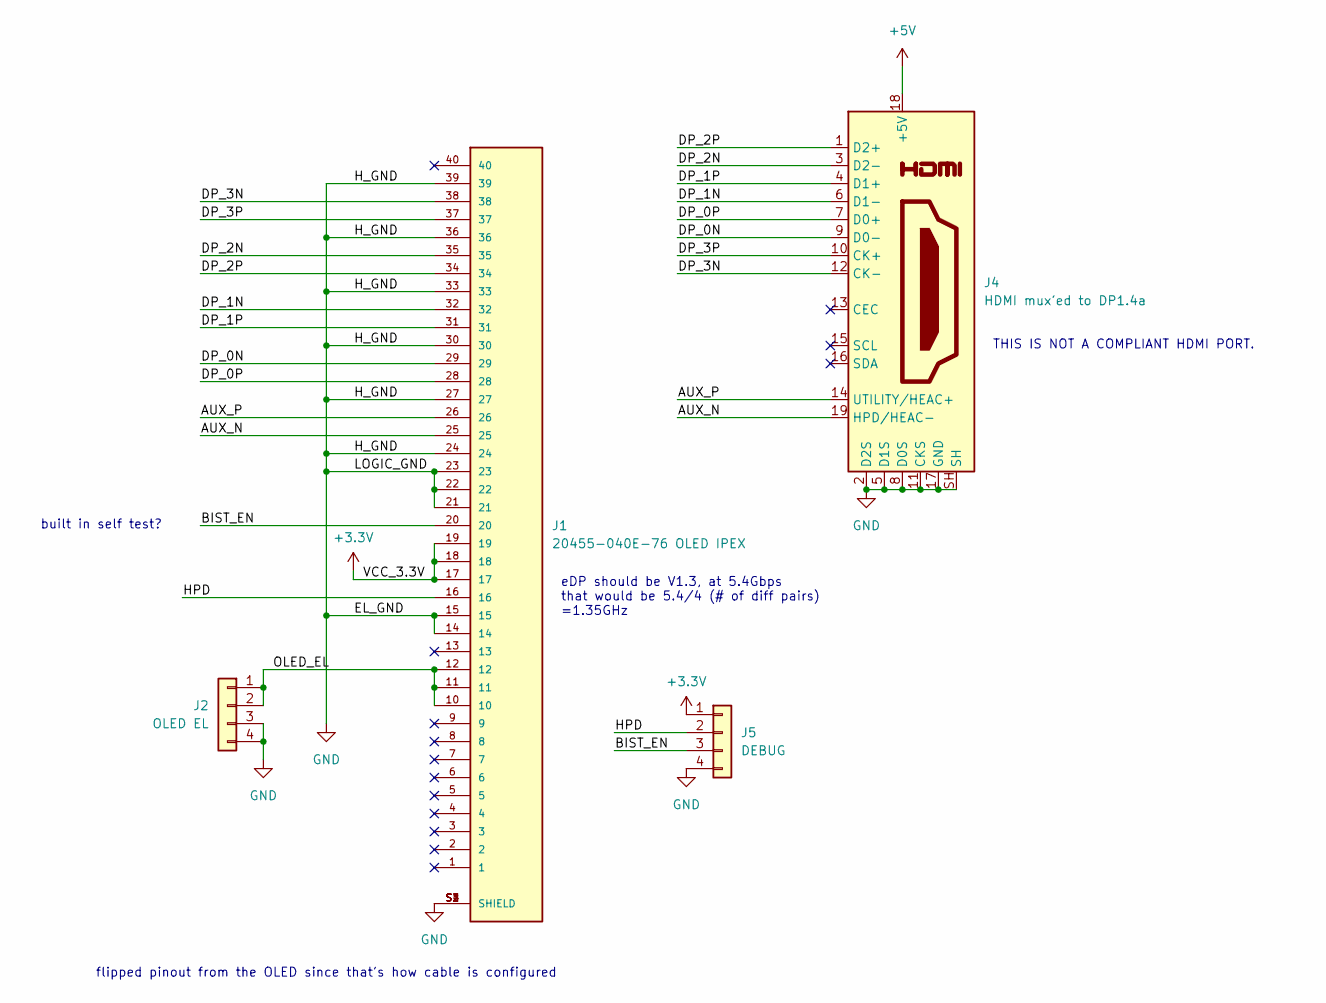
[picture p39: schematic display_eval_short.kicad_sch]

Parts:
J1: 20455-040E-76 OLED IPEX; IPEX_20455-040E-76; LCSC C7527731
J2: OLED EL; PinHeader_1x04_P2.54mm_Vertical
J4: HDMI mux'ed to DP1.4a; HDMI-SMD_HYC109-HDMIA19-160; LCSC C720616
J5: DEBUG; PinHeader_1x04_P2.54mm_Vertical

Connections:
+3.3V: J1.17, J1.18, J1.19, J5.1
+5V: J4.18 (+5V)
/AUX_N: J1.25, J4.19 (HPD/HEAC-)
/AUX_P: J1.26, J4.14 (UTILITY/HEAC+)
/BIST_EN: J1.20, J5.3
/DP_0N: J1.29, J4.9 (D0-)
/DP_0P: J1.28, J4.7 (D0+)
/DP_1N: J1.32, J4.6 (D1-)
/DP_1P: J1.31, J4.4 (D1+)
/DP_2N: J1.35, J4.3 (D2-)
/DP_2P: J1.34, J4.1 (D2+)
/DP_3N: J1.38, J4.12 (CK-)
/DP_3P: J1.37, J4.10 (CK+)
/HPD: J1.16, J5.2
/OLED_EL: J1.10, J1.11, J1.12, J2.1, J2.2
GND: J1.14, J1.15, J1.21, J1.22, J1.23, J1.24, J1.27, J1.30, J1.33, J1.36, J1.39, J1.S1 (SHIELD), J1.S2 (SHIELD), J1.S3 (SHIELD), J1.S4 (SHIELD), J2.3, J2.4, J4.2 (D2S), J4.5 (D1S), J4.8 (D0S), J4.11 (CKS), J4.17 (GND), J4.SH, J5.4

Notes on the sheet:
THIS IS NOT A COMPLIANT HDMI PORT.
eDP should be V1.3, at 5.4Gbps that would be 5.4/4 (# of diff pairs) =1.35GHz
flipped pinout from the OLED since that's how cable is configured
built in self test?

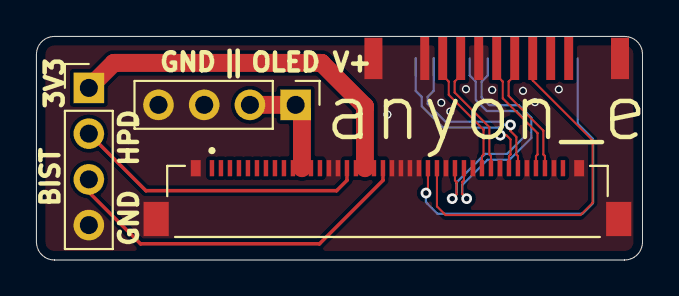
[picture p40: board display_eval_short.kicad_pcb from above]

Board: 4 copper layers, 33.7 x 12.4 mm, 4 parts (1 on the bottom side), 15 nets.

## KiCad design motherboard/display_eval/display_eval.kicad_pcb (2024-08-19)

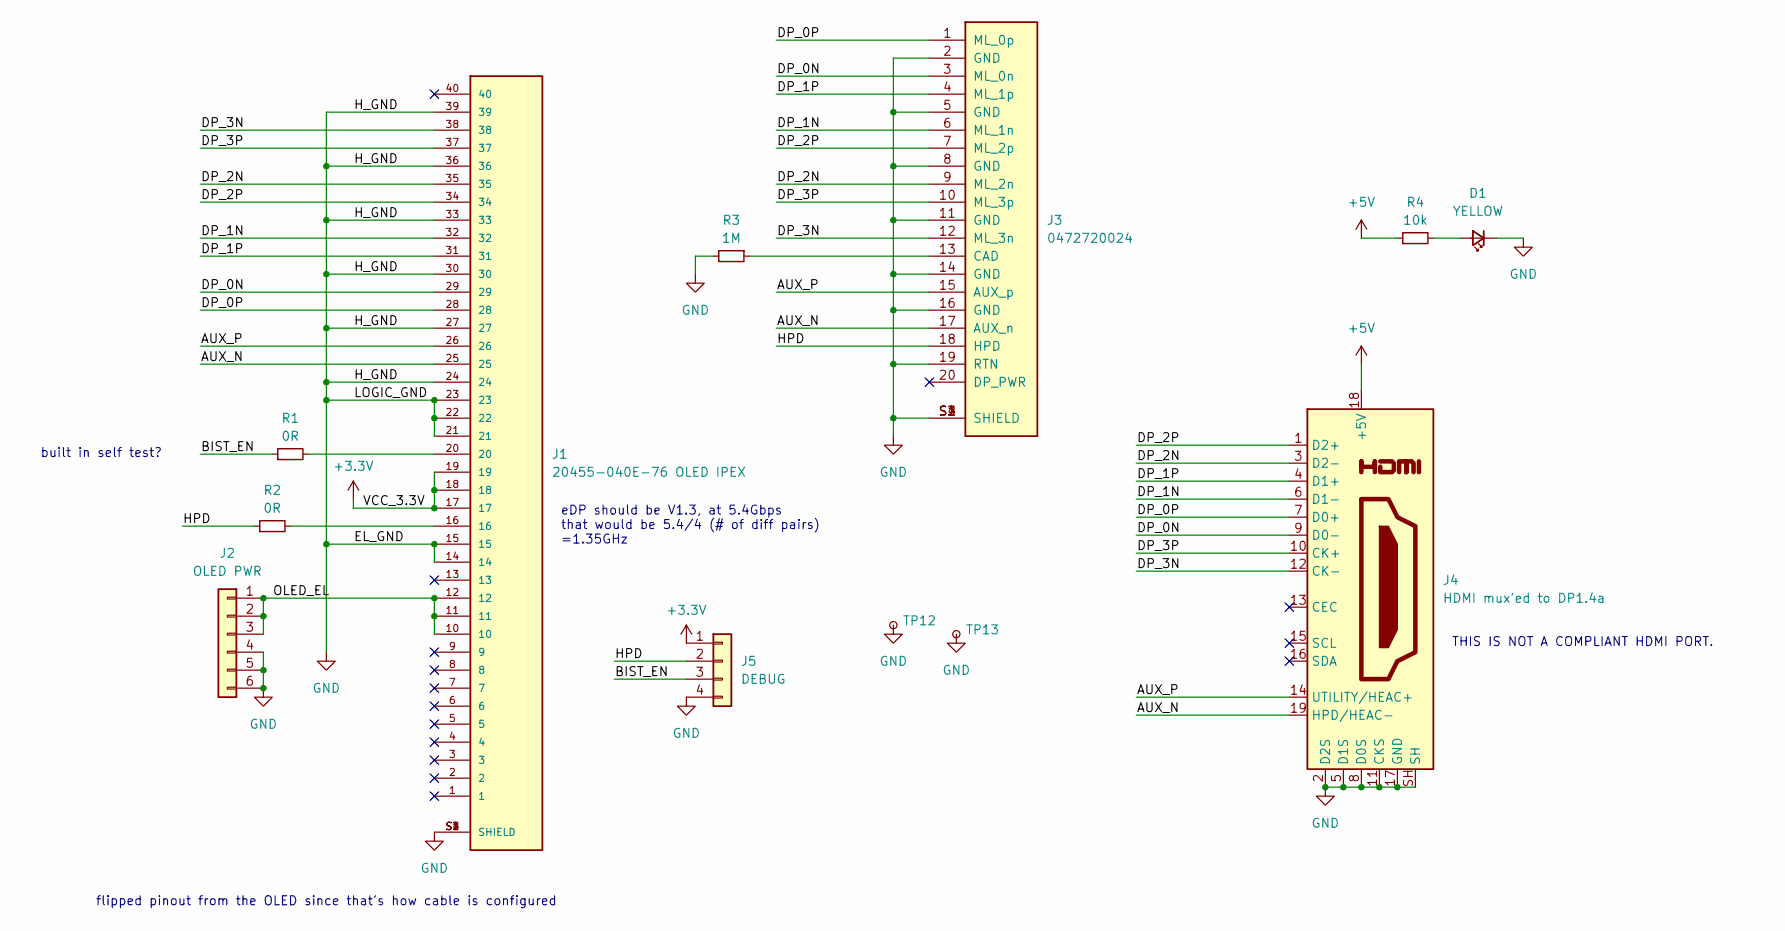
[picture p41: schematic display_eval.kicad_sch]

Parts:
D1: YELLOW; LED_0603_1608Metric; LCSC C2296
J1: 20455-040E-76 OLED IPEX; IPEX_20455-040E-76; LCSC C7527731
J2: OLED PWR; PinHeader_1x06_P2.54mm_Vertical
J3: 0472720024; MOLEX_0472720024; PARTREV D; LCSC C711350
J4: HDMI mux'ed to DP1.4a; HDMI_A_Molex_208658-1001_Horizontal; LCSC C720616
J5: DEBUG; PinHeader_1x04_P2.54mm_Vertical
R1: 0R; R_0603_1608Metric
R2: 0R; R_0603_1608Metric; LCSC C21189
R3: 1M; R_0603_1608Metric; LCSC C22935
R4: 10k; R_0603_1608Metric; LCSC C25804
TP12, TP13: TestPoint_THTPad_D2.0mm_Drill1.0mm

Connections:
+3.3V: J1.17, J1.18, J1.19, J5.1
+5V: J4.18 (+5V), R4.1
/AUX_N: J1.25, J3.17 (AUX_n), J4.19 (HPD/HEAC-)
/AUX_P: J1.26, J3.15 (AUX_p), J4.14 (UTILITY/HEAC+)
/BIST_EN: J5.3, R1.1
/DP_0N: J1.29, J3.3 (ML_0n), J4.9 (D0-)
/DP_0P: J1.28, J3.1 (ML_0p), J4.7 (D0+)
/DP_1N: J1.32, J3.6 (ML_1n), J4.6 (D1-)
/DP_1P: J1.31, J3.4 (ML_1p), J4.4 (D1+)
/DP_2N: J1.35, J3.9 (ML_2n), J4.3 (D2-)
/DP_2P: J1.34, J3.7 (ML_2p), J4.1 (D2+)
/DP_3N: J1.38, J3.12 (ML_3n), J4.12 (CK-)
/DP_3P: J1.37, J3.10 (ML_3p), J4.10 (CK+)
/HPD: J3.18 (HPD), J5.2, R2.1
/OLED_EL: J1.10, J1.11, J1.12, J2.1, J2.2, J2.3
GND: D1.1 (K), J1.14, J1.15, J1.21, J1.22, J1.23, J1.24, J1.27, J1.30, J1.33, J1.36, J1.39, J1.S1 (SHIELD), J1.S2 (SHIELD), J1.S3 (SHIELD), J1.S4 (SHIELD), J2.4, J2.5, J2.6, J3.2 (GND), J3.5 (GND), J3.8 (GND), J3.11 (GND), J3.14 (GND), J3.16 (GND), J3.19 (RTN), J3.S1 (SHIELD), J3.S2 (SHIELD), J3.S3 (SHIELD), J3.S4 (SHIELD), J4.2 (D2S), J4.5 (D1S), J4.8 (D0S), J4.11 (CKS), J4.17 (GND), J4.SH, J5.4, R3.2, TP12.1, TP13.1
unnamed: D1.2 (A), R4.2
unnamed: J1.16, R2.2
unnamed: J1.20, R1.2
unnamed: J3.13 (CAD), R3.1

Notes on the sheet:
THIS IS NOT A COMPLIANT HDMI PORT.
eDP should be V1.3, at 5.4Gbps that would be 5.4/4 (# of diff pairs) =1.35GHz
flipped pinout from the OLED since that's how cable is configured
built in self test?

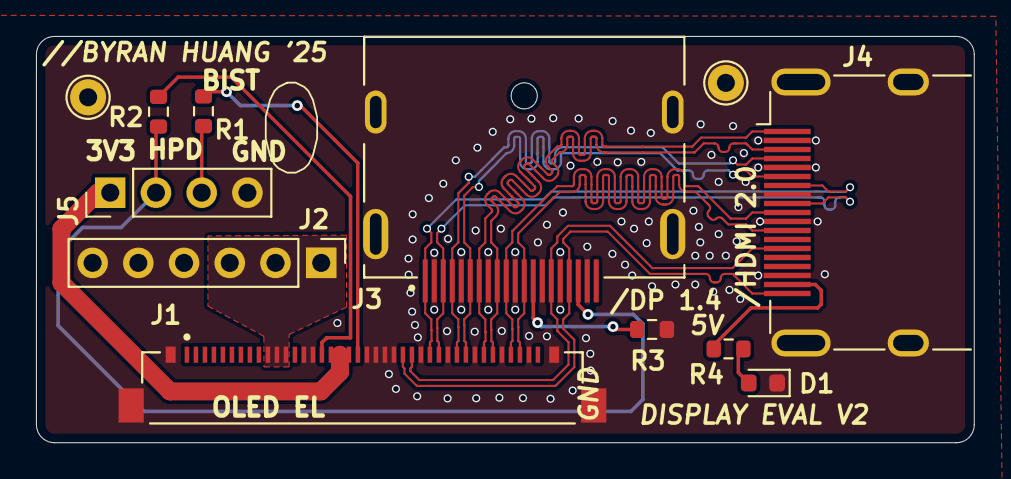
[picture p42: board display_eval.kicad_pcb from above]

Board: 4 copper layers, 52.1 x 22.6 mm, 12 parts (0 on the bottom side), 20 nets.

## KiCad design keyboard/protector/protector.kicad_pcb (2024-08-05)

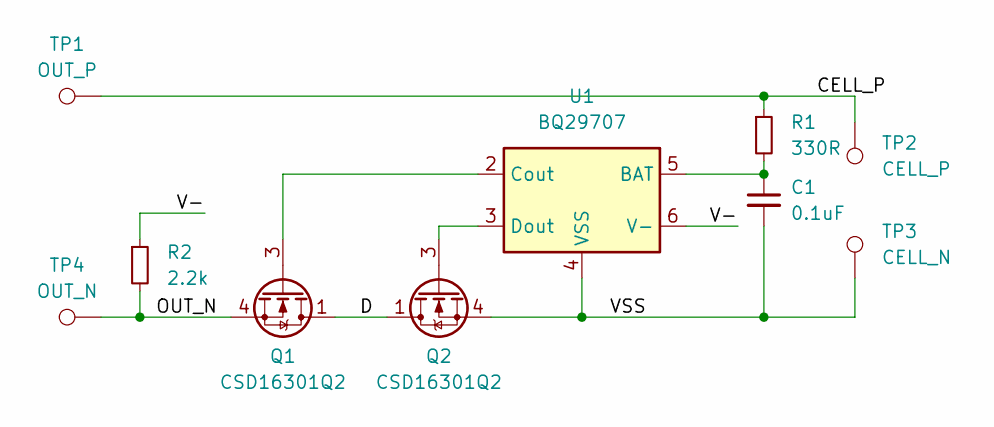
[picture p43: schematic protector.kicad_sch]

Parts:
C1: 0.1uF; C_0402_1005Metric; LCSC C307331
Q1, Q2: CSD16301Q2; Texas_DQK; LCSC C140340
R1: 330R; R_0402_1005Metric; LCSC C25104
R2: 2.2k; R_0402_1005Metric; LCSC C25879
TP1: OUT_P; TestPoint_Pad_4.0x4.0mm
TP2: CELL_P; TestPoint_Pad_4.0x4.0mm
TP3: CELL_N; TestPoint_Pad_4.0x4.0mm
TP4: OUT_N; TestPoint_Pad_4.0x4.0mm
U1: BQ29707; WSON-6_1.5x1.5mm_P0.5mm; LCSC C2864878

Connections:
/CELL_P: R1.1, TP1.1, TP2.1
/D: Q1.1 (D), Q1.2 (D), Q1.5 (D), Q1.6 (D), Q1.8 (D), Q2.1 (D), Q2.2 (D), Q2.5 (D), Q2.6 (D), Q2.8 (D)
/OUT_N: Q1.4 (S), Q1.7 (S), R2.2, TP4.1
/V-: R2.1, U1.6 (V-)
/VSS: C1.2, Q2.4 (S), Q2.7 (S), TP3.1, U1.4 (VSS)
unnamed: Q1.3 (G), U1.2 (Cout)
unnamed: Q2.3 (G), U1.3 (Dout)
unnamed: C1.1, R1.2, U1.5 (BAT)



Board: 2 copper layers, 32.2 x 15.4 mm, 10 parts (4 on the bottom side), 8 nets.

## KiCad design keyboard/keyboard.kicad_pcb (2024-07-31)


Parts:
D4, D5, D6, D7, D8, D9, D10, D11, D12, D13, D14, D15, D16, D18, D19, D20, D21, D22, D23, D24, D25, D26, D27, D28, D29, D30, D31, D32, D33, D34, D35, D36, D37, D38, D39, D40, D41, D42, D43, D44, D45, D46, D47, D48, D49, D50, D51, D52, D53, D54, D55, D56, D57, D58, D59, D60, D61, D62, D63, D64, D65, D66, D67, D68, D69, D70, D71, D72, D73, D74, D75, D76, D77, D78, D79, D80, D81, D82: D; D_SOD-523
K1: Esc; Cherry_ULP_SMD
K2: F1; Cherry_ULP_SMD
K3: F2; Cherry_ULP_SMD
K4: F3; Cherry_ULP_SMD
K5: F4; Cherry_ULP_SMD
K6: F5; Cherry_ULP_SMD
K7: F6; Cherry_ULP_SMD
K8: F7; Cherry_ULP_SMD
K9: F8; Cherry_ULP_SMD
K10: F9; Cherry_ULP_SMD
K11: F10; Cherry_ULP_SMD
K12: F11; Cherry_ULP_SMD
K13: F12; Cherry_ULP_SMD
K15: ~~,`; Cherry_ULP_SMD
K16: !,1; Cherry_ULP_SMD
K17: @,2; Cherry_ULP_SMD
K18: #,3; Cherry_ULP_SMD
K19: $,4; Cherry_ULP_SMD
K20: %,5; Cherry_ULP_SMD
K21: ^,6; Cherry_ULP_SMD
K22: &,7; Cherry_ULP_SMD
K23: *,8; Cherry_ULP_SMD
K24: (,9; Cherry_ULP_SMD
K25: ),0; Cherry_ULP_SMD
K26: _,-; Cherry_ULP_SMD
K27: +,=; Cherry_ULP_SMD
K28: Backspace; Cherry_ULP_SMD
K29: Tab; Cherry_ULP_SMD
K30: Q; Cherry_ULP_SMD
K31: W; Cherry_ULP_SMD
K32: E; Cherry_ULP_SMD
K33: R; Cherry_ULP_SMD
K34: T; Cherry_ULP_SMD
K35: Y; Cherry_ULP_SMD
K36: U; Cherry_ULP_SMD
K37: I; Cherry_ULP_SMD
K38: O; Cherry_ULP_SMD
K39: P; Cherry_ULP_SMD
K40: {,[; Cherry_ULP_SMD
K41: },]; Cherry_ULP_SMD
K42: |,\; Cherry_ULP_SMD
K43: Caps Lock; Cherry_ULP_SMD
K44: A; Cherry_ULP_SMD
K45: S; Cherry_ULP_SMD
K46: D; Cherry_ULP_SMD
K47: F; Cherry_ULP_SMD
K48: G; Cherry_ULP_SMD
K49: H; Cherry_ULP_SMD
K50: J; Cherry_ULP_SMD
K51: K; Cherry_ULP_SMD
K52: L; Cherry_ULP_SMD
K53: :,;; Cherry_ULP_SMD
K54: ",'; Cherry_ULP_SMD
K55: Enter; Cherry_ULP_SMD
K56, K68: Shift; Cherry_ULP_SMD
K57: Z; Cherry_ULP_SMD
K58: X; Cherry_ULP_SMD
K59: C; Cherry_ULP_SMD
K60: V; Cherry_ULP_SMD
K61: B; Cherry_ULP_SMD
K62: N; Cherry_ULP_SMD
K63: M; Cherry_ULP_SMD
K64: <,,; Cherry_ULP_SMD
K65: >,.; Cherry_ULP_SMD
K66: ?,/; Cherry_ULP_SMD
K67: ↑; Cherry_ULP_SMD
K69: Fn; Cherry_ULP_SMD
K70: Ctrl; Cherry_ULP_SMD
K71, K76: Alt; Cherry_ULP_SMD
K72, K75: Meta; Cherry_ULP_SMD
K73, K74: Space; Cherry_ULP_SMD
K77: ←; Cherry_ULP_SMD
K78: ↓; Cherry_ULP_SMD
K79: →; Cherry_ULP_SMD

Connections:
/Key Matrix/Col_0: K1.1, K15.1, K29.1, K43.1, K56.1, K69.1; also elsewhere on the board
/Key Matrix/Col_1: K2.1, K16.1, K30.1, K44.1, K57.1, K70.1; also elsewhere on the board
/Key Matrix/Col_2: K3.1, K17.1, K31.1, K45.1, K58.1, K71.1; also elsewhere on the board
/Key Matrix/Col_3: K4.1, K18.1, K32.1, K46.1, K59.1, K72.1; also elsewhere on the board
/Key Matrix/Col_4: K5.1, K19.1, K33.1, K47.1, K60.1, K73.1; also elsewhere on the board
/Key Matrix/Col_5: K6.1, K20.1, K34.1, K48.1, K61.1, K74.1; also elsewhere on the board
/Key Matrix/Col_6: K7.1, K21.1, K35.1, K49.1, K62.1, K75.1; also elsewhere on the board
/Key Matrix/Col_7: K8.1, K22.1, K36.1, K50.1, K63.1, K76.1; also elsewhere on the board
/Key Matrix/Col_8: K9.1, K23.1, K37.1, K51.1, K64.1, K77.1; also elsewhere on the board
/Key Matrix/Col_9: K10.1, K24.1, K38.1, K52.1, K65.1, K78.1; also elsewhere on the board
/Key Matrix/Col_10: K11.1, K25.1, K39.1, K53.1, K66.1, K79.1; also elsewhere on the board
/Key Matrix/Col_11: K12.1, K26.1, K40.1, K54.1, K67.1; also elsewhere on the board
/Key Matrix/Col_12: K13.1, K27.1, K41.1, K55.1, K68.1; also elsewhere on the board
/Key Matrix/Col_13: K28.1, K42.1; also elsewhere on the board
/Key Matrix/Row_0: D4.1 (K), D5.1 (K), D6.1 (K), D7.1 (K), D8.1 (K), D9.1 (K), D10.1 (K), D11.1 (K), D12.1 (K), D13.1 (K), D14.1 (K), D15.1 (K), D16.1 (K); also elsewhere on the board
/Key Matrix/Row_1: D18.1 (K), D19.1 (K), D20.1 (K), D21.1 (K), D22.1 (K), D23.1 (K), D24.1 (K), D25.1 (K), D26.1 (K), D27.1 (K), D28.1 (K), D29.1 (K), D30.1 (K), D31.1 (K); also elsewhere on the board
/Key Matrix/Row_2: D32.1 (K), D33.1 (K), D34.1 (K), D35.1 (K), D36.1 (K), D37.1 (K), D38.1 (K), D39.1 (K), D40.1 (K), D41.1 (K), D42.1 (K), D43.1 (K), D44.1 (K), D45.1 (K); also elsewhere on the board
/Key Matrix/Row_3: D46.1 (K), D47.1 (K), D48.1 (K), D49.1 (K), D50.1 (K), D51.1 (K), D52.1 (K), D53.1 (K), D54.1 (K), D55.1 (K), D56.1 (K), D57.1 (K), D58.1 (K); also elsewhere on the board
/Key Matrix/Row_4: D59.1 (K), D60.1 (K), D61.1 (K), D62.1 (K), D63.1 (K), D64.1 (K), D65.1 (K), D66.1 (K), D67.1 (K), D68.1 (K), D69.1 (K), D70.1 (K), D71.1 (K); also elsewhere on the board
/Key Matrix/Row_5: D72.1 (K), D73.1 (K), D74.1 (K), D75.1 (K), D76.1 (K), D77.1 (K), D78.1 (K), D79.1 (K), D80.1 (K), D81.1 (K), D82.1 (K); also elsewhere on the board
unnamed: D4.2 (A), K1.2
unnamed: D5.2 (A), K2.2
unnamed: D6.2 (A), K3.2
unnamed: D7.2 (A), K4.2
unnamed: D8.2 (A), K5.2
unnamed: D9.2 (A), K6.2
unnamed: D10.2 (A), K7.2
unnamed: D11.2 (A), K8.2
unnamed: D12.2 (A), K9.2
unnamed: D13.2 (A), K10.2
unnamed: D14.2 (A), K11.2
unnamed: D15.2 (A), K12.2
unnamed: D16.2 (A), K13.2
unnamed: D18.2 (A), K15.2
unnamed: D19.2 (A), K16.2
unnamed: D20.2 (A), K17.2
unnamed: D21.2 (A), K18.2
unnamed: D22.2 (A), K19.2
unnamed: D23.2 (A), K20.2
unnamed: D24.2 (A), K21.2
unnamed: D25.2 (A), K22.2
unnamed: D26.2 (A), K23.2
unnamed: D27.2 (A), K24.2
unnamed: D28.2 (A), K25.2
unnamed: D29.2 (A), K26.2
unnamed: D30.2 (A), K27.2
unnamed: D31.2 (A), K28.2
unnamed: D32.2 (A), K29.2
unnamed: D33.2 (A), K30.2
unnamed: D34.2 (A), K31.2
unnamed: D35.2 (A), K32.2
unnamed: D36.2 (A), K33.2
unnamed: D37.2 (A), K34.2
unnamed: D38.2 (A), K35.2
unnamed: D39.2 (A), K36.2
unnamed: D40.2 (A), K37.2
unnamed: D41.2 (A), K38.2
unnamed: D42.2 (A), K39.2
unnamed: D43.2 (A), K40.2
unnamed: D44.2 (A), K41.2
unnamed: D45.2 (A), K42.2
unnamed: D46.2 (A), K43.2
unnamed: D47.2 (A), K44.2
unnamed: D48.2 (A), K45.2
unnamed: D49.2 (A), K46.2
unnamed: D50.2 (A), K47.2
unnamed: D51.2 (A), K48.2
unnamed: D52.2 (A), K49.2
unnamed: D53.2 (A), K50.2
unnamed: D54.2 (A), K51.2
unnamed: D55.2 (A), K52.2
unnamed: D56.2 (A), K53.2
unnamed: D57.2 (A), K54.2
unnamed: D58.2 (A), K55.2
unnamed: D59.2 (A), K56.2
unnamed: D60.2 (A), K57.2
unnamed: D61.2 (A), K58.2
unnamed: D62.2 (A), K59.2
unnamed: D63.2 (A), K60.2
unnamed: D64.2 (A), K61.2
unnamed: D65.2 (A), K62.2
unnamed: D66.2 (A), K63.2
unnamed: D67.2 (A), K64.2
unnamed: D68.2 (A), K65.2
unnamed: D69.2 (A), K66.2
unnamed: D70.2 (A), K67.2
unnamed: D71.2 (A), K68.2
unnamed: D72.2 (A), K69.2
unnamed: D73.2 (A), K70.2
unnamed: D74.2 (A), K71.2
unnamed: D75.2 (A), K72.2
unnamed: D76.2 (A), K73.2
unnamed: D77.2 (A), K74.2
unnamed: D78.2 (A), K75.2
unnamed: D79.2 (A), K76.2
unnamed: D80.2 (A), K77.2
unnamed: D81.2 (A), K78.2
unnamed: D82.2 (A), K79.2

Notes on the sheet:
Diodes: C7420320
Generated with @jeroen94704's klepcbgen https://github.com/jeroen94704/klepcbgen
Keycaps by @CairnTech on GitLab https://gitlab.cairn-devices.eu/cairntech/cairn-mesa-key


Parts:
AE1: Antenna; 2.4GHz-meander-antenna-v2
C1, C4, C13, C19: 4.7uF; C_0402_1005Metric; Manufacturer Part CL05A475KP5NRNC; LCSC Part C368809
C2, C14, C15, C20: 1uF; C_0402_1005Metric; Manufacturer Part CL05A105KO5NNNC; LCSC Part C52923
C3: 47nF; C_0402_1005Metric; Manufacturer Part CL05B473KO5NNNC; LCSC Part C307434
C5: 1nF; C_0402_1005Metric; Manufacturer Part CL05B102KB5NNNC; LCSC Part C14442
C6: 100pF; C_0402_1005Metric; Manufacturer Part CL05C101JB5NNNC; LCSC Part C26409
C7, C16, C17, C18: 100nF; C_0402_1005Metric; Manufacturer Part CL05B104KA5NNNC; LCSC Part C1525
C8, C9, C21, C22: 15pF; C_0402_1005Metric; Manufacturer Part CL05C150JB51PNC; LCSC Part C307341
C10: 1.5pF; C_0402_1005Metric; Manufacturer Part CL05C1R5CB5NNNC; LCSC Part C170150
C11, C12: 1pF; C_0402_1005Metric; Manufacturer Part CL05C010CB5NNNC; LCSC Part C371977
C23: 10nF; C_0402_1005Metric; Manufacturer Part CL05B103KB5NNNC; LCSC Part C15195
C24: 1000pF/NC; C_0402_1005Metric
D1: CHG; LED_0603_1608Metric; Manufacturer Part 19-217/S2C-AQ1R1B/3T; LCSC Part C160478
D2: B5819W SL; D_SOD-323; Manufacturer Part PMEG4010CEJ; LCSC Part C50704
D3: BLUE; LED_0603_1608Metric; Manufacturer Part 19-217/BHC-ZL1M2RY/3T; LCSC Part C146215
F1: 500mA; Fuse_0402_1005Metric; Manufacturer Part 0402L050SLKR; LCSC Part C206938
J1: BATT; PinHeader_1x02_P2.54mm_Vertical; not fitted
J2: USB POGO; PinHeader_1x04_P2.54mm_Vertical; not fitted
J3: Debug; PinHeader_1x04_P2.54mm_Vertical; not fitted
L1: 15nH; L_0402_1005Metric; Manufacturer Part MLG1005S15NJT000; LCSC Part C76763
L2, L3: 10uH; L_0603_1608Metric; Manufacturer Part MLF1608E100KTD00; LCSC Part C76732
L4: 3.9nH; L_0402_1005Metric; Manufacturer Part MLG1005S3N9BT000; LCSC Part C76775
NT1: NetTie_2; net-tie-2-tiny
P1: USB-C; USB_C_Receptacle_HRO_TYPE-C-31-M-12
R1: 0R; R_0402_1005Metric; Manufacturer Part RC0402FR-070RL; LCSC Part C106231
R2, R4: 10k; R_0402_1005Metric; Manufacturer Part RC0402FR-0710KL; LCSC Part C60490
R3: 2.7k; R_0402_1005Metric; Manufacturer Part RC0402FR-0710KL; LCSC Part C60490
R5: 1.5k; R_0402_1005Metric; Manufacturer Part RC0402FR-071K5L; LCSC Part C114759
R6, R7: 5.1k; R_0402_1005Metric; Manufacturer Part RC0402FR-075K1L; LCSC Part C105872
R8, R9: 2M; R_0402_1005Metric; Manufacturer Part RC0402FR-072ML; LCSC Part C138014
R10: 10M; R_0402_1005Metric; Manufacturer Part RC0402FR-0710ML; LCSC Part C138067
R11: 1M; R_0402_1005Metric
SW1: Reset; SW_Push_1P1T_XKB_TS-1187A
U1: BQ21040DBVR; SOT95P280X145-6N
U2: nRF52840; Nordic_AQFN-73-1EP_7x7mm_P0.5mm; Manufacturer Part NRF52840-QIAA-R; LCSC Part C1851953
U3: ESDR0502NMUTAG; UDFN-6_1.2x1.0mm_P0.4mm; Manufacturer Part ESDR0502NMUTBG; LCSC Part C327480
Y1: 32.768 kHz; Crystal_SMD_2012-2Pin_2.0x1.2mm; Manufacturer Part SC20S-12.5PF20PPM; LCSC Part C97607
Y2: 32MHz; Crystal_SMD_2016-4Pin_2.0x1.6mm; Manufacturer Part Q22FA1280001800; LCSC Part C2965584

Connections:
/Key Matrix/Col_0: U2.U1 (TRACEDATA1/P0.12); also elsewhere on the board
/Key Matrix/Col_1: U2.A8 (AIN7/P0.31); also elsewhere on the board
/Key Matrix/Col_2: U2.A10 (AIN5/P0.29); also elsewhere on the board
/Key Matrix/Col_3: U2.A12 (AIN0/P0.02); also elsewhere on the board
/Key Matrix/Col_4: U2.A14 (P1.15); also elsewhere on the board
/Key Matrix/Col_5: U2.A16 (P1.13); also elsewhere on the board
/Key Matrix/Col_6: U2.A20 (P1.10); also elsewhere on the board
/Key Matrix/Col_7: U2.J24 (NFC2/P0.10); also elsewhere on the board
/Key Matrix/Col_8: U2.L24 (NFC1/P0.09); also elsewhere on the board
/Key Matrix/Col_9: U2.R24 (P1.06); also elsewhere on the board
/Key Matrix/Col_10: U2.U24 (P1.04); also elsewhere on the board
/Key Matrix/Col_11: U2.W24 (P1.02); also elsewhere on the board
/Key Matrix/Col_12: U2.L1 (P0.06); also elsewhere on the board
/Key Matrix/Col_13: U2.N1 (P0.08); also elsewhere on the board
/Key Matrix/Row_0: U2.AD8 (P0.13); also elsewhere on the board
/Key Matrix/Row_1: U2.AD12 (P0.17); also elsewhere on the board
/Key Matrix/Row_2: U2.AD16 (P0.20); also elsewhere on the board
/Key Matrix/Row_3: U2.AD18 (P0.22); also elsewhere on the board
/Key Matrix/Row_4: U2.AD20 (P0.24); also elsewhere on the board
/Key Matrix/Row_5: U2.AC21 (P0.25); also elsewhere on the board
/nRF52840/ANT: AE1.1 (A), C10.2, R1.2
/nRF52840/CC1: P1.A5 (CC), R6.1
/nRF52840/CC2: P1.B5 (VCONN), R7.1
BAT_VOLT: C23.2, R9.2, R10.1, U2.J1 (AIN2/P0.04)
BLUE_LED: D3.2 (A), U2.AD10 (P0.15)
GND: C1.1, C2.1, C3.1, C4.2, C5.2, C6.2, C7.2, C8.1, C9.1, C10.1, C11.1, C13.1, C14.2, C15.2, C16.1, C17.1, C18.1, C19.1, C20.1, C21.2, C22.2, C23.1, C24.2, J1.2, J2.4, J3.4, NT1.2, P1.A1 (GND), P1.A12 (GND), P1.B1 (GND), P1.B12 (GND), R3.1, R4.1, R5.1, R6.2, R7.2, R10.2, R11.1, SW1.2, U1.5 (GND), U2.B7 (VSS), U2.EP (VSS), U3.1 (GND), Y2.2, Y2.4
unnamed: C11.2, L4.1, R1.1
unnamed: D1.2 (A), R2.2
unnamed: D1.1 (K), U1.3 (~CHG)
unnamed: D2.1 (K), F1.2
unnamed: D3.1 (K), R5.2
unnamed: L1.2, L2.1
unnamed: C24.1, P1.S1 (SHIELD), R11.2
unnamed: R8.2, R9.1
unnamed: R3.2, U1.4 (ISET)
unnamed: R4.2, U1.1 (TS)
unnamed: C15.1, F1.1, U1.6 (VIN)
unnamed: C12.2, L4.2, U2.H23 (ANT)
unnamed: L2.2, U2.B3 (DCC)
unnamed: L3.2, U2.AB2 (DCCH)
unnamed: C7.1, U2.C1 (DEC1)
unnamed: C6.1, U2.D23 (DEC3)
unnamed: C2.2, C3.2, L1.1, U2.B5 (DEC4), U2.E24 (DEC6)
unnamed: C5.1, U2.N24 (DEC5)
unnamed: C4.1, U2.AC5 (DECUSB)
unnamed: C21.1, U2.B24 (XC1), Y2.1
unnamed: C22.1, U2.A23 (XC2), Y2.3
unnamed: C8.2, U2.D2 (XL1/P0.00), Y1.1
unnamed: C9.2, U2.F2 (XL2/P0.01), Y1.2
RESET: SW1.1, U2.AC9 (P0.14), U2.AC11 (P0.16), U2.AC13 (P0.18/~RESET)
SWC: J3.1, U2.AA24 (SWDCLK)
SWD: J3.2, U2.AC24 (SWDIO)
SWO: J3.3, U2.AD22 (TRACEDATA0/P1.00)
USB_D+: J2.2, P1.A6 (D+), P1.B6 (D+), U2.AD6 (D+), U3.5 (D+)
USB_D-: J2.3, P1.A7 (D-), P1.B7 (D-), U2.AD4 (D-), U3.6 (VBUS)
VBAT: C13.2, C14.1, J1.1, R2.1, R8.1, U1.2 (OUT), U2.Y2 (VDDH)
VBUS: C1.2, D2.2 (A), J2.1, P1.A4 (VBUS), P1.A9 (VBUS), P1.B4 (VBUS), P1.B9 (VBUS), U2.AD2 (VBUS), U3.4 (D-)
VDD_NRF: C16.2, C17.2, C18.2, C19.2, C20.2, L3.1, U2.A22 (VDD), U2.AD14 (VDD), U2.AD23 (VDD), U2.B1 (VDD), U2.W1 (VDD)
VSS_PA: C12.1, NT1.1, U2.F23 (VSS_PA)

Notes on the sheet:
C_{L} = 12pF
C_{L} = 12.5pF
Battery Voltage Divider
ISET: 540/2700 = 200mA
Decoupling Capacitors
USB Connector + TVS
reference configuration 4
Status LED
V_{f} < 3.0V


Board: 2 copper layers, 258.4 x 104.6 mm, 211 parts (0 on the bottom side), 137 nets.

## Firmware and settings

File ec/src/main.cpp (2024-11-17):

#include <Wire.h>
#include <Arduino.h>
#include "Adafruit_HUSB238.h"
#include "LTC2943.h"
#include "BQ25713.h"
#include <EEPROM.h>

#define LED1 12
#define LED2 13
#define LED3 14
#define LED4 15
#define LED5 16

#define BQ25713_IBAT 11
#define BQ25713_IADPT 10
#define BQ77915_CBI 9
#define BQ77915_PRES 8
#define BQ25713_CMPOUT 7
#define BQ25713_EN_OTG 6
#define BQ25713_CHRG_OK 5
#define BQ25713_PROCHOT_N 4
#define LTC2943_ALCC 3

Adafruit_HUSB238 husb238;

uint16_t charge;
uint16_t current;
uint16_t temperature;
uint16_t voltage;

// Function to read a 16-bit register
uint16_t readRegister(uint8_t reg)
{
    Wire.beginTransmission(BQ25713_ADDRESS);
    Wire.write(reg); // Send register address
    Wire.endTransmission(false);

    Wire.requestFrom(BQ25713_ADDRESS, 1);
    return Wire.read(); // Combine high and low byte
}

void debugPrint(String info, uint8_t data)
{
    Serial.print(info);
    Serial.print("0x");
    Serial.print(data, HEX);
    Serial.print(", 0b");
    Serial.print(data, BIN);
    Serial.print(", ");
    Serial.print(data, DEC);
    Serial.println();
    Serial.println();
}

// Function to write a 16-bit value to consecutive I2C registers
void writeRegister16(uint8_t lsbReg, uint16_t data)
{
    Wire.beginTransmission(BQ25713_ADDRESS);
    Wire.write(lsbReg + 1);         // Write to MSB register first
    Wire.write((data >> 8) & 0xFF); // Write MSB
    Wire.endTransmission();

    Wire.beginTransmission(BQ25713_ADDRESS);
    Wire.write(lsbReg);      // Write to LSB register
    Wire.write(data & 0xFF); // Write LSB
    Wire.endTransmission();
}

void chargingInit() {
    // 0x020E to register 0x00
    writeRegister16(CHARGEOPTION0_LSB, 0x820E);

    // ADC configurations
    writeRegister16(ADCOPTION_LSB, 0xa0ff);

    // charging
    writeRegister16(CHARGECURRENT_LSB, 0x0800);

    // set input current to
    writeRegister16(IIN_HOST_LSB, 0x4000);

    writeRegister16(CHARGEOPTION1_LSB, 0x218);
}

void setup()
{
    Serial.begin(115200);
    Wire.begin(2, 1);
    EEPROM.begin(512); // half kb simulated flash

    pinMode(LED1, OUTPUT);
    pinMode(LED2, OUTPUT);
    pinMode(LED3, OUTPUT);
    pinMode(LED4, OUTPUT);
    pinMode(LED5, OUTPUT);

    digitalWrite(LED1, LOW);
    digitalWrite(LED2, LOW);
    digitalWrite(LED3, LOW);
    digitalWrite(LED4, LOW);
    digitalWrite(LED5, LOW);

    while (!Serial)
        delay(1);

    LTC2943_write(LTC2943_I2C_ADDRESS, LTC2943_CONTROL_REG, (LTC2943_AUTOMATIC_MODE | LTC2943_PRESCALAR_M_4096));

    chargingInit();

    delay(1000);

    Serial.println("EEPROM Stored Value: ");
    Serial.println(EEPROM.read(0));
    uint16_t storedCharge = (EEPROM.read(0) << 8) | EEPROM.read(1);
    Serial.println(storedCharge);

    LTC2943_write_16_bits(LTC2943_I2C_ADDRESS, LTC2943_ACCUM_CHARGE_MSB_REG, storedCharge);
}

bool vbusConnected = false;

void loop()
{
    delay(1000); // Add a delay to prevent flooding the serial output
    Serial.println(F("----------------------------------------------"));

    Wire.beginTransmission(HUSB238_I2CADDR_DEFAULT);
    int transmissionResult = Wire.endTransmission();

    Serial.print("HUSB Connected: ");
    Serial.println(transmissionResult == 0 ? "true" : "false");

    if (transmissionResult == 0 && !vbusConnected)
    {
        delay(500);

        husb238.begin(HUSB238_I2CADDR_DEFAULT, &Wire);
        husb238.selectPD(PD_SRC_20V);
        husb238.requestPD();

        Serial.println("REQUESTED 20V");
        Serial.println(husb238.isVoltageDetected(PD_SRC_20V));

        delay(100);
        chargingInit();

        vbusConnected = true;
    }
    else if (vbusConnected && transmissionResult != 0)
    {
        vbusConnected = false;
    }

    Serial.print("VBUS Connected: ");
    Serial.println(vbusConnected);

    Wire.beginTransmission(BQ25713_ADDRESS);
    transmissionResult = Wire.endTransmission();

    if (transmissionResult == 0)
    {

        if ((readRegister(0x27) * 0.064) > 16)
        {
            digitalWrite(LED5, HIGH);
        }
        else
        {
            digitalWrite(LED5, LOW);
        }

        Serial.print("VBUS: ");
        Serial.println(readRegister(0x27) * 0.064);
        Serial.print("VSYS: ");
        Serial.println(readRegister(0x2D) * 0.064);
        Serial.print("VBAT: ");
        Serial.println(readRegister(0x2C) * 0.064);

        if (readRegister(0x29) > 0)
        {
            Serial.print("CHARGING: ");
            Serial.println("YES");
            digitalWrite(LED4, HIGH);
        }
        else
        {
            Serial.print("CHARGING: ");
            Serial.println("NO");
        }
    }
    else
    {
        Serial.println("BQ25713 NOT CONNECTED");
        digitalWrite(LED5, LOW);
    }

    // debugPrint("ChargerStatus 0x21:", readRegister(0x21));
    // debugPrint("ChargerStatus 0x20:", readRegister(0x20));
    // debugPrint("ChargeOption0 0x01:", readRegister(0x01));
    // debugPrint("ChargeOption0 0x00:", readRegister(0x00));
    // debugPrint("ChargeCurrent 0x03:", readRegister(0x03));
    // debugPrint("ChargeCurrent 0x02:", readRegister(0x02));
    // debugPrint("ADCOptions 0x3B:", readRegister(0x3B));
    // debugPrint("ADCOptions 0x3A:", readRegister(0x3A));
    // debugPrint("IIN_HOST 0x0F:", readRegister(IIN_HOST_MSB));
    // debugPrint("Input Current:", readRegister(ADCIINCMPIN_MSB));
    // debugPrint("CMP Voltage:", readRegister(ADCIINCMPIN_LSB));

    // debugPrint("PSYS 0x26:", readRegister(0x26));
    // debugPrint("ICHG 0x29:", readRegister(0x29));
    // debugPrint("IDCHG 0x28:", readRegister(0x28));

    LTC2943_read_16_bits(LTC2943_I2C_ADDRESS, LTC2943_VOLTAGE_MSB_REG, &voltage);
    Serial.print("VOLT: ");
    Serial.println(LTC2943_code_to_voltage(voltage), 4);

    LTC2943_read_16_bits(LTC2943_I2C_ADDRESS, LTC2943_ACCUM_CHARGE_MSB_REG, &charge);
    Serial.print("CHRG mAh: ");
    Serial.println(LTC2943_code_to_mAh(charge, 0.01, 4096), 4);

    EEPROM.write(0, (charge >> 8) & 0xFF); // Write high byte
    EEPROM.write(1, charge & 0xFF);        // Write low byte
    EEPROM.commit();

    LTC2943_read_16_bits(LTC2943_I2C_ADDRESS, LTC2943_CURRENT_MSB_REG, &current);
    Serial.print("CURR: ");
    Serial.println(LTC2943_code_to_current(current, 0.01), 4);

    LTC2943_read_16_bits(LTC2943_I2C_ADDRESS, LTC2943_TEMPERATURE_MSB_REG, &temperature);
    Serial.print("TEMP: ");
    Serial.println(LTC2943_code_to_celcius_temperature(temperature), 4);

    Serial.print("BATTERY PERCENT: ");
    Serial.println((LTC2943_code_to_mAh(charge, 0.01, 4096) * 100 / (float)4250), 0);

    if ((LTC2943_code_to_celcius_temperature(temperature), 4) >= 60)
    {
        // thermal shutdown
        writeRegister16(CHARGECURRENT_LSB, 0x0000);
    }
    else
    {
        // charging
        writeRegister16(CHARGECURRENT_LSB, 0x0800);
    }
}

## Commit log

2024-06-03 keyboard v1 halfway routed
    [key_matrix.kicad_sch, keyboard.kicad_pcb, keyboard.kicad_sch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]
2024-06-03 fully routed and fixed
    [keyboard.kicad_pcb, nRF52840.kicad_sch]
2024-06-07 trackpad solutions
    [PXM0057_PTP_Pivot_Clip.3MF, PXM0057_PTP_Pivot_Clip.STEP, PXM0057_PTP_Pivot_Clip.STL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]
2024-06-12 motherboard initial pinout and research
    [USBC0.kicad_sch, motherboard.kicad_pcb, motherboard.kicad_sch]
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2024-06-26 created haptic project
    [haptic.kicad_pcb, haptic.kicad_sch]
2024-06-26 hdmi, edp, peripheral implementations
    [USBC1.kicad_sch, buttons.kicad_sch, eDP.kicad_sch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]
2024-06-26 wip with pcie2.0 e key, ethernet, buttons and more
    [USBC0.kicad_sch, USBC1.kicad_sch, buttons.kicad_sch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]
2024-06-26 haptics wip, created encoder pcb
    [USBC0.kicad_sch, USBC1.kicad_sch, encoder.kicad_pcb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]
2024-06-29 implemented most features
    [USBC0.kicad_sch, USBC1.kicad_sch, eDP.kicad_sch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]
2024-06-29 initialized power system
    [power.kicad_pcb, power.kicad_sch]
2024-07-02 major power work
    [BQ25798.kicad_sch, LTC2943.kicad_sch, TPS54531.kicad_sch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]
2024-07-03 CAD work + documentation
    [keyboard.kicad_pcb]
2024-07-06 full cm3588 sym + fp + 3d
    [USBC0.kicad_sch, USBC1.kicad_sch, ethernet.kicad_sch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]
2024-07-06 synchronizing hierarchical pins
    [USBC0.kicad_sch, USBC1.kicad_sch, ethernet.kicad_sch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]
2024-07-07 linked all footprints
    [USBC0.kicad_sch, USBC1.kicad_sch, eDP.kicad_sch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]
2024-07-07 cost optimizations for jlc
    [USBC0.kicad_sch, USBC1.kicad_sch, ethernet.kicad_sch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]
2024-07-08 uploaded cm3588 3d model, working on audio
    [CM3588.obj, CM3588.stl, CM3588_3D.step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]
2024-07-08 added color to model
    [CM3588_3D.step]
2024-07-08 audio done
    [CM3588_3D.step, audio.kicad_sch, motherboard.kicad_pcb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]
2024-07-09 motherboard schematic done
    [USBC0.kicad_sch, USBC1.kicad_sch, audio.kicad_sch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]
2024-07-11 work preparing for routing
    [USBC0.kicad_sch, USBC1.kicad_sch, eDP.kicad_sch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]
2024-07-16 keyboard battery and pogo pin system
    [keyboard.kicad_pcb, nRF52840.kicad_sch, protector.kicad_pcb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]
2024-07-16 minor motherboard work
    [USBC0.kicad_sch, USBC1.kicad_sch, ethernet.kicad_sch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]
2024-07-16 initial motherboard layout!
    [USBC0.kicad_sch, USBC1.kicad_sch, ethernet.kicad_sch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]
2024-07-16 component placement of I/O
    [USBC0.kicad_sch, USBC1.kicad_sch, eDP.kicad_sch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]
2024-07-17 placement roughly halfway done
    [USBC0.kicad_sch, USBC1.kicad_sch, audio.kicad_sch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]
2024-07-27 layout nearing completion
    [USBC0.kicad_sch, USBC1.kicad_sch, audio.kicad_sch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]
2024-07-29 removed 2.5G ethernet
    [USBC0.kicad_sch, USBC1.kicad_sch, ethernet.kicad_sch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]
2024-07-31 created display evaluation board + layout modifications
    [USBC0.kicad_sch, USBC1.kicad_sch, audio.kicad_sch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]
2024-08-01 TAPEOUT: keyboard + protector, display + halls switch eval
    [battery_protector.kicad_sch, key_matrix.kicad_sch, keyboard.kicad_sch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]
2024-08-05 keyboard TAPEOUT and plate file finalization
    [anyon_e kb bottom AI TAPEOUT.dxf, anyon_e kb bottom center AI TAPEOUT.dxf, anyon_e kb top AI TAPEOUT.dxf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]
2024-08-05 motherboard net labeling and impedance matching
    [USBC0.kicad_sch, USBC1.kicad_sch, display_eval.kicad_pcb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]
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2024-08-19 added two more display eval test boards
    [USBC0.kicad_sch, USBC1.kicad_sch, audio.kicad_sch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]
2024-08-21 starting motherboard v0.2
    lessons from display eval v1
    [USBC0.kicad_sch, USBC1.kicad_sch, audio.kicad_sch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]
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2024-08-22 6 layer for better high speed signaling integrity
    [USBC0.kicad_sch, USBC1.kicad_sch, hdmi_tx.kicad_sch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]
2024-08-22 rerouting high speed traces
    [hdmi_tx.kicad_sch, motherboard.kicad_pcb]
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2024-08-24 v0.2 good routing checkpoint (217 unrouted)
    [USBC0.kicad_sch, USBC1.kicad_sch, audio.kicad_sch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]
2024-08-25 v0.2 75 routes left!
    [USBC0.kicad_sch, USBC1.kicad_sch, audio.kicad_sch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]
2024-08-25 v0.2 < 50 unrouted
    [USBC0.kicad_sch, USBC1.kicad_sch, motherboard.kicad_sch]
2024-08-28 v0.2 almost ready for tapeout
    [USBC0.kicad_sch, USBC1.kicad_sch, motherboard.kicad_sch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]
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2024-08-30 v0.2 submitted to production
    [USBC0.kicad_sch, USBC1.kicad_sch, hdmi_tx.kicad_sch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]
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2024-09-16 mainboard v0.3 + power WIP
    [USBC0.kicad_sch, USBC1.kicad_sch, audio.kicad_sch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]
2024-09-16 power v0.1 layout done
    [power.kicad_pcb, power.kicad_sch]
2024-09-17 power sub 50 routes
    [power.kicad_pcb, power.kicad_sch]
2024-09-18 routing complete
    routing complete
    [power.kicad_pcb]
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2024-09-21 powertrain pcb v0.1 complete
    [power.kicad_pcb]
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2024-10-05 embedded controller work
    Update power.kicad_sch
    [power.kicad_sch]
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2024-10-08 fixed pt v0.2 inductor
    [power.kicad_sch]
2024-10-14 preparing for motherboard v1.1
    [USBC0.kicad_sch, USBC1.kicad_sch, audio.kicad_sch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]
2024-10-24 cleanup and final mainboard tapeout
    [CM3588.obj, CM3588.stl, CM3588_3D.step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]
2024-10-27 v1.0 tapeout and more
    [CM3588.obj, CM3588.stl, CM3588_3D.step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]
2024-10-29 taped out switch and audio pcbs
    [audio.kicad_pcb, audio.kicad_sch, power.kicad_sch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]
2024-10-31 powertrain charging functional (balancing difficult to test)
    [power.kicad_sch]
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2024-11-16 working on ec fixes
    [main.cpp]
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
